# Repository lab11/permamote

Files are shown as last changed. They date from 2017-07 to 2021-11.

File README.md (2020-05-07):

Permamote
=========
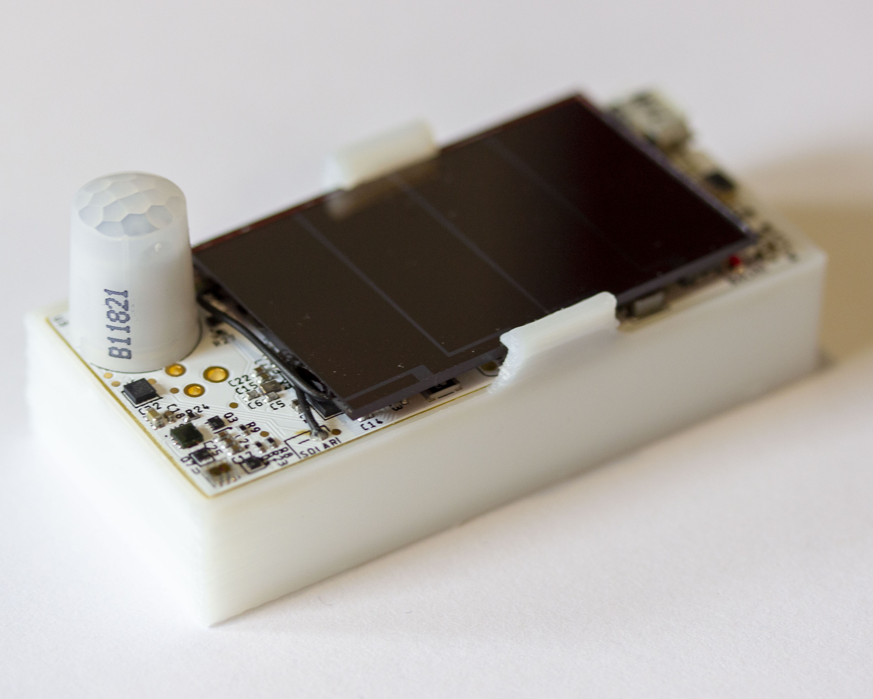
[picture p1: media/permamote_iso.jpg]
Permamote

An energy harvesting sensor mote with backing primary store and a lifetime of ≥10 years.
Permamote monitors temperature, humidity, pressure, light, light color, motion
(both PIR and with an accelerometer) and reports readings over BLE and
802.15.4/Thread.

Hardware
--------
The Permamote hardware is a small, 1 x 2.4 inch rectangular sensor board based
on the Nordic NRF52840 SoC, and the TI BQ25505 for power supply management and
energy harvesting.  Permamote also has an onboard RTC, the AB1815. The board
currently has 6 sensors:

1. Temperature and Humidity (Si7021)
2. Temperature and Pressure (MS5637)
3. Light (MAX44009)
4. Light Color (TCS34725)
5. PIR Motion (EKMB1101111)
6. Accelerometer (LIS2DW12)

The Permamote hardware is located in the [`hardware/permamote`](https://github.com/lab11/permamote/tree/master/hardware/permamote) directory, where you can find
the Eagle design files and case files.

Software
--------
The Permamote uses software located in the
[`software`](https://github.com/lab11/permamote/tree/master/software/).
directory. Follow the directions in the [nrf5x-base
Readme](https://github.com/lab11/nrf5x-base/tree/nrf52832#flash-an-application)
to get your machine set up to build and flash a Permamote.

The primary application is
[`software/apps/permamote_coap`](https://github.com/lab11/permamote/tree/master/software/apps/permamote_coap).
This application samples the
sensors and sends its data to a server running a
[coap-gateway](https://github.com/lab11/gateway/tree/thread/software/coap-gateway-mqtt)
over IP on a [Thread](https://github.com/openthread/openthread) network with a
[border router](https://github.com/openthread/borderrouter).
See the
[tutorial](https://github.com/lab11/permamote/tree/master/tutorial) to set up
your own OpenThread network.

Cloning
-------
To clone both this repository and the required submodules,
clone with the `--recurse-submodules` option:

```
git clone --recurse-submodules git@github.com:lab11/permamote.git
```

Otherwise, you can initialize the submodule and keep submodules up to
date by doing

```
git submodule update --init --recursive
```

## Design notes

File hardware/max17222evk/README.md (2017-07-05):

MAX17222 Evaluation Kit/Breakout Board
======================================

This maxim chip is a new and more efficient low power boost converter 
(80% @ < 10ua, Iq = 350na). 

We wanted an evaluation kit but none are in stock so this breakout will
serve as our evaluation kit.

We specifically want to evaluate boost efficiency, and metrics that might
allow us to use the boost converter for an iCount energy metering system.

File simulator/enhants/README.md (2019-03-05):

EnHANTs Dataset Processing
==========================

[Download](http://enhants.ee.columbia.edu/indoor-irradiance-meas) and place
measurement `.txt.` files in the `enhants_data` directory.

The `clean.py` script takes these energy traces, finds periods of missing data,
generates synthetic replacements to fill these holes, and saves them as
`.npy` objects in the `numpy_arrays` directory to be consumed by the simulator.

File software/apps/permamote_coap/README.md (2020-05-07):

Permamote Openthread COAP App
=============================

This is the default app for Permamote. It utilizes
[OpenThread](https://github.com/openthread/openthread) to establish data
backhaul over COAP and services such as NTP and DNS.
See the
[tutorial](https://github.com/lab11/permamote/tree/master/tutorial) to set up
your own OpenThread network.
This app periodically sends sensor data from the
light color, temperature,
humidity and pressure sensors. The light and motion sensor send when
changes are detected. The acceleratometer is currently not implemented. Thread
configuration, Sensor periods/backoffs, and COAP, NTP, and DNS endpoints, are
defined in
[config.h](https://github.com/lab11/permamote/blob/master/software/apps/permamote_coap/config.h).

This application is configured to use Nordic's [background
bootloader](
   https://infocenter.nordicsemi.com/topic/com.nordic.infocenter.sdk5.v15.3.0/lib_background_dfu.html
    ).
Before flashing this app, make sure to generate keys and place them in the [`software/boards/keys`](https://github.com/lab11/permamote/tree/master/software/boards/keys) directory.

To generate keys, follow Nordic's process [here](
    https://infocenter.nordicsemi.com/topic/com.nordic.infocenter.thread_zigbee.v3.0.0/thread_example_dfu.html
    ).
```
cd software/boards/keys
nrfutil keys generate private.pem
nrfutil keys display --key pk --format code private.pem --out_file public.c
```

Next, navigate to the [`permamote_coap`](https://github.com/lab11/permamote/tree/master/software/apps/permamote_coap) application and flash this app, with a device ID:
```
make flash ID=C0:98:E5:11:XX:XX
```
Replace XX:XX with your desired ID.

If you see a red LED turn on, this means the bootloader has successfully been
flashed but there is not yet a valid application installed. Check that you have
properly generated keys and that you hav e run `make clean` before flashing.

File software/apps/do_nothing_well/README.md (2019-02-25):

Do Nothing Well
===============

Turn off all sensors and enter sleep. Good for benchmarking minimum current.

As of Rev C, Permamote should have a sleep current at 1.3μA when supplying 3.3V
on the primary cell input.

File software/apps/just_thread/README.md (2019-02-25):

Permamote Thread Test
=====================

Test OpenThread on Permamote. Basically the `do_nothing_well` application, but
with OpenThread implemented as well.

Expected RTT output (`make rtt`) with a correctly configured OpenThread network should be similar to:
```
<info> app: Thread version: OPENTHREAD/20170716-01135-gedb7982f; NRF52840; Dec 11 2018 22:05:35
<info> app: Network name:   OpenThread
<info> app: Thread Channel: 25
<info> app: TX Power: 0 dBm
<info> app: Thread PANID: 0xFACE
<info> app: Thread interface has been enabled.
<info> app: 802.15.4 Channel: 25
<info> app: 802.15.4 PAN ID:  0xFACE
<info> app: rx-on-when-idle:  disabled
<info> app: State changed! Flags: 0x045F133D Current role: 1

<info> app: State changed! Flags: 0x000000E4 Current role: 2

<info> app: State changed! Flags: 0x00000200 Current role: 2

<info> app: State changed! Flags: 0x00000001 Current role: 2
```

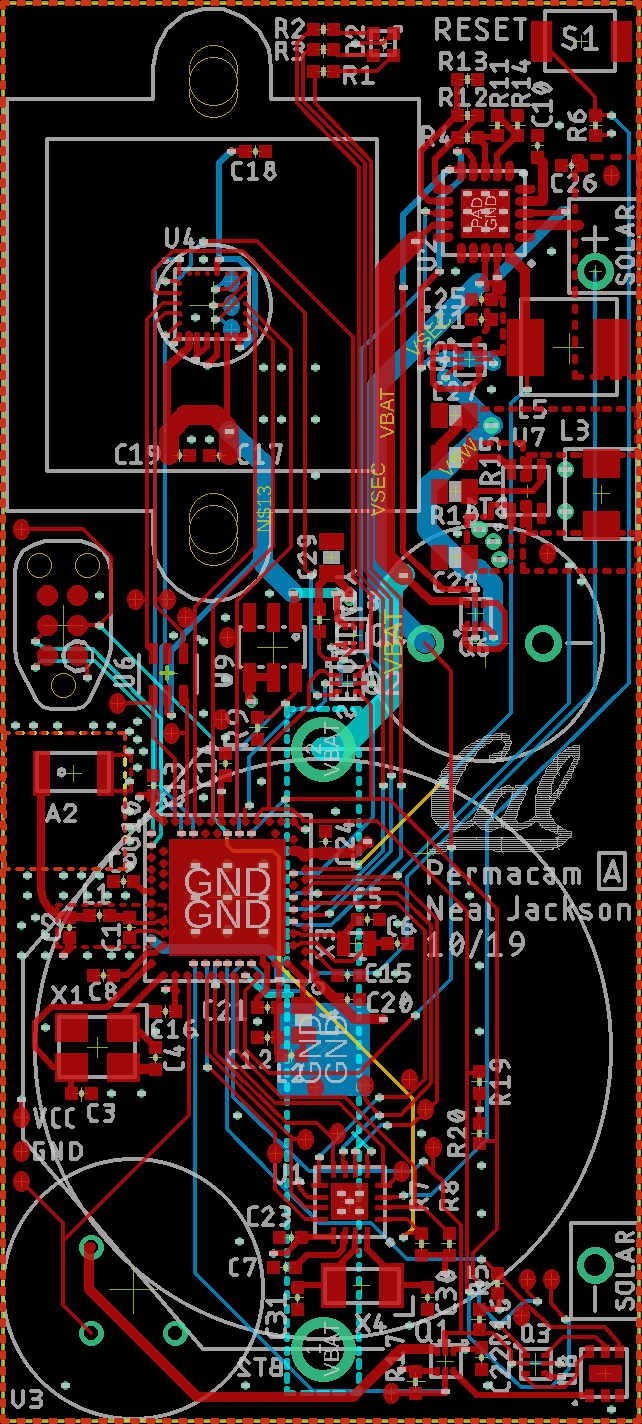
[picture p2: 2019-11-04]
hardware/permacam/rev_a/permacam_pcb.png

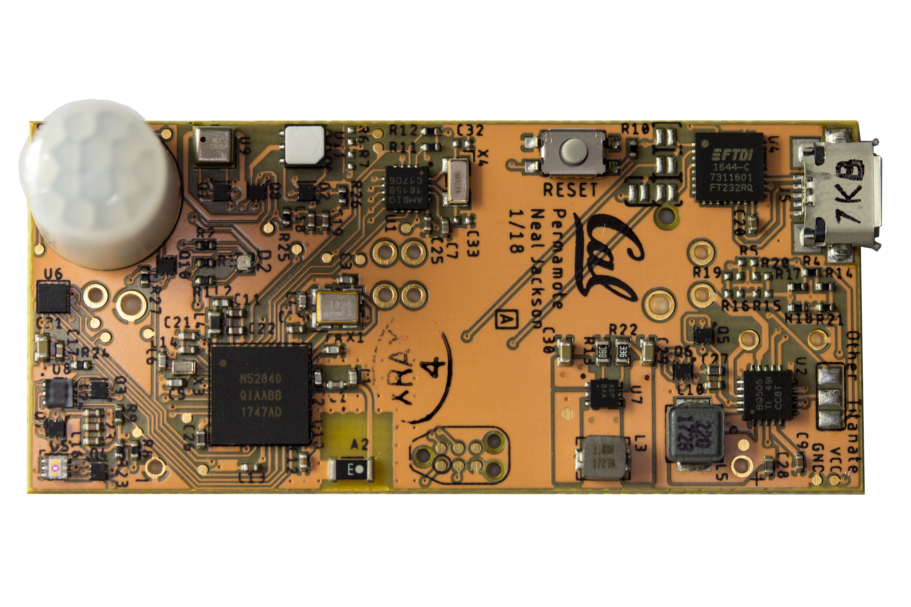
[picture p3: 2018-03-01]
media/permamote.jpg

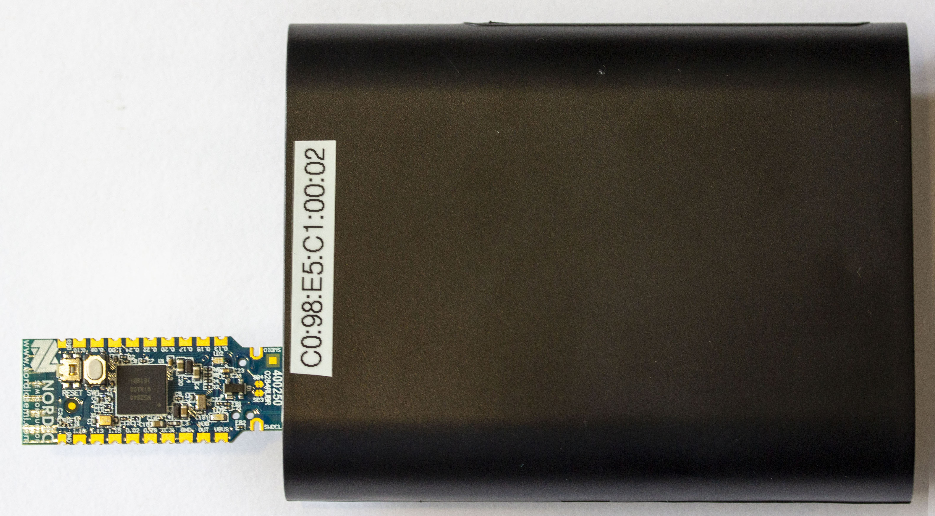
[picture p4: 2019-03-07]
media/border_router_straight.jpg

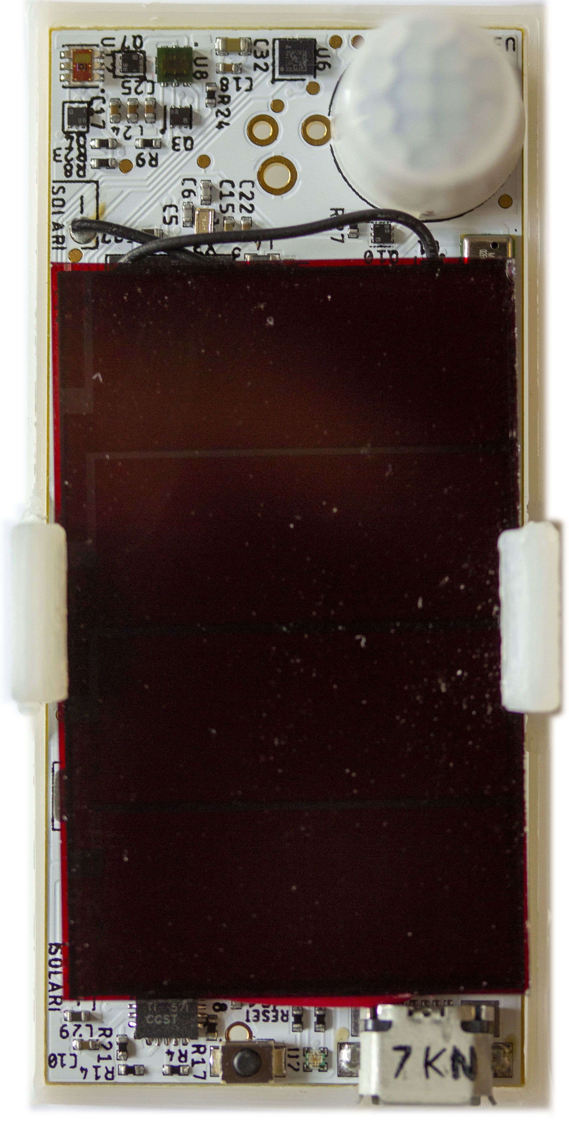
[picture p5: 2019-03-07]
media/permamote_straight.jpg

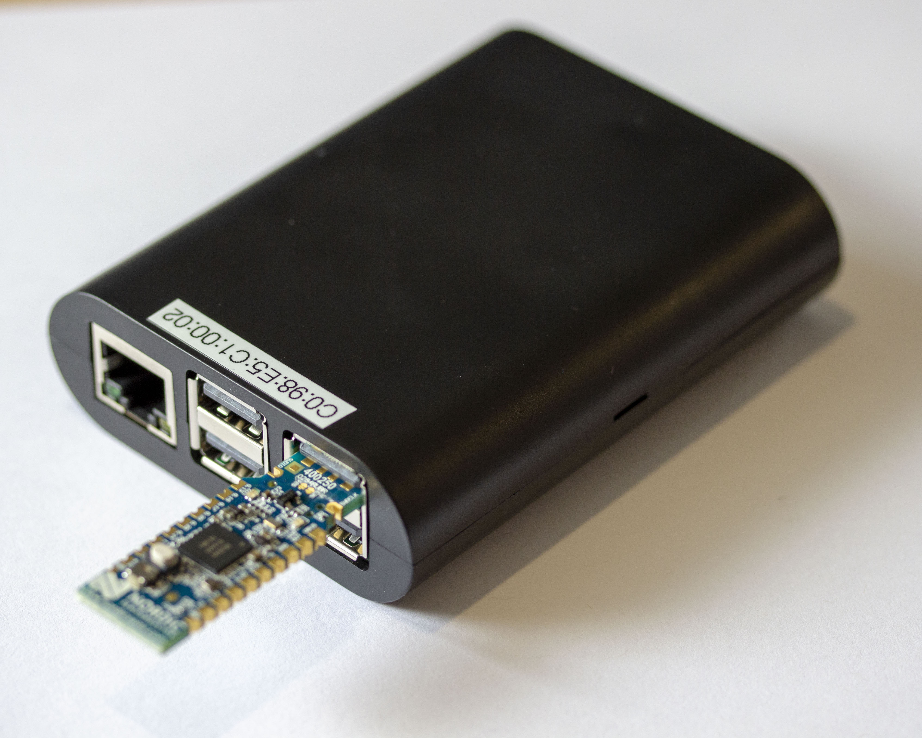
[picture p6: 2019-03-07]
media/border_router_iso.jpg

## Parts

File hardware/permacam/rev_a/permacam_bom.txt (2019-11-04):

# Bill of Materials
# Converted from permacam_bom.xlsx
# Generated by bom_to_text.py
#
# Bill of Materials                                                                                                                                                                                                                                                                                            
# Converted from {}                                                                                                                                                                                                                                                                                            
# Generated by bom_to_text.py                                                                                                                                                                                                                                                                                  
#                                                                                                                                                                                                                                                                                                              
                                                                                                                                                                                                                                                                                                               
Qty                            Value                  Device                 Package            Parts                              Description                                                                                                                        DIGIKEY             MPN                  Notes
7                              0.1uF                  CAPACITOR0402_CAP      0402_CAP           C13, C14, C15, C16, C17, C18, C19  SMD Capacitor                                                                                                                      490-6328-1-ND       GRM155R71C104KA88J   
3                              100M                   RESISTOR0402_RES       0402_RES           R16, R17, R18                      Resistor                                                                                                                           541-100MAHCT-ND     HMC0402JT100M        
1                              100k                   RESISTOR0402_RES       0402_RES           R9                                 Resistor                                                                                                                           311-100KJRCT-ND     RC0402JR-07100KL     
1                              100pF                  CAPACITOR0402_CAP      0402_CAP           C8                                 SMD Capacitor                                                                                                                      490-5922-1-ND       GRM1555C1H101JA01D   
4                              10k                    RESISTOR0402_RES       0402_RES           R5, R6, R7, R8                     Resistor                                                                                                                           311-10KJRCT-ND      RC0402JR-0710KL      
2                              10nF                   CAPACITOR0402_CAP      0402_CAP           C10, C11                           SMD Capacitor                                                                                                                      490-4516-1-ND       GRM155R71H103KA88D   
3                              10uF                   CAPACITOR0603_CAP      0603_CAP           C27, C28, C29                      SMD Capacitor                                                                                                                      490-3896-1-ND       GRM188R60J106ME47D   
1                              10uH                   INDUCTOR0603           0603_CAP           L4                                 A very specific inductor                                                                                                           490-4025-1-ND       LQM18FN100M00D       
4                              12pF                   CAPACITOR0402_CAP      0402_CAP           C3, C4, C5, C6                     SMD Capacitor                                                                                                                      490-6197-1-ND       GRM1555C1H120GA01D   
1                              15nH                   INDUCTOR0402           0402_CAP           L2                                 A very specific inductor                                                                                                           587-1521-1-ND       HK100515NJ-T         
2                              1pF                    CAPACITOR0402_CAP      0402_CAP           C1, C2                             SMD Capacitor                                                                                                                      1276-1595-1-ND      CL05C010CB5NNNC      
4                              1uF                    CAPACITOR0402_CAP      0402_CAP           C20, C21, C22, C23                 SMD Capacitor                                                                                                                      490-7195-1-ND       GRM155R70G105KA12D   
1                              1uH                    INDUCTORIHL            IHL-1212BZ-11      L3                                 A very specific inductor                                                                                                           541-1319-1-ND       IHLP1212BZER1R0M11   
1                              215k                   RESISTOR0603_RES       0603-RES           R10                                Resistor                                                                                                                           YAG3055CT-ND        RC0402FR-07215KL     
1                              22uH                   INDUCTOR74437324220    74437324220        L5                                 A very specific inductor                                                                                                           732-3340-1-ND       74437324220          
1                              2477THMCOINCELLCLIP    2477THMCOINCELLCLIP    2477THMCOINCLIP    BT2                                Battery clip for 2477 Coin Cell                                                                                                    BAT-HLD-001-THM-ND  BAT-HLD-001-THM      
1                              3.9M                   RESISTOR0402_RES       0402_RES           R11                                Resistor                                                                                                                           YAG3301CT-ND        RC0402JR-073M9L      
1                              3.9nH                  INDUCTOR0402           0402_CAP           L1                                 A very specific inductor                                                                                                           490-1131-1-ND       LQP15MN3N9B02D       
1                              32.768kHz              ABS05-32.768KHZ-9-T    ABS05              X3                                 32.768kHz Crystal                                                                                                                  535-11897-1-ND      ABS05-32.768KHZ-9-T  
1                              32MHz                  7V-32.000MAHV-T        TXC-7V             X1                                 TXC CRYSTAL SMD                                                                                                                    887-2568-1-ND       7M-32.000MAHV-T      
1                              33M                    RESISTOR0603_RES       0603-RES           R15                                Resistor                                                                                                                           HMC0603JT33M0CT-ND  HMC0603JT33M0        
3                              4.7uF                  CAPACITOR0402_CAP      0402_CAP           C24, C25, C26                      SMD Capacitor                                                                                                                      445-5947-1-ND       C1005X5R0J475K050BC  
3                              470                    RESISTOR0402_RES       0402_RES           R1, R2, R3                         Resistor                                                                                                                           311-470JRCT-ND      RC0402JR-07470RL     
1                              47nF                   CAPACITOR0402_CAP      0402_CAP           C12                                SMD Capacitor                                                                                                                      445-1264-1-ND       C1005X7R1C473K050BC  
1                              47pF                   CAPACITOR0402_CAP      0402_CAP           C7                                 SMD Capacitor                                                                                                                      490-5942-1-ND       GRM1555C1H470JA01D   
1                              6.04k                  RESISTOR0402_RES       0402_RES           R4                                 Resistor                                                                                                                           YAG2293CT-ND        RC0402FR-076K04L     
1                              6.2M                   RESISTOR0402_RES       0402_RES           R12                                Resistor                                                                                                                           YAG3309CT-ND        RC0402JR-076M2L      
1                              6.8M                   RESISTOR0402_RES       0402_RES           R13                                Resistor                                                                                                                           YAG3310CT-ND        RC0402JR-076M8L      
1                              820pF                  CAPACITOR0402_CAP      0402_CAP           C9                                 SMD Capacitor                                                                                                                      1276-6535-1-ND      CL05B821KO5NNNC      
1                              9.1M                   RESISTOR0402_RES       0402_RES           R14                                Resistor                                                                                                                           YAG3322CT-ND        RC0402JR-079M1L      
1                              AB1815-T3              AB1815-T3              QFN-16-3MM         U1                                 Ultra-low current RTC. 55nA quiescent @ 3V. 1.5-3.6V input.                                                                        535-11936-1-ND      AB1815-T3            
1                              ABS07-32.768KHZ-7-T    ABS07-32.768KHZ-7-T    2-SMD              X4                                 32.768kHz Crystal                                                                                                                  535-9543-1-ND       ABS07-32.768KHZ-7-T  
1                              ANT3216A063R2400A      ANT3216A063R2400A      ANT3216A063R2400A  A2                                 Yageo 2.4GHz                                                                                                                       311-1542-1-ND       ANT3216A063R2400A    
1                              B3U-1000P              B3U-1000P              B3U-1000P          S1                                 Switch                                                                                                                             SW1020CT-ND         B3U-1000P            
1                              BQ25505                BQ25505                S-PVQFN-N20-RGR    U2                                 EH front end for switching between primary and secondary cells                                                                     296-37078-1-ND      BQ25505RGRR          
2                              DNP                    CAPACITOR0402_CAP      0402_CAP           C30, C31                           SMD Capacitor                                                                                                                                                               Do not populate
2                              DNP                    RESISTOR0402_RES       0402_RES           R19, R20                           Resistor                                                                                                                                                                    Do not populate
1                              EKMB1101111            EKMB1101111            AMN2               U3                                 Passive infrared human detection sensor with built-in amp.                                                                         255-3065-ND         EKMB1101111          
1                              HM01B0-ANA             HM01B0-ANA             NEOPAC-26          U4                                 ultra low power CMOS Image Sensor 320 x 320                                                                                                            HM01B0-ANA           Consigned part
1                              LTOHTC1020             LTOHTC1020             1020               BT1                                                                                                                                                                                                            Do not populate
1                              MAX17222               MAX17222               UDFN-6-MAXIM       U7                                 Very high efficiency, very low power boost converter suitable for EH applications                                                  MAX17222ELT+TCT-ND  MAX17222ELT+T        
1                              MAX44009               MAX44009               UDFN-6-EXPOSED     U8                                 low power ambient light sensor                                                                                                     MAX44009EDT+TCT-ND  MAX44009EDT+T        
1                              NRF52840               NRF52840               AQFN73             U10                                ultra-low power 2.4 GHz wireless system on chip (SoC) integrating a multiprotocol 2.4 GHz transceiver, an ARM¬Æ Cortex¬Æ-M4F CPU.  1490-1071-1-ND      NRF52840             
6                              PMDXB950UPEL           PMDXB950UPEL           XDFN-6             Q1, Q2, Q3, Q4, Q5, Q6             20 V 500mA, dual P-channel Trench MOSFET                                                                                           1727-2601-1-ND      PMDXB950UPELZ        
1                              SML-LX0404SIUPGUSB     SML-LX0404SIUPGUSB     1MM_SQ_4PAD        D2                                 1mm^2 RGB LED                                                                                                                      67-2125-1-ND        SML-LX0404SIUPGUSB   
1                              SN74AUP2G04DCKRDCK6-L  SN74AUP2G04DCKRDCK6-L  DCK6-L             U6                                                                                                                                                                                        SN74AUP2G04DCKR      
1                              SOLARCELLHOLES         SOLARCELLHOLES         SOLAR_HOLES        D1                                 Generic solar cell                                                                                                                 869-1001-ND         AM-1454CA            
1                              TPS22860               TPS22860               SOT-23-6           U9                                 Ultra-Low Leakage Load Switch                                                                                                      296-43982-1-ND      TPS22860DBVR         Do not populate
=SUM(A2:A49)

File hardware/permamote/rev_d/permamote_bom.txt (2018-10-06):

# Bill of Materials
# Converted from permamote_bom.xlsx
# Generated by bom_to_text.py
#
# # Bill of Materials                                                                                                                                                                                                                                                                                                                                                                                                                            
# # Converted from {}                                                                                                                                                                                                                                                                                                                                                                                                                            
# # Generated by bom_to_text.py                                                                                                                                                                                                                                                                                                                                                                                                                  
# #                                                                                                                                                                                                                                                                                                                                                                                                                                              
#                                                                                                                                                                                                                                                                                                                                                                                                                                                
# Qty                            Value                              Device                             Package                            Parts                                        Description                                                                                                                      DIGIKEY             MANUFACTURER           MF  MOUSER               MPN                  NEWARK   OC_FARNELL  OC_NEWARK  Notes
9                                0.1uF                              CAPACITOR0402_CAP                  0402_CAP                           C13, C14, C15, C16, C17, C18, C19, C20, C21  SMD Capacitor                                                                                                                    490-6328-1-ND                                                       GRM155R71C104KA88J                                   
5                                100M                               RESISTOR0402_RES                   0402_RES                           R23, R24, R25, R26, R27                      Resistor                                                                                                                         HMC0402JT100MCT-ND                                                  HMC0402JT100M                                        
1                                100pF                              CAPACITOR0402_CAP                  0402_CAP                           C8                                           SMD Capacitor                                                                                                                    490-5922-1-ND                                                       GRM1555C1H101JA01D                                   
5                                10k                                RESISTOR0402_RES                   0402_RES                           R8, R9, R10, R11, R12                        Resistor                                                                                                                         311-10KJRCT-ND                                                      RC0402JR-0710KL                                      
2                                10nF                               CAPACITOR0402_CAP                  0402_CAP                           C10, C11                                     SMD Capacitor                                                                                                                    490-4516-1-ND                                                       GRM155R71H103KA88D                                   
3                                10uF                               CAPACITOR0603_CAP                  0603_CAP                           C30, C31, C32                                SMD Capacitor                                                                                                                    490-3896-1-ND                                                       GRM188R60J106ME47D                                   
1                                10uH                               INDUCTOR0603                       0603_CAP                           L4                                           A very specific inductor                                                                                                         490-4025-1-ND                                                       LQM18FN100M00D                                       
4                                12pF                               CAPACITOR0402_CAP                  0402_CAP                           C3, C4, C5, C6                               SMD Capacitor                                                                                                                    490-6197-1-ND                                                       GRM1555C1H120GA01D                                   
1                                15nH                               INDUCTOR0402                       0402_CAP                           L2                                           A very specific inductor                                                                                                         587-1521-1-ND                                                       HK100515NJ-T                                         
2                                1pF                                CAPACITOR0402_CAP                  0402_CAP                           C1, C2                                       SMD Capacitor                                                                                                                    1276-1595-1-ND                                                      CL05C010CB5NNNC                                      
5                                1uF                                CAPACITOR0402_CAP                  0402_CAP                           C22, C23, C24, C25, C26                      SMD Capacitor                                                                                                                    490-7195-1-ND                                                       GRM155R70G105KA12D                                   
1                                1uH                                INDUCTORIHL                        IHL-1212BZ-11                      L3                                           A very specific inductor                                                                                                         541-1319-1-ND       Vishay Dale                                     IHLP1212BZER1R0M11                                   
1                                22uH                               INDUCTOR74437324220                74437324220                        L5                                           A very specific inductor                                                                                                         732-3340-1-ND                                                       74437324220                                          
1                                3.9M                               RESISTOR0402_RES                   0402_RES                           R14                                          Resistor                                                                                                                         YAG3301CT-ND                                                        RC0402JR-073M9L                                      
1                                3.9nH                              INDUCTOR0402                       0402_CAP                           L1                                           A very specific inductor                                                                                                         490-1131-1-ND                                                       LQP15MN3N9B02D                                       
1                                32.768kHz                          ABS05-32.768KHZ-9-T                ABS05                              X3                                           32.768kHz Crystal                                                                                                                535-11897-1-ND      Abracon                                         ABS05-32.768KHZ-9-T                                  
1                                32MHz                              7V-32.000MAHV-T                    TXC-7V                             X1                                           TXC CRYSTAL SMD                                                                                                                  887-2568-1-ND       TXC CORPORATION                                 7M-32.000MAHV-T                                      
1                                33M                                RESISTOR0603_RES                   0603-RES                           R22                                          Resistor                                                                                                                         HMC0603JT33M0CT-ND                                                  HMC0603JT33M0                                        
3                                4.7uF                              CAPACITOR0402_CAP                  0402_CAP                           C27, C28, C29                                SMD Capacitor                                                                                                                    445-5947-1-ND                                                       C1005X5R0J475K050BC                                  
3                                470                                RESISTOR0402_RES                   0402_RES                           R1, R2, R3                                   Resistor                                                                                                                         311-470JRCT-ND                                                      RC0402JR-07470RL                                     
1                                47nF                               CAPACITOR0402_CAP                  0402_CAP                           C12                                          SMD Capacitor                                                                                                                    445-1264-1-ND                                                       C1005X7R1C473K050BC                                  
1                                47pF                               CAPACITOR0402_CAP                  0402_CAP                           C7                                           SMD Capacitor                                                                                                                    490-5942-1-ND                                                       GRM1555C1H470JA01D                                   
1                                6.04k                              RESISTOR0402_RES                   0402_RES                           R4                                           Resistor                                                                                                                         YAG2293CT-ND                                                        RC0402FR-076K04L                                     
1                                6.2M                               RESISTOR0402_RES                   0402_RES                           R17                                          Resistor                                                                                                                         YAG3309CT-ND                                                        RC0402JR-076M2L                                      
1                                6.8M                               RESISTOR0402_RES                   0402_RES                           R18                                          Resistor                                                                                                                         YAG3310CT-ND                                                        RC0402JR-076M8L                                      
1                                80.6k                              RESISTOR0603_RES                   0603-RES                           R13                                          Resistor                                                                                                                         311-80.6KHRCT-ND                                                    RC0603FR-0780K6L                                     
1                                820pF                              CAPACITOR0402_CAP                  0402_CAP                           C9                                           SMD Capacitor                                                                                                                    1276-6535-1-ND                                                      CL05B821KO5NNNC                                      
1                                9.1M                               RESISTOR0402_RES                   0402_RES                           R21                                          Resistor                                                                                                                         YAG3322CT-ND                                                        RC0402JR-079M1L                                      
1                                AB1815-T3                          AB1815-T3                          QFN-16-3MM                         U1                                           Ultra-low current RTC. 55nA quiescent @ 3V. 1.5-3.6V input.                                                                      535-11936-1-ND      Abracon                                         AB1815-T3                                            
1                                ABS07-32.768KHZ-7-T                ABS07-32.768KHZ-7-T                2-SMD                              X4                                           32.768kHz Crystal                                                                                                                535-9543-1-ND       ABRACON                                         ABS07-32.768KHZ-7-T                                  
1                                ANT3216A063R2400A                  ANT3216A063R2400A                  ANT3216A063R2400A                  A2                                           Yageo 2.4GHz                                                                                                                     311-1542-1-ND       YAGEO                                           ANT3216A063R2400A                                    
2                                BAT-HLD-002-THM                    BAT-HLD-002-THM                    BAT-HLD-002-THM                    BT2, BT3                                     RETAINER BATT CR2016 PC PINS                                                                                                     BAT-HLD-001-THM-ND                             712-BAT-HLD-001-THM  BAT-HLD-001-THM                                      Only populate half of boards. When populating: place solder on ground pads before soldering clips, add kapton tape over CR123A PACK + hole.
1                                BAT_PACKCR123A                     BAT_PACKCR123A                     BH123A                             BT4                                          collection of battery footprints                                                                                                 BH123A-ND           MPD                                             BH123A                                               DNP
1                                BQ25505                            BQ25505                            S-PVQFN-N20-RGR                    U2                                           EH front end for switching between primary and secondary cells                                                                   296-37078-1-ND      TI                                              BQ25505RGRR                                          
2                                DNP                                CAPACITOR0402_CAP                  0402_CAP                           C33, C34                                     SMD Capacitor                                                                                                                                                                                                                                             DNP
2                                DNP                                RESISTOR0402_RES                   0402_RES                           R6, R7                                       Resistor                                                                                                                         311-10KJRCT-ND                                                      RC0402JR-0710KL                                      DNP
1                                EKMB1101111                        EKMB1101111                        AMN2                               U3                                           Passive infrared human detection sensor with built-in amp.                                                                       255-3065-ND         PANASONIC                                       EKMB1101111                                          
1                                B3U-1000P                          B3U-1000P                          B3U-1000P                          S1                                           SWITCH TACTILE                                                                                                                   SW1020CT-ND                                                         B3U-1000P                                            
1                                FT232RQ                            FT232RQ                            QFN32                              U4                                           Source: http://www.ftdichip.com/Documents/DataSheets/DS_FT232R_v104.pdf                                                                                                                              FT232RQ                       1146033     91K9919    
1                                LIS2DW12                           LIS2DW12                           LGA-12                             U6                                           ultra low power 3 axis accelerometer                                                                                                                 STMicroelectronics         511-LIS2DW12TR       LIS2DW12TR                                           
1                                LTOHTC1020                         LTOHTC1020                         1020                               BT1                                                                                                                                                                                                                                                                                                    DNP
1                                MAX17222                           MAX17222                           UDFN-6-MAXIM                       U7                                           Very high efficiency, very low power boost converter suitable for EH applications                                                MAX17222ELT+TCT-ND  MAXIM INTEGRATED                                MAX17222ELT+T                                        
1                                MAX44009                           MAX44009                           UDFN-6-EXPOSED                     U8                                           low power ambient light sensor                                                                                                   MAX44009EDT+TCT-ND  MAXIM                                           MAX44009EDT+T                                        
1                                MICRO_USB_B_HIROSE_ZX62R-B-5P(30)  MICRO_USB_B_HIROSE_ZX62R-B-5P(30)  MICRO_USB_B_HIROSE_ZX62R-B-5P(30)  J5                                           USB Micro B Connector                                                                                                            H125274CT-ND                                   798-ZX62R-B-5P30     ZX62R-B-5P(30)       84Y6712                         
1                                MS5637-02BA03                      MS5637-02BA03                      4-SMD                              U9                                           low power pressure sensor                                                                                                        223-1199-1-ND       TE CONNECTIVITY                                 MS563702BA03-50                                      
1                                NRF52840                           NRF52840                           AQFN73                             U10                                          ultra-low power 2.4 GHz wireless system on chip (SoC) integrating a multiprotocol 2.4 GHz transceiver, an ARM® Cortex®-M4F CPU.  1490-1071-1-ND      NORIDIC SEMICONDUCTOR                           NRF52840                                             
9                                PMDXB950UPEL                       PMDXB950UPEL                       XDFN-6                             Q1, Q2, Q3, Q4, Q5, Q6, Q7, Q8, Q10          20 V 500mA, dual P-channel Trench MOSFET                                                                                         1727-2601-1-ND      NEXPERIA                                        PMDXB950UPELZ                                        
1                                SI7021-A20-GM1                     SI7021-A20-GM1                     DFN-6/3MM                          U11                                          IC TEMP SENSOR RH 2% DFN                                                                                                         336-3141-ND                                    634-SI7021-A20-GM1   SI7021-A20-GM1                                       
1                                SML-LX0404SIUPGUSB                 SML-LX0404SIUPGUSB                 1MM_SQ_4PAD                        D2                                           1mm^2 RGB LED                                                                                                                    67-2125-1-ND        Lumex Opto                                      SML-LX0404SIUPGUSB                                   
1                                SOLARCELLHOLES                     SOLARCELLHOLES                     SOLAR_HOLES                        D1                                           Generic solar cell                                                                                                               869-1001-ND                                                         AM-1454CA                                            
1                                TCS34725                           TCS34725                           FN-6                               U12                                          Color Light-to-Digital Converter with IR Filter                                                                                  TCS34725FNCT-ND                                                     TCS34725FN

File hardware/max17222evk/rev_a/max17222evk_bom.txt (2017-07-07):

# Bill of Materials
# Converted from max17222evk_bom.xlsx
# Generated by bom_to_text.py
#
# # Bill of Materials                                                                                                                                                                                                                                                                          
# # Converted from {}                                                                                                                                                                                                                                                                          
# # Generated by bom_to_text.py                                                                                                                                                                                                                                                                
# #                                                                                                                                                                                                                                                                                            
#                                                                                                                                                                                                                                                                                              
# Qty                            Value               Device              Package                Parts                                                Description                                                                        DIGIKEY             MANUFACTURER      MANUFACTURER_PN  NEWARK
2                                                    M023.5MM            SCREWTERMINAL-3.5MM-2  J1, J2                                               Header 2                                                                           277-1721-ND                                            
4                                10uF                CAPACITOR0603_CAP   0603_CAP               C1, C2, C3, C4                                       SMD Capacitor                                                                      490-3896-2-ND                                          
1                                1uH                 INDUCTORDFE322512C  DFE322512C             L2                                                   A very specific inductor                                                           490-10590-1-ND                                         
1                                1uH                 INDUCTORIHL2525CZ   IHL-2525CZ             L1                                                   A very specific inductor                                                           541-2562-1-ND                                          
2                                33M                 RESISTOR0603_RES    0603-RES               R3, R4                                               Resistor                                                                           HMC0603JT33M0CT-ND                                     
2                                80.6k               RESISTOR0603_RES    0603-RES               R1, R2                                               Resistor                                                                           311-80.6KHRCT-ND                                       
2                                MAX17222            MAX17222            UDFN-6-MAXIM           U1, U2                                               Very high efficiency, very low power boost converter suitable for EH applications  MAX17222ELT+TCT-ND  MAXIM INTEGRATED  MAX17222ELT+T    
10                               TEST_POINT_0.040IN  TEST_POINT_0.040IN  TESTPOINT_0.040IN      TP3, TP4, TP5, TP6, TP7, TP8, TP9, TP10, TP13, TP14  0.040in Test Point                                                                 5001K-ND                                               
4                                TEST_POINT_0.112IN  TEST_POINT_0.112IN  TESTPOINT_0.112IN      TP1, TP2, TP11, TP12                                 Solder terminal, turreted                                                          36-1519-2-ND                                           40F6015
2                                TE_SSA12/SPDT       TE_SSA12/SPDT       TE_SSA12/SPDT          S1, S2                                               SWITCH SLIDE SPDT 2POS SSA SER                                                     450-1602-ND

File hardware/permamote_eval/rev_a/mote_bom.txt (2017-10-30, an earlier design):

# Bill of Materials
# Converted from mote_bom.xlsx
# Generated by bom_to_text.py
#
# # Bill of Materials                                                                                                                                                                                                                                                                                                                                                                                                                                                                                                                                                                                                                                                                                                                                                    
# # Converted from {}
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

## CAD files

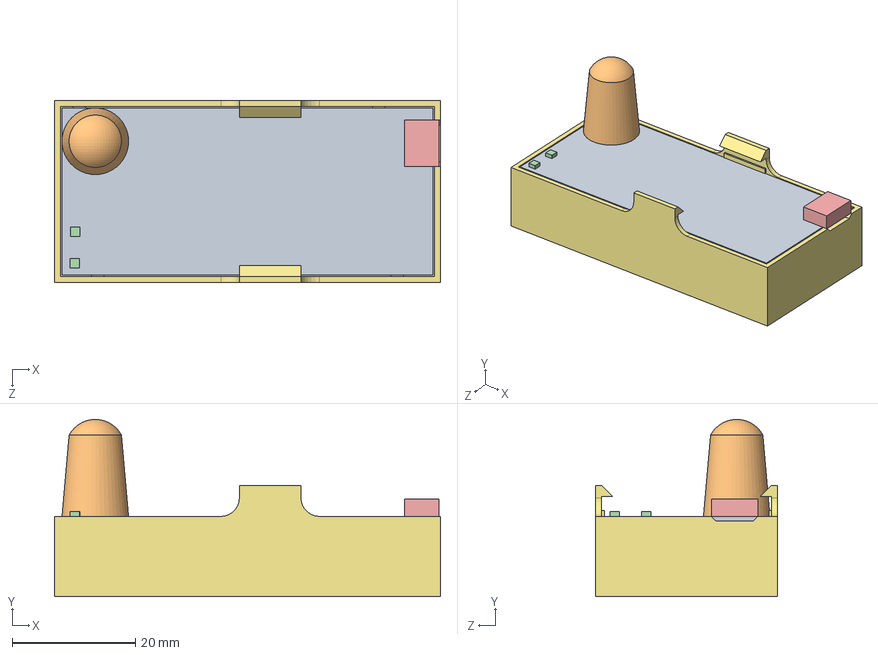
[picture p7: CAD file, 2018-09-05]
hardware/permamote/case/permamote.SLDASM
62.6 x 28.7 x 29.6 mm
pcb
PIR
battery x 2
IC x 2
usb
secondary
case_top

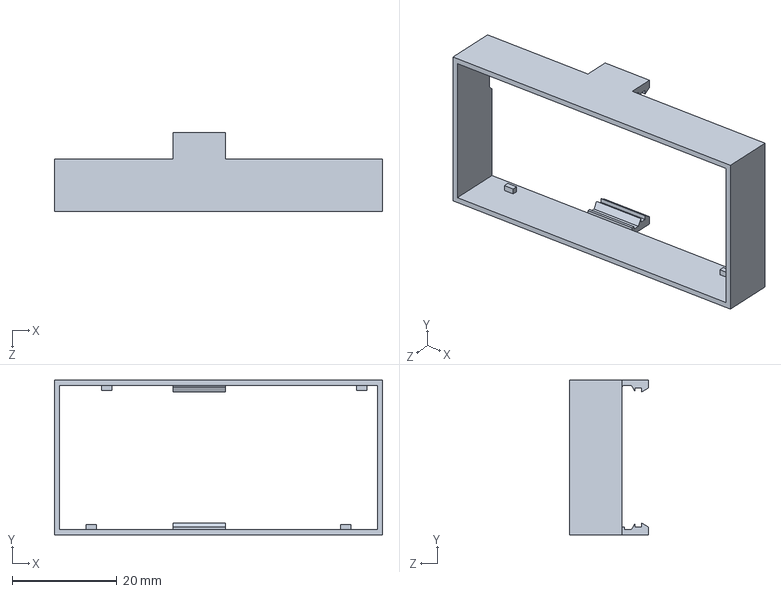
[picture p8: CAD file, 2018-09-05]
hardware/permamote/case/case_top.SLDPRT
62.6 x 29.6 x 15.0 mm

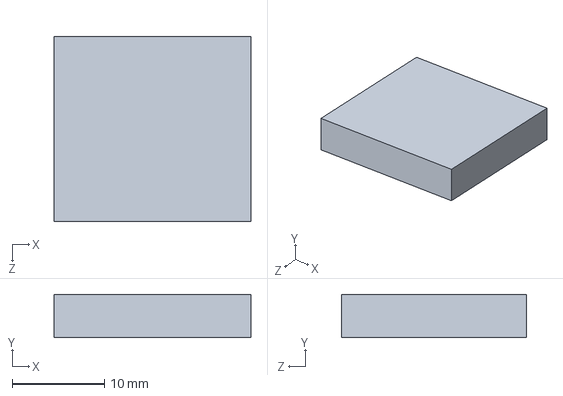
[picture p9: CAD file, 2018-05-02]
hardware/permamote/case/battery.SLDPRT
21.3 x 4.67 x 20.0 mm

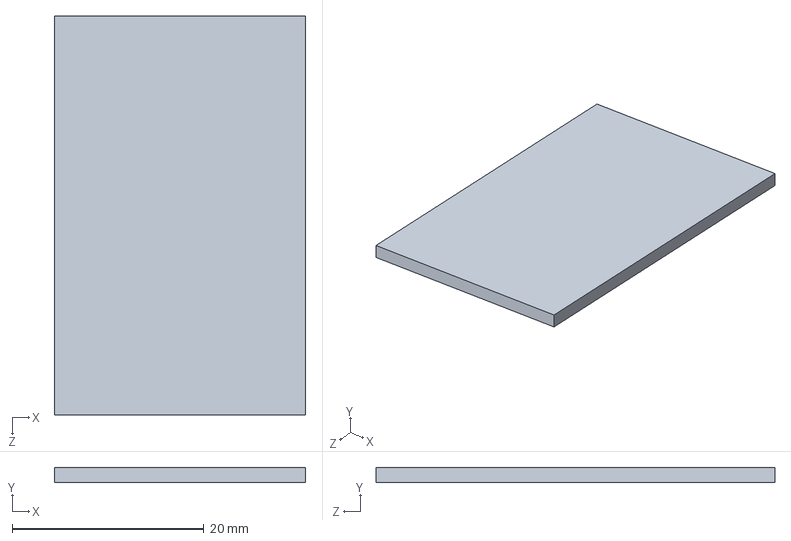
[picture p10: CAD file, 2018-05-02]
hardware/permamote/case/solar_panel.SLDPRT
26.2 x 1.60 x 41.7 mm

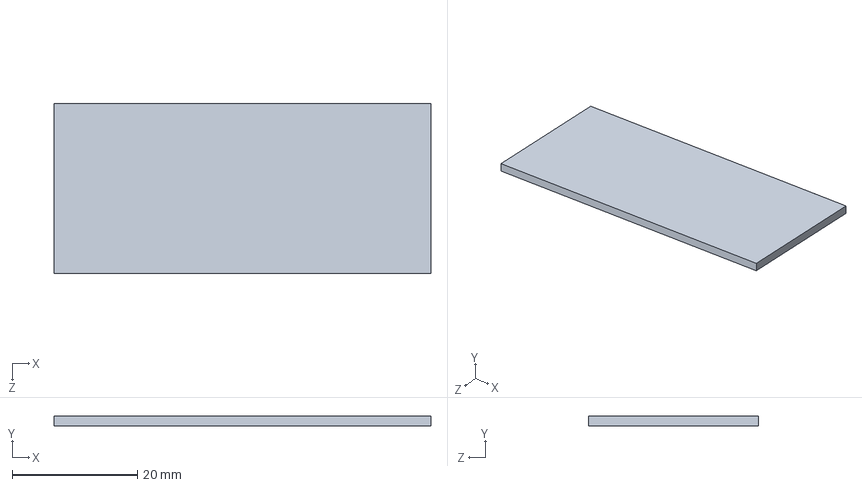
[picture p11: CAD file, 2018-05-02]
hardware/permamote/case/pcb.SLDPRT
60.1 x 1.59 x 27.1 mm

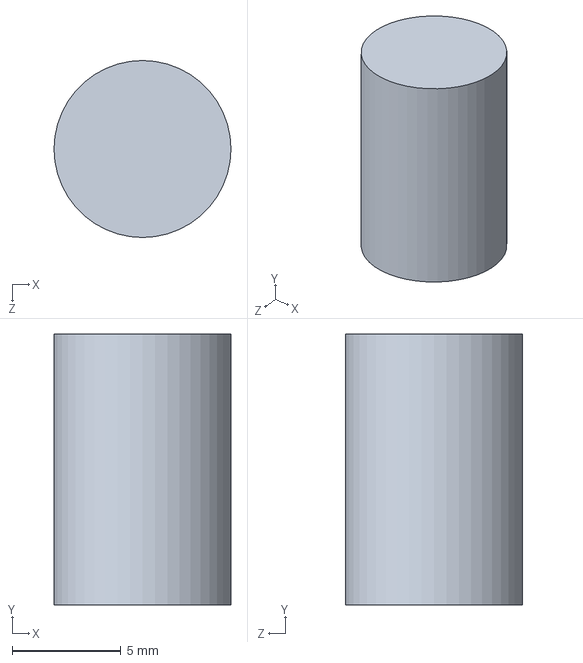
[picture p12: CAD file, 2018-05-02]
hardware/permamote/case/secondary.SLDPRT
8.13 x 12.4 x 8.13 mm

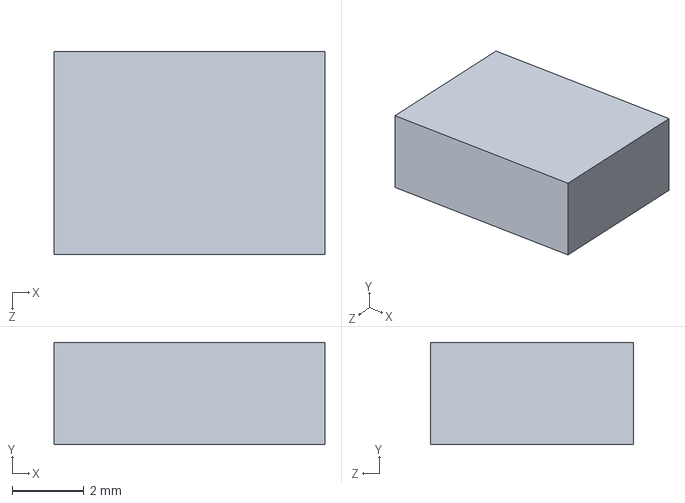
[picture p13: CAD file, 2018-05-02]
hardware/permamote/case/usb.SLDPRT
7.54 x 2.84 x 5.64 mm

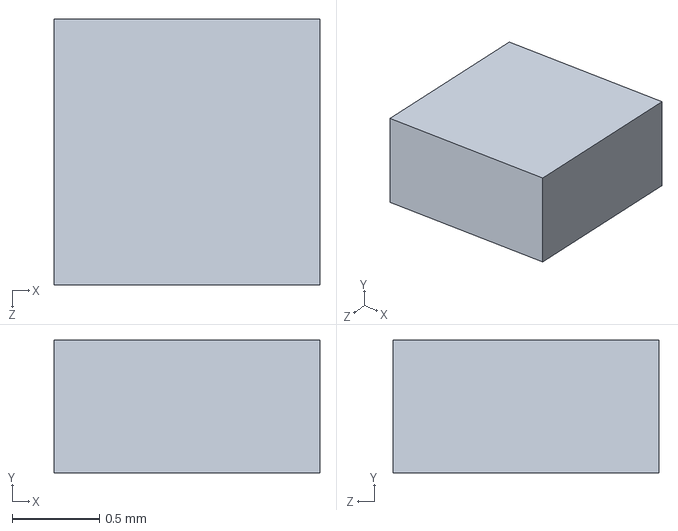
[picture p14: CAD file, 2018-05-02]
hardware/permamote/case/IC.SLDPRT
1.52 x 0.762 x 1.52 mm

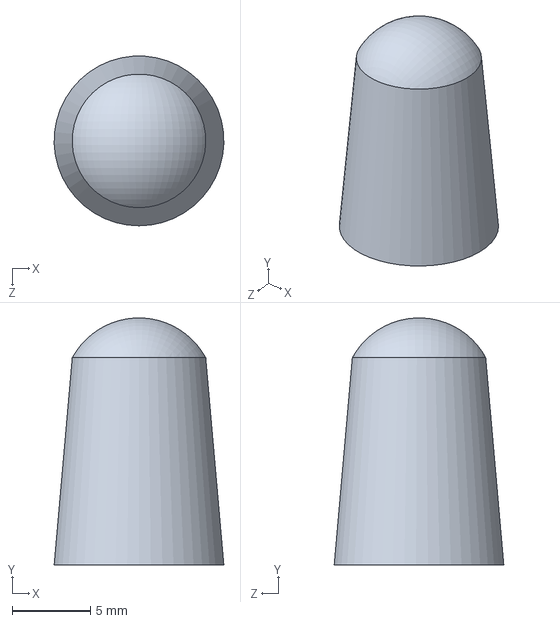
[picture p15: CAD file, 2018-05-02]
hardware/permamote/case/PIR.SLDPRT
10.8 x 15.7 x 10.8 mm

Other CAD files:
hardware/permamote/case/case_top.STL

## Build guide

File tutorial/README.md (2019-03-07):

So you want to deploy some Peramamotes?
=======================================

First, you will need to deploy some infrastructure. Permamamotes currently
depend on  [Thread](https://www.threadgroup.org/What-is-Thread), a 6LoWPAN
802.15.4 mesh networking protocol. So before you deploy Permamotes, you need to
set up a Thread network. Luckily, the [OpenThread](https://openthread.io/)
project offers many open source, prebuilt parts of this network.

A Thread sensor network connected to the greater internet is minimally composed
of two devices: a [Border Router](https://github.com/openthread/borderrouter)
and a sensor. A Thread Border Router is a special type of Router in a Thread
network. In addition to performing the normal mesh routing tasks, it also
advertises itself as a gateway for traffic destined for outside the Thread
network. Other routers and devices in the network recognize this, and forward
IP datagrams pointing outside the Thread network to the Border Router. Sensors
are "Sleepy End Devices", meaning they don't participate in routing, spend most
of their time in a low power state, and just send and receive data packets.

## Border Router

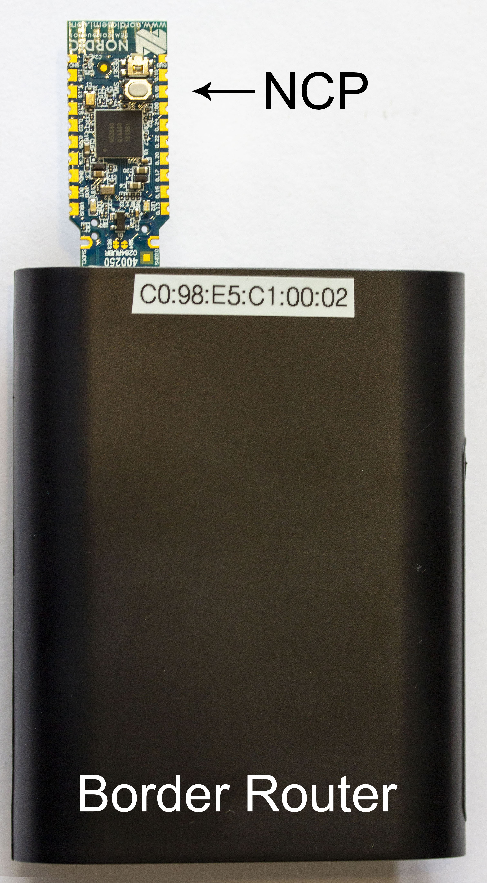
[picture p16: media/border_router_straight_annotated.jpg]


So the first step towards building a network of Permamotes is to build and
deploy a Border Router. A Border Router consists of a Linux class device (e.g.
Raspberry Pi) to perform IPv6/4 routing and DNS, and a Network Co-Processor (NCP), a Thread-capable
MCU
([NRF52840
 Dongle](https://www.digikey.com/product-detail/en/nordic-semiconductor-asa/NRF52840-DONGLE/1490-1073-ND/9491124))
to interface with the Thread Network.  We also supply a prebuilt Border Router
image for an Raspberry Pi B+ and directions to set it up
[here](https://github.com/lab11/otbr).  While it is not recommended, you can
build one from scratch following the directions
[here](https://github.com/openthread/borderrouter).  When you have a working
Border Router, connect it to an Ethernet or WiFi network, and ensure you have
SSH access.

To easily SSH to a Border Router supplied by us, or built using our image, make
sure your computer and Border Router are on the same local network, and use the
`.local` MDNS hostname:
```
ssh pi@tb-c098e5c1XXXX.local
```
Where `XXXX` is the ID specific to your Border Router. If supplied by us, this
ID is printed on the case. If you built it using the directions
[here](https://github.com/lab11/otbr), you should have chosen an ID during
setup. The default password for the `pi` user on our image is `lab11otbr!`.

After successfully logging into your new Border Router, while optional, it is
good practice to **change the password**. Better yet, [disable SSH password
access](https://stackoverflow.com/questions/20898384/ssh-disable-password-authentication)
and [generate and install your public key](https://serverfault.com/questions/2429/how-do-you-setup-ssh-to-authenticate-using-keys-instead-of-a-username-password)
on the Border Router.

Next, check the status of the Border Router's Thread connection. This can be done
by checking [`wpantund`](https://github.com/openthread/wpantund), the userspace
driver to the NCP, with `wpanctl`, the command line interface to `wpantund`.
To check the status, run the following command:
```
sudo wpanctl status
```
You should get output like one of the following:
#### Unintialized
```
wpan0 => [
	"NCP:State" => "uninitialized:fault"
	"Daemon:Enabled" => true
	"NCP:Version" => ""
	"Daemon:Version" => "0.08.00d (/8e6a5cf; Dec 14 2018 00:54:48)"
	"Config:NCP:DriverName" => "spinel"
	"NCP:HardwareAddress" => [0000000000000000]
]
```
If the NCP is **uninitialized**, Ensure that the NCP USB Dongle is correctly inserted in the Border Router, and
try resetting it:
```
sudo wpanctl reset
```
or the Border Router:
```
sudo reboot
```
If this is not resolved, the NCP may be programmed incorrectly. The directions
to program can be found [here](https://github.com/lab11/otbr).
#### Offline
```
wpan0 => [
	"NCP:State" => "offline"
	"Daemon:Enabled" => true
	"NCP:Version" => "OPENTHREAD/20170716-01135-gedb7982f; NRF52840; Mar  5 2019 16:34:14"
	"Daemon:Version" => "0.08.00d (/8e6a5cf; Dec 14 2018 00:54:48)"
	"Config:NCP:DriverName" => "spinel"
	"NCP:HardwareAddress" => [9D9A0E96C4A99F45]
]
```
If the NCP is **offline**, and you just turned on the Border Router and
signed in, wait a minute or two for the boot and initialization process to
complete. If after some time the NCP is still offline, attempt to reinitialize
the network with:
```
sudo systemctl restart otbr-init
```
#### Associated
```wpan0 => [
	"NCP:State" => "associated"
	"Daemon:Enabled" => true
	"NCP:Version" => "OPENTHREAD/20170716-01135-gedb7982f; NRF52840; Mar  5 2019 16:34:14"
	"Daemon:Version" => "0.08.00d (/8e6a5cf; Dec 14 2018 00:54:48)"
	"Config:NCP:DriverName" => "spinel"
	"NCP:HardwareAddress" => [EA4923D858B4802C]
	"NCP:Channel" => 25
	"Network:NodeType" => "leader"
	"Network:Name" => "OpenThread"
	"Network:XPANID" => 0xDEAD00BEEF00CAFE
	"Network:PANID" => 0xFACE
	"IPv6:LinkLocalAddress" => "fe80::f8ad:49f4:5791:c279"
	"IPv6:MeshLocalAddress" => "fdf7:b63c:cbe7:0:76ae:2c0b:5374:1fbf"
	"IPv6:MeshLocalPrefix" => "fdf7:b63c:cbe7::/64"
	"com.nestlabs.internal:Network:AllowingJoin" => false
]
```
If the NCP is **associated**, this means the Border Router has successfully
formed (or joined) a Thread network. Congratulations!

Three parameters minimally define a Thread network: the 802.15.4 Channel, the
PAN ID, and the Master Key.  If you would like to change these network
parameters, edit `~/otbr/software/otbr-init ` to change them.
Reset the init service to enact the changes:
```
sudo systemctl restart otbr-init
```
Note that any changes in these three parameters will make the Border Router's
Thread network incompatible with any devices using previous parameters. If you
change parameters on the Border Router, you must also change them for all
devices on your Thread network.

## Permamote

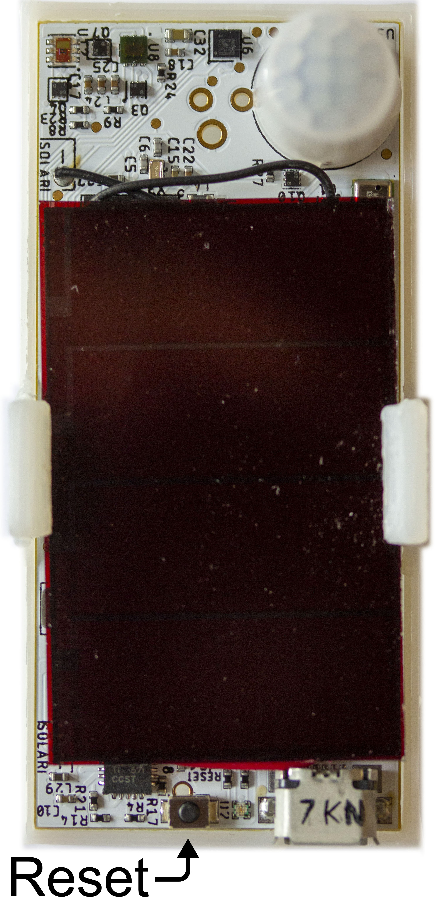
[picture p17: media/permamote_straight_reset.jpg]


Now that we have a functioning Thread network, now it is time to
[program](https://github.com/lab11/permamote/tree/master/software/apps/permamote_coap)
(if needed) and deploy sensors. If the sensors are already flashed with the
correct software, just hit the sensor reset button to restart the sensor and
quickly join the deployed network.

To confirm that your sensors have connected to the Thread network and are
successfully having their data forwarded by the Border Router, perform a
`tcpdump` of the `wpan0` interface on the Border Router:
```
sudo tcpdump -i wpan0 -vv
```
Try covering the sensor with your hand to generate light and motion data.
You should see traffic similar to the following:
```
00:47:53.964132 IP6 (hlim 64, next-header UDP (17) payload length: 43) fd11:22::2126:e996:a4a3:6049.49153 > 64:ff9b::22da:2eb5.5683: [udp sum ok] UDP, length 35
00:47:54.571889 IP6 (hlim 64, next-header UDP (17) payload length: 49) fd11:22::2126:e996:a4a3:6049.49153 > 64:ff9b::22da:2eb5.5683: [udp sum ok] UDP, length 41
...
```
If your Thread network is configured with non-default network parameters, be
sure to [change
these](https://github.com/lab11/permamote/blob/master/software/apps/permamote_coap/main.c#L625),
and reprogram your Permamotes.

## Optional Additional Routers



If you find that you need to extend the range of your Thread network to reach a
larger deployment, you can deploy additional Thread routers. Routers are similar to the
Border Router, but only route packets within the Thread network and
essentially serve as range extenders for the Thread mesh network. See
[OpenThread
documentation](https://openthread.io/guides/thread-primer/node-roles-and-types)
for more information about node roles and types. Any Thread-capable MCU can
serve as a router, including the same NRF52840 dongles
that we use as the NCP for our Border Router. To flash an NRF52840 dongle with
thread router software, plug the dongle into your computer, hit the reset
button, and:
```
cd ../software/nrfx-base/apps/thread/thread_router/
make usb_dfu
```
This should result in a flashed router that can be plugged into any 5V USB
plug. If your thread network uses different parameters than default, make sure
to change these in [`thread_dongle/main.c`](https://github.com/lab11/nrf5x-base/blob/nrf52832/apps/thread/thread_router/main.c#L91) before programming.

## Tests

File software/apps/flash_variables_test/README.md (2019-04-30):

`flash_storage` is a library that acts as a wrapper for Nordic's `fds` library. It enables the assignment of variables in the main flow of a program on Permamote while simultaneously storing those variables' values in non-volatile memory. When Permamote is reset and the assignment statements are executed again, their results can change if the variables in non-volatile memory have been updated in the interim.

An example of `flash_storage` usage is below. Here, `flash_storage` functions are used to initialize an integer variable, update the value of that variable in non-volatile memory, and then re-initialize that variable with its new value.

First, this block of code is executed on Permamote:

```c
flash_storage_init();
uint16_t x_id = 0x1111; // arbitrary ID
int x = define_flash_variable_int(-1017, x_id);
printf("%d\n", x); // Prints -1017
```

Then, this line of code is executed on Permamote:

```c
flash_update_int(x_id, 1206);
```

Finally, Permamote is reset, and the first block of code runs again.

```c
int x = define_flash_variable_int(-1017, x_id);
printf("%d\n", x); // Prints 1206 instead of -1017
```

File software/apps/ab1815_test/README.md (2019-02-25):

AB1819 RTC Test
===============

Test basic functions of the RTC.

This app sets the time and reads and prints the time every 5 seconds.

RTT output (`make rtt`) should be similar to:
```
RTC TEST
21:04:14, 8/16/2018
21:04:19, 8/16/2018
21:04:24, 8/16/2018
...
```

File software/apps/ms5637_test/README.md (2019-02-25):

MS5637 Temperature/Pressure Test
===============

Test basic functions of the temperature/pressure sensor.

This app reads and prints the temperature and pressure every 5 seconds.

RTT output (`make rtt`) should be similar to:
```
TEMP/PRESSURE TEST
temperature: 21.370001, pressure: 999.419983
temperature: 21.379999, pressure: 999.530029
temperature: 21.379999, pressure: 999.419983
...
```

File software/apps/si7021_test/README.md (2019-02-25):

SI7021 Temperature/Humidity Test
===============

Test basic functions of the temperature/humidity sensor.

This app reads and prints the temperature and humidity every 5 seconds.

RTT output (`make rtt`) should be similar to:
```
TEMP/HUMIDITY TEST
humidity: 42.431396, temperature: 21.511772
humidity: 42.431396, temperature: 21.490322
humidity: 42.461914, temperature: 21.490322
...
```

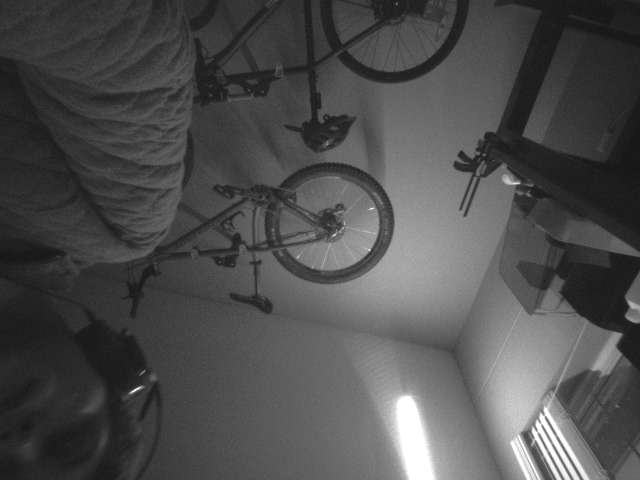
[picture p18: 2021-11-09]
software/apps/permacam/spi_peripheral_test/test.jpg

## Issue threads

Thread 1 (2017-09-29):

Node Design Issues

adkinsjd, 2017-09-29:
- [x] Check to see if SWDIO needs to be tied RST
 - [x] Add ADC to VSW
 - [x] Switch power gating fets.
 - [x] Put decoupling caps before fets
 - [x] Add pullup to sensor supply on intersil part
 - [x] Add pullup to sensor on maxim4009
 - [x] Look into PIR output as an analog signal
 - [x] Add gating FETs on the I2C pins
 - [x] Wire up DC-DC on the nrf52840
 - [ ] Look into power story for clean supply on decawave

Closed 2018-04-26.

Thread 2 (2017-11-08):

Hardware Bugs

nealjack, 2017-11-08:
- [ ] Fix up cream layer
- [ ] !I2C_EN and !ACC_EN no longer actual signals
- [ ] Add FTDI->USB
- [ ] C17 and R24 (and friends) wrong package

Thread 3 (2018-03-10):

Rev_A Fixes

adkinsjd, 2018-03-10:
- [x] Silk labels for Secondary Cell and its polarity
 - [x] Silk labels for primary cell
 - [x] silk labels for solar panel and polarity
 - [x] Connect LBST to NRF for incoming energy measurement

nealjack, 2018-03-10:
There are already silk labels for the solar panel, primary, and secondary cell. The secondary silk is on the back of the board. The solar input is on the front, but admittedly pretty obscured by things around it. The primary silkscreen is also hard to distinguish.

nealjack, 2018-07-16:
- [ ] Update RF passives to newer spec

Closed 2018-10-06.

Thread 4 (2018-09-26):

Rev_B Issues

adkinsjd, 2018-09-26:
- [ ] A better reset button (just so you don't forget)

nealjack, 2018-09-26:
Might as well add a power switch too

On Wed, Sep 26, 2018, 9:54 AM Joshua Adkins <notifications@github.com>
wrote:

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

adkinsjd, 2018-09-26:
Hmm I don't know about this for the same reasons we didn't add one to
Signpost

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

nealjack, 2018-09-26:
The only reason would be that if the programmer had previously been set up
for debugging/rtt, it puts the NRF52840 into a high power state that can
only be disabled by a power reset or resetting the programmer and
reflashing.

On Wed, Sep 26, 2018, 11:07 AM Joshua Adkins <notifications@github.com>
wrote:

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

Closed 2018-10-06.

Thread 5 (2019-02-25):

Rev_C Fixes

nealjack, 2019-02-25:
- [ ] Battery/button spacing is non-ideal

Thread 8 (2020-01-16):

Permacam Rev A fixes

nealjack, 2020-01-16:
-  Disconnect EXTI from GND

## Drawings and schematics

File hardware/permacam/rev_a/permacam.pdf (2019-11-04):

# NRF52840

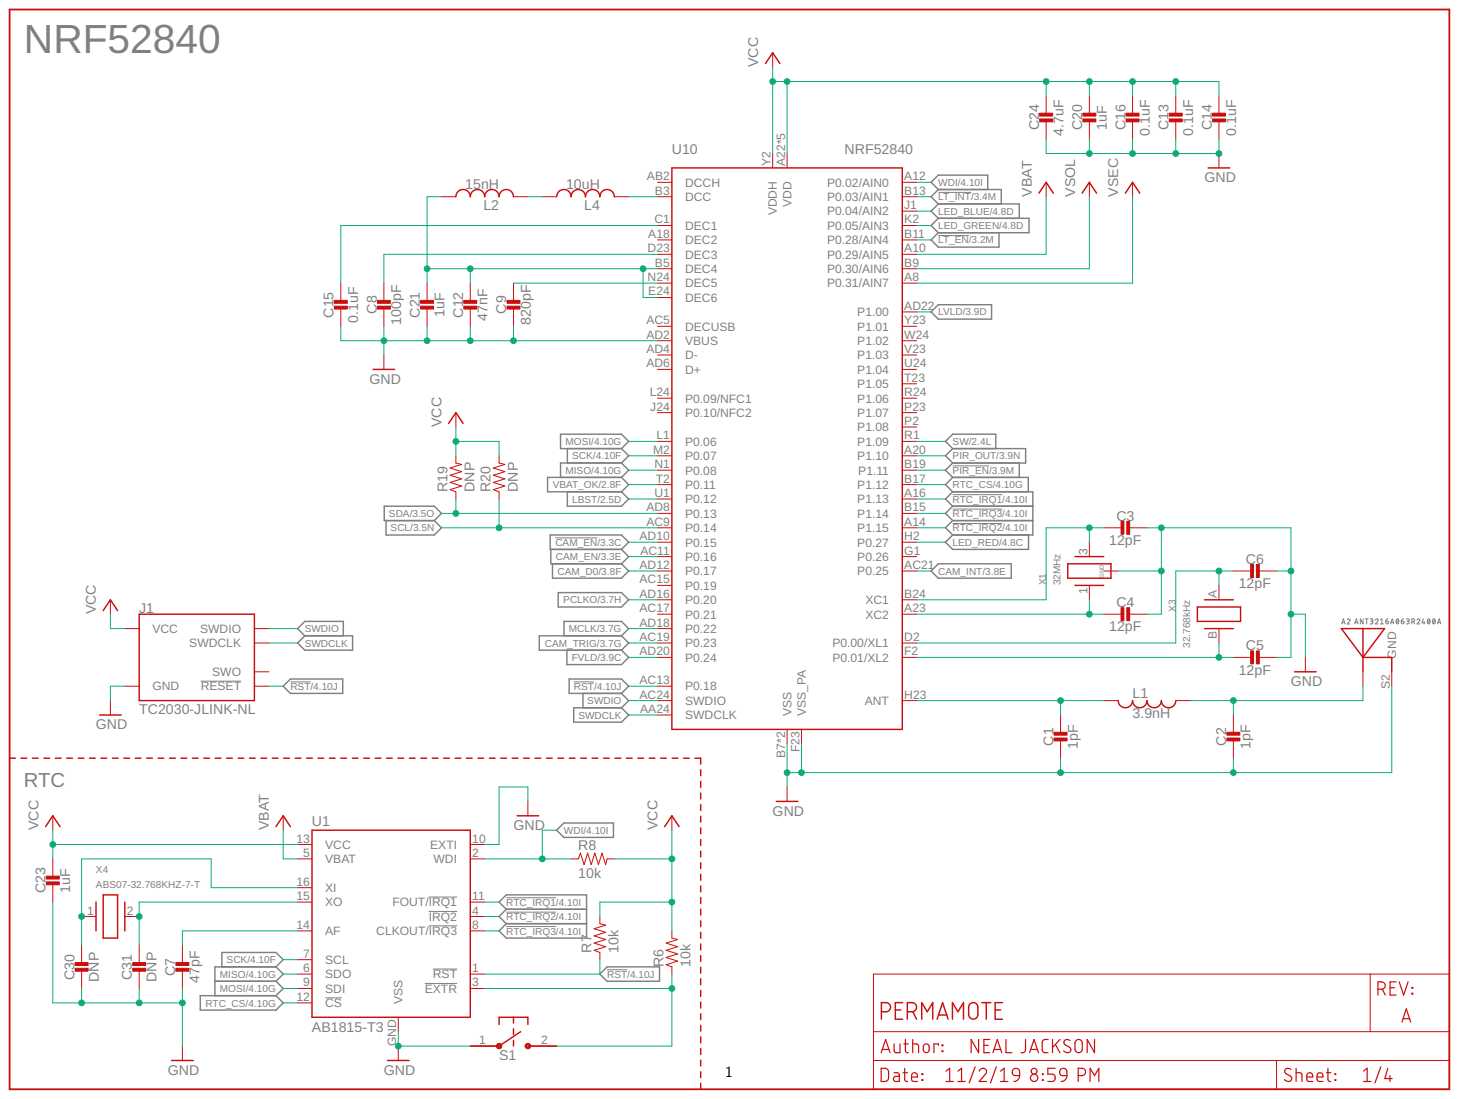
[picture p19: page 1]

# Power Supply

+

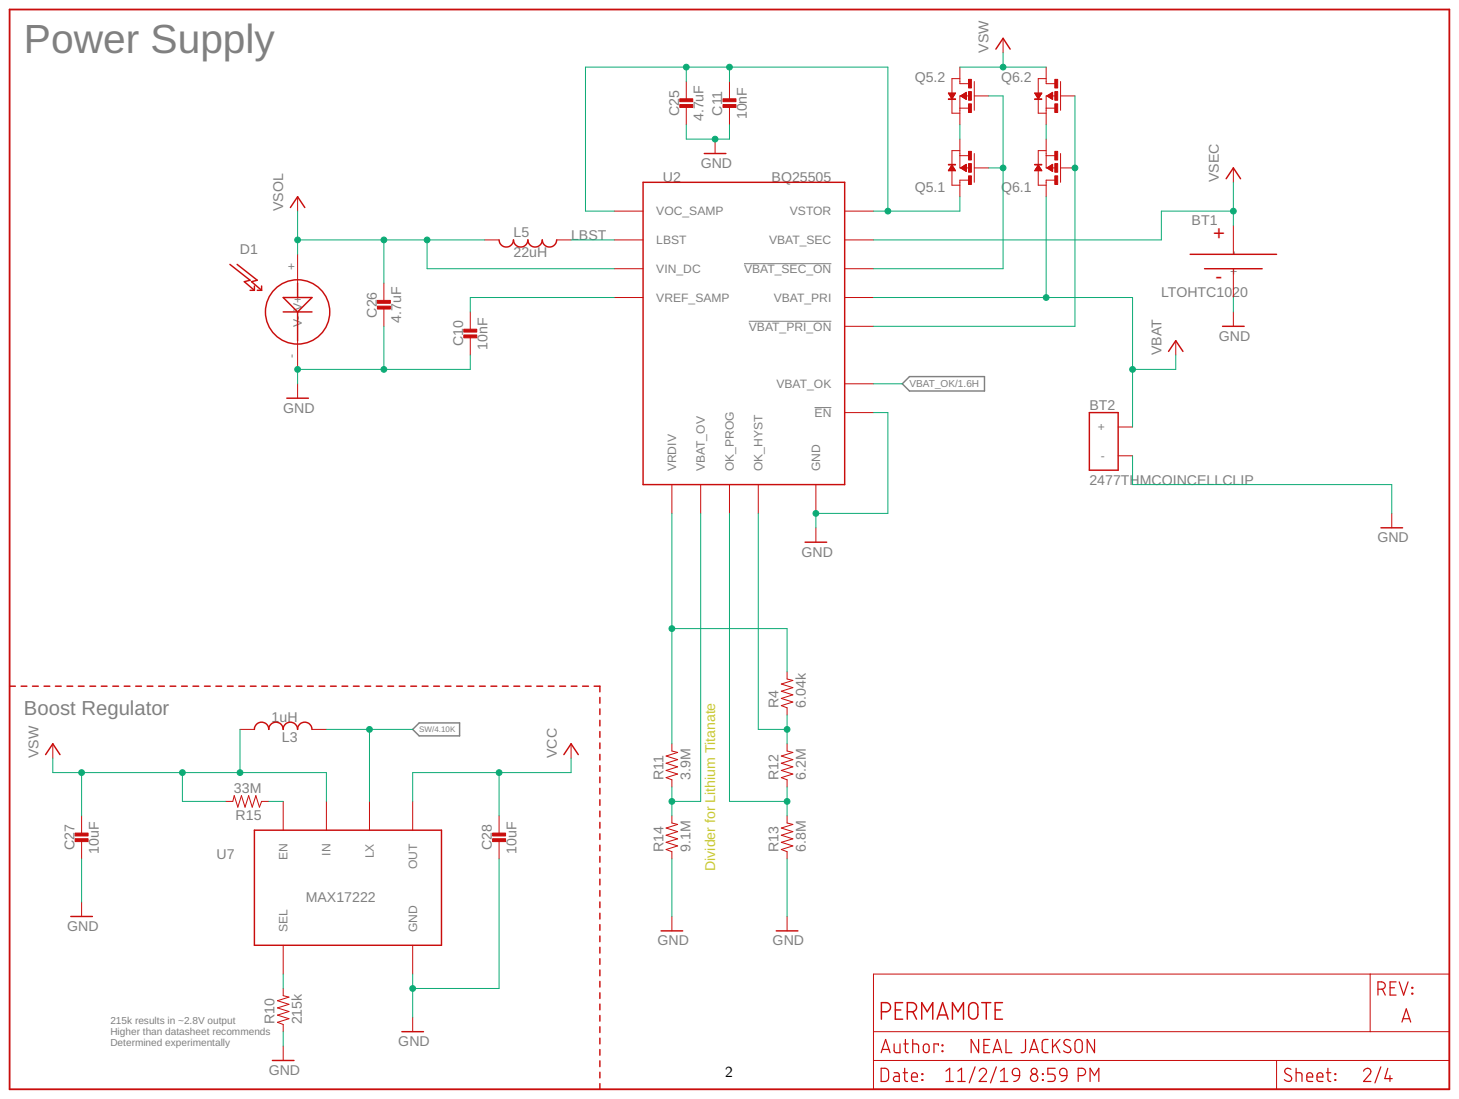
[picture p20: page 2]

Divider for Lithium Titanate

215k results in ~2.8V output Higher than datasheet recommends Determined experimentally

# Sensors

## Camera

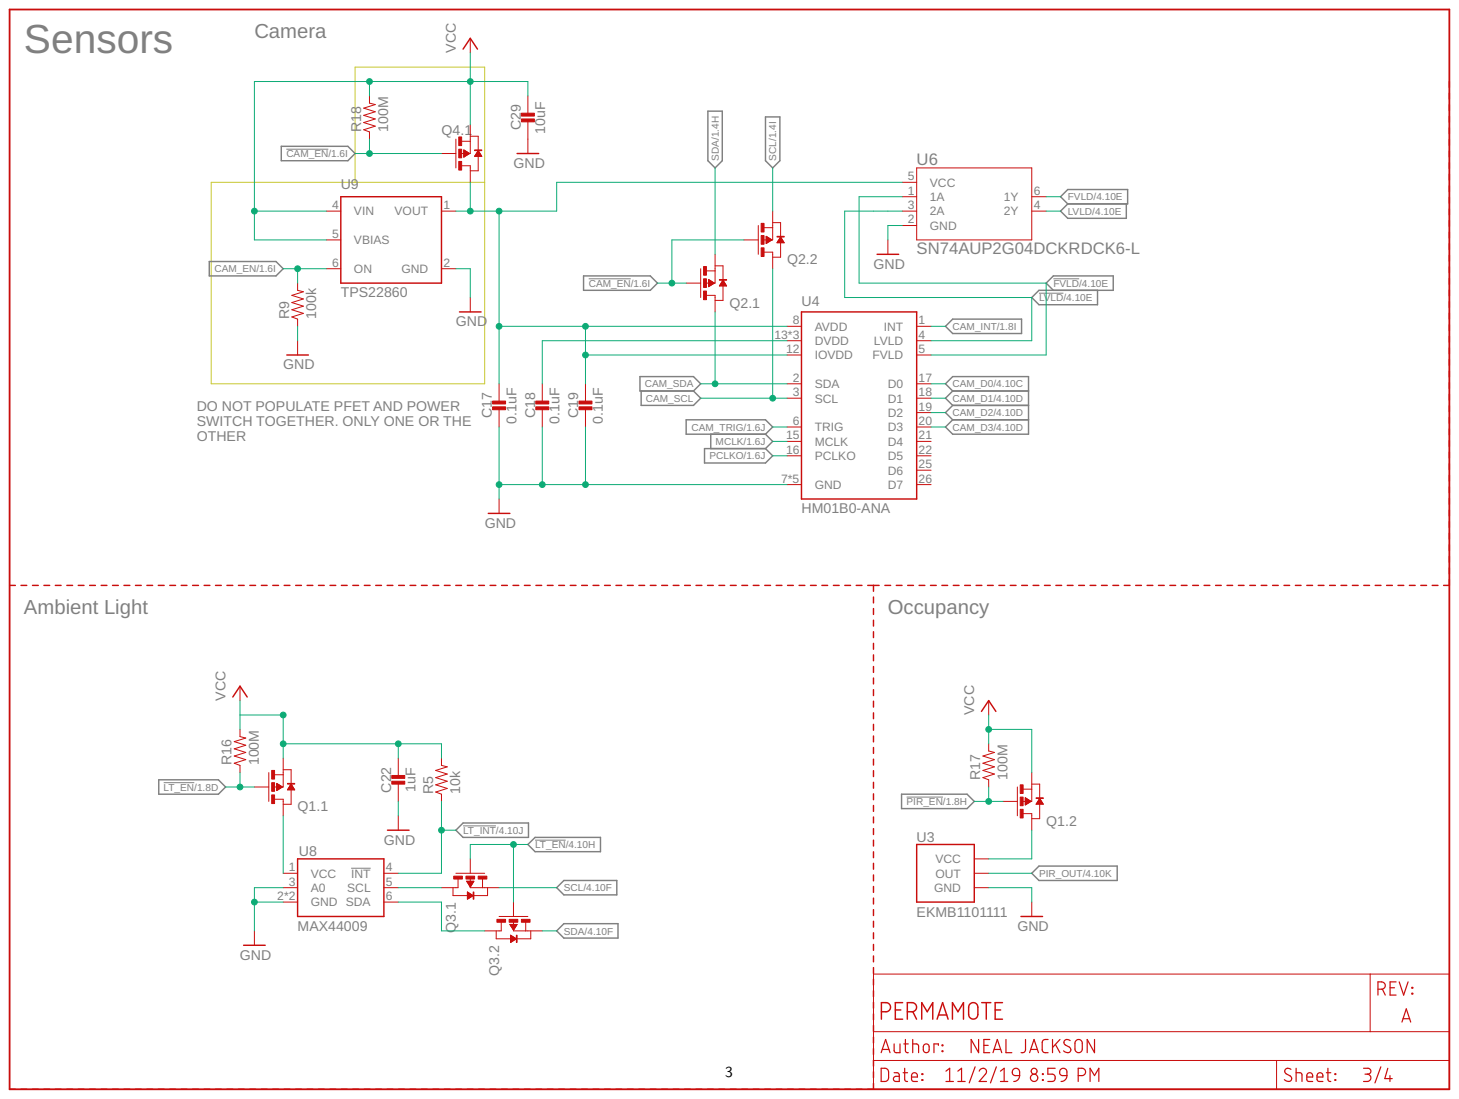
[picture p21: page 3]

DO NOT POPULATE PFET AND POWER
SWITCH TOGETHER. ONLY ONE OR THE
OTHER

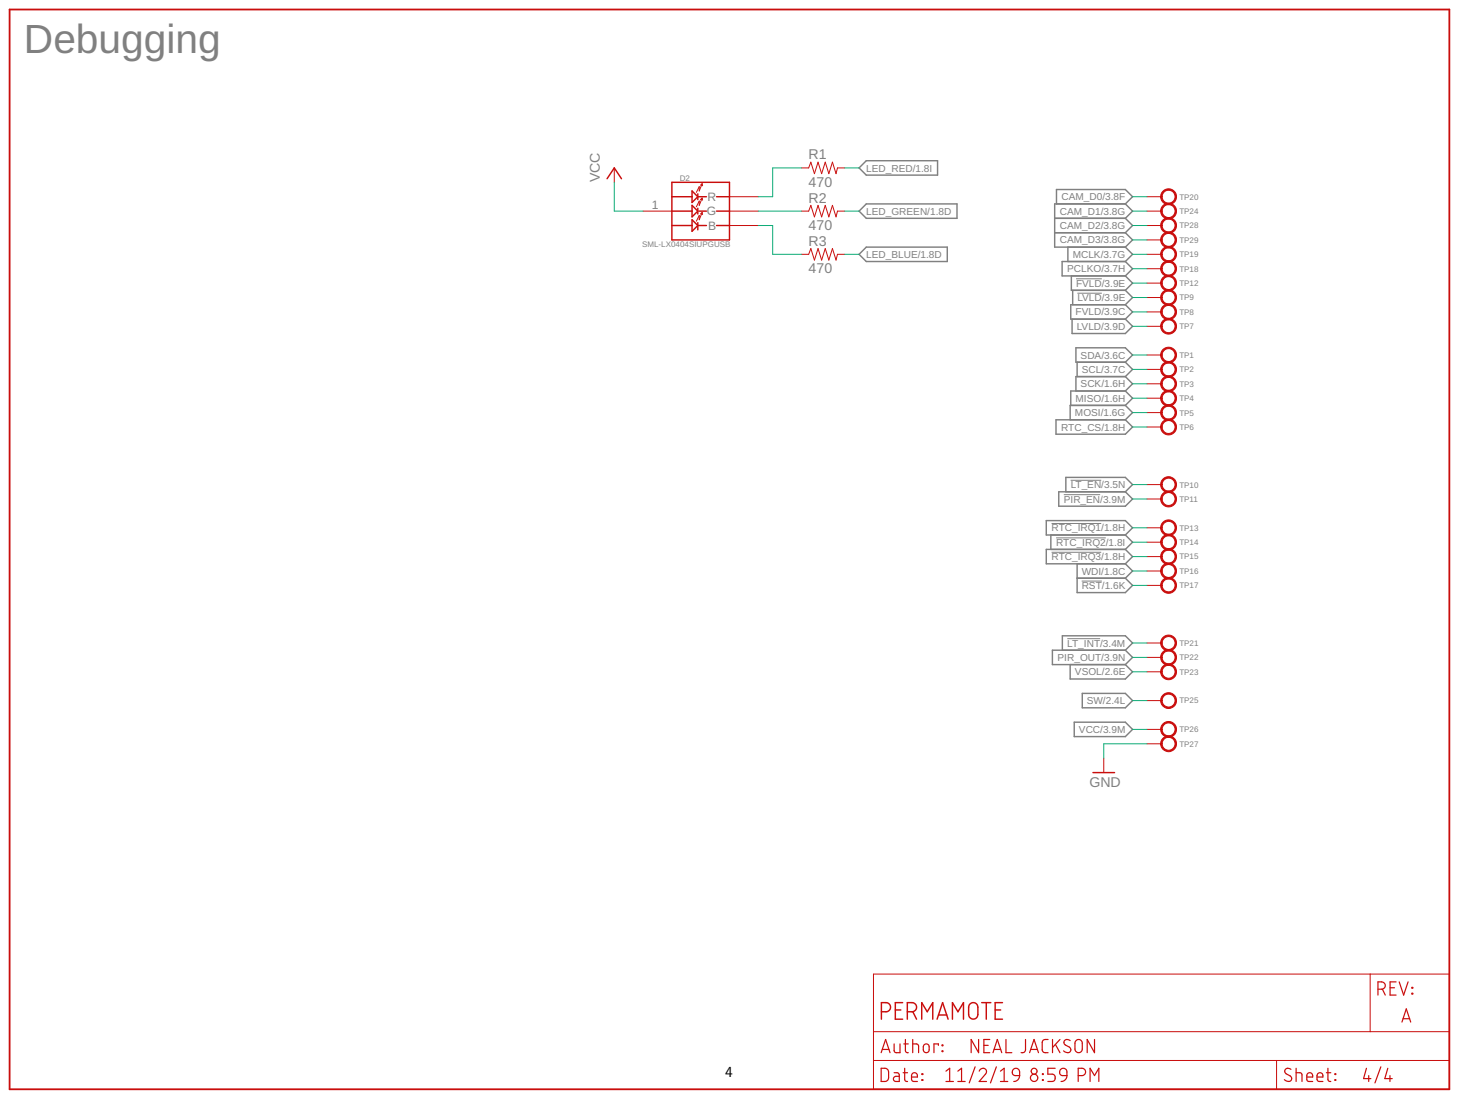
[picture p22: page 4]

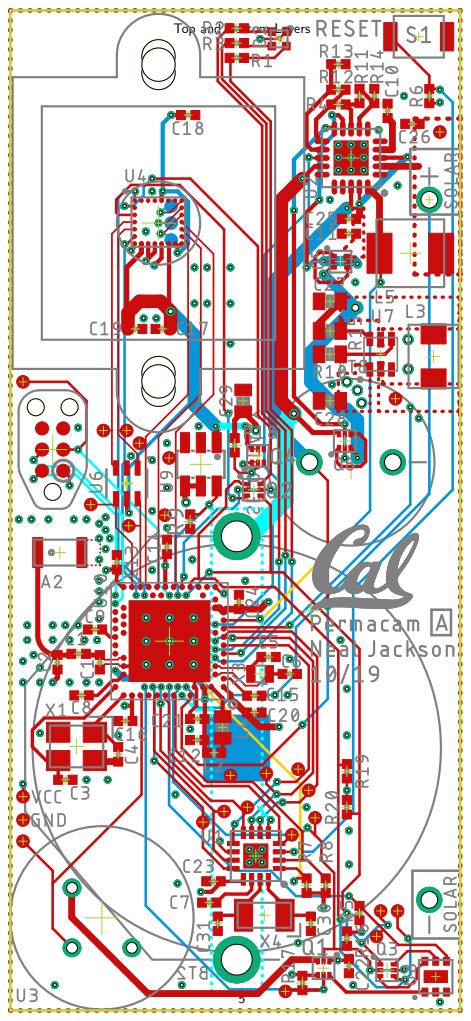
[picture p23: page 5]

Top and Bottom Layers

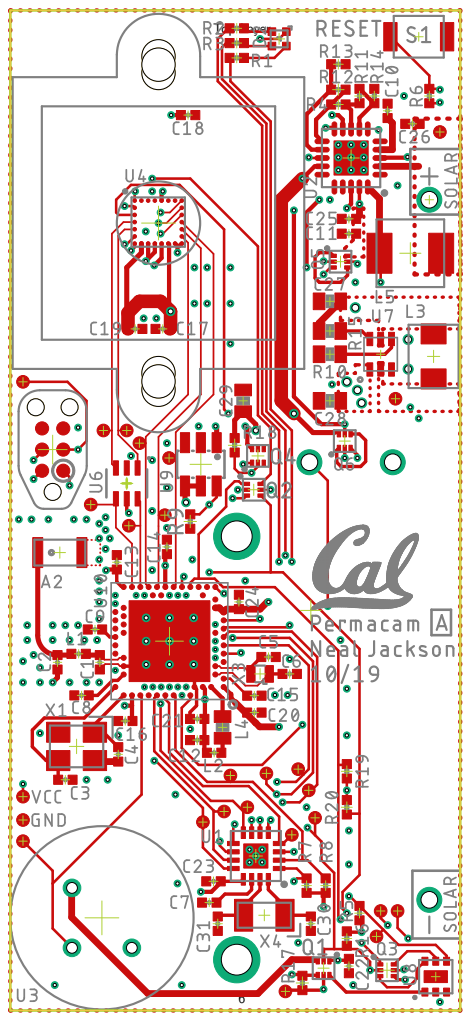
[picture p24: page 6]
Top; Layer

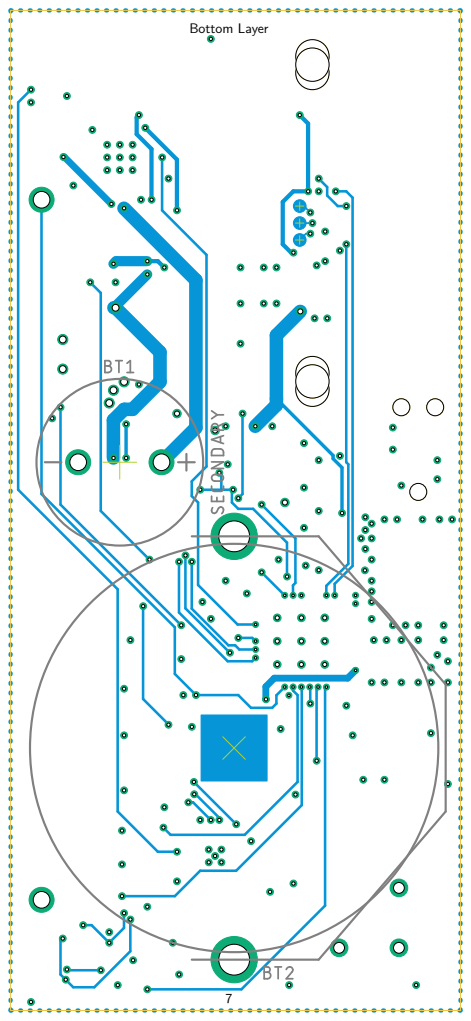
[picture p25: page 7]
Bottom Layer

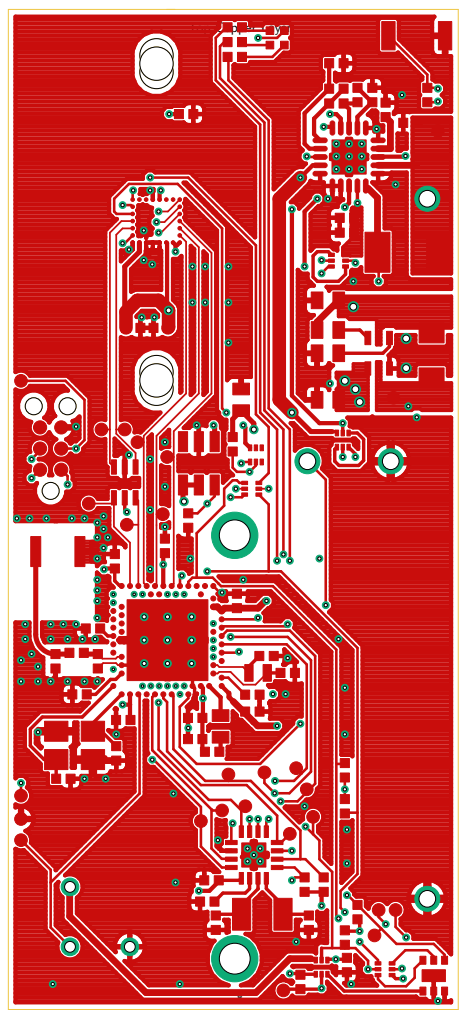
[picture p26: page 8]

Top Copper Layer

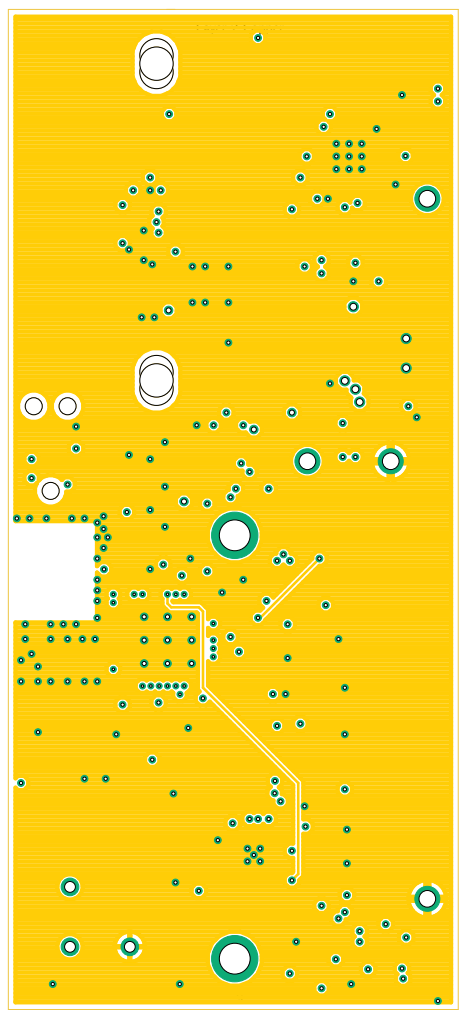
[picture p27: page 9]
Layer 2 Copper

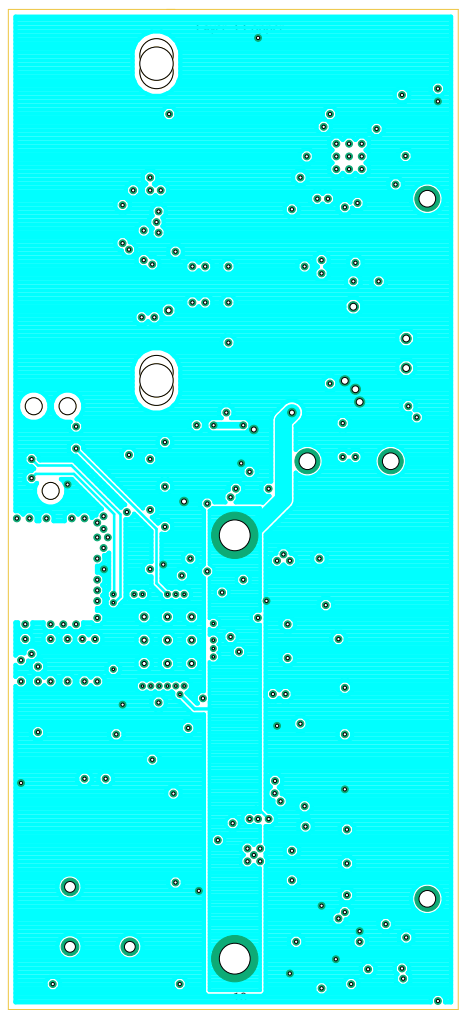
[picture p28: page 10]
Layer 3 Copper

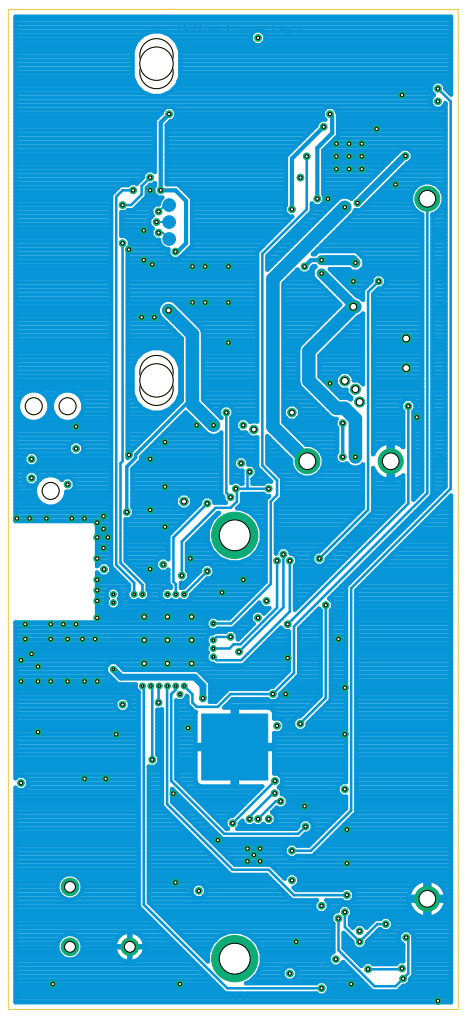
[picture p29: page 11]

Bottom Copper Layer

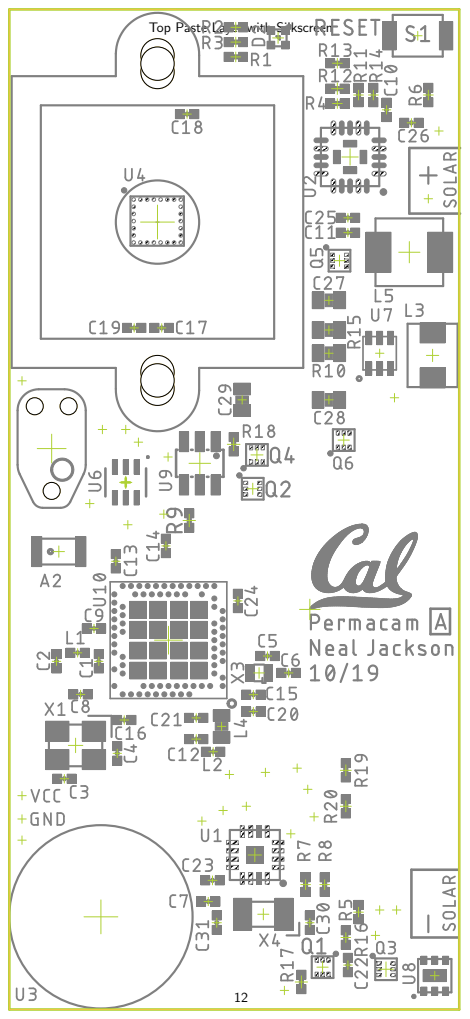
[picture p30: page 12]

Top Paste Layer with Silkscreen


Bottom Paste Layer with Silkscreen


Top and Bottom Layers 1:1 Scale

Top Layer 1:1 Scale

Layer 2 Copper 1:1 Scale

Layer 3 Copper 1:1 Scale


Bottom Copper Layer 1:1 Scale

19

Qty | Value | Device | Package | Parts | Description | DIGIKEY | MPN | Notes
7 | 0.1uF | CAPACITOR0402_CAP | | C13, C14, C1SMDC apacit490-6328-1-NGRM155R71C104KA88J
3 | 100M | RESISTOR040402_RES | | R16, R17, R1Resistor | | 541-100MAHHMC0402JT100M
1 | 100k | RESISTOR040402_RES | | R9 | Resistor | 311-100KJRCRC0402JR-07100KL
1 | 100pF | CAPACITOR0402_CAP | | C8 | SMD Capacit490-5922-1-NGRM1555C1H101JA01D
4 | 10k | RESISTOR040402_RES | | R5, R6, R7, RResistor | | 311-10KJRCTRC0402JR-0710KL
2 | 10nF | CAPACITOR0402_CAP | | C10, C11 | SMD Capacit490-4516-1-NGRM155R71H103KA88D
3 | 10uF | CAPACITOR0603_CAP | | C27, C28, C2SMD Capacit490-3896-1-NGRM188R60J106ME47D
1 | 10uH | INDUCTOR00603_CAP | | L4 | A very specifi490-4025-1-NLQM18FN100M00D
4 | 12pF | CAPACITOR0402_CAP | | C3, C4, C5, CSMD Capacit490-6197-1-NGRM1555C1H120GA01D
1 | 15nH | INDUCTOR00402_CAP | | L2 | A very specifi587-1521-1-NHK100515NJ-T
2 | 1pF | CAPACITOR0402_CAP | | C1, C2 | SMD Capacit1276-1595-1-CL05C010CB5NNNC
4 | 1uF | CAPACITOR0402_CAP | | C20, C21, C2SMDCapacit490-7195-1-NGRM155R70G105KA12D
1 | 1uH | INDUCTORIHI LL-1212BZ-L3 | | | A very specifi541-1319-1-NIHLP1212BZER1R0M11
1 | 215k | RESISTOR060603-RES | | R10 | Resistor | YAG3055CTRC0402FR-07215KL
1 | 22uH | INDUCTOR7740403070302040202000L5 | | | A very specifi732-3340-1-ND | | 74437324220
1 | 2477THMCO2477THMCO2477THMCOBT2 | | | | Battery clip foBAT-H LD-00BAT-HLD-001-THM
1 | 3.9M | RESISTOR040402_RES | | R11 | Resistor | YAG3301CTRC0402JR-073M9L
1 | 3.9nH | INDUCTOR00402_CAP | | L1 | A very specifi490-1131-1-NLQP15MN3N9B02D
1 | 32.768kHz | ABS05-32.76ABS05 | | X3 | 32.768kHz Cr535-11897-1-ABS05-32.768KHZ-9-T
1 | 32MHz | 7V-32.000MATXC-7V | | X1 | TXC CRYST887-2568-1-N7M-32.000MAHV-T
1 | 33M | RESISTOR060603-RES | | R15 | Resistor | HMC0603JT3HMC0603JT33M0
3 | 4.7uF | CAPACITOR0402_CAP | | C24, C25, C2SMD Capacit445-5947-1-NC1005X5R0J475K050BC
3 | 470 | RESISTOR040402_RES | | R1, R2, R3 | Resistor | 311-470JRCTRC0402JR-07470RL
1 | 47nF | CAPACITOR0402_CAP | | C12 | SMD Capacit445-1264-1-NC1005X7R1C473K050BC
1 | 47pF | CAPACITOR0402_CAP | | C7 | SMD Capacit490-5942-1-NGRM1555C1H470JA01D
1 | 6.04k | RESISTOR040402_RES | | R4 | Resistor | YAG2293CTRC0402FR-076K04L
1 | 6.2M | RESISTOR040402_RES | | R12 | Resistor | YAG3309CTRC0402JR-076M2L
1 | 6.8M | RESISTOR040402_RES | | R13 | Resistor | YAG3310CTRC0402JR-076M8L
1 | 820pF | CAPACITOR0402_CAP | | C9 | SMD Capacit1276-6535-1-CL05B821KO5NNNC
1 | 9.1M | RESISTOR040402_RES | | R14 | Resistor | YAG3322CTRC0402JR-079M1L
1 | AB1815-T3 | AB1815-T3 | QFN-16-3MMU1 | | Ultra-low curr535-11936-1-AB1815-T3
1 | ABS07-32.76ABS07-32.762-SMD | | | X4 | 32.768kHz Cr535-9543-1-NABS07-32.768KHZ-7-T
1 | ANT3216A06ANT3216A06ANT3216A06A2 | | | | Yageo 2.4GH311-1542-1-NANT3216A063R2400A
1 | B3U-1000P | B3U-1000P | B3U-1000P | S1 | Switch | SW1020CT-NBD3U-1000P
1 | BQ25505 | BQ25505 | S-PVQFN-N2U2 | | EH front end 296-37078-1-BQ25505RGRR
2 | DNP | CAPACITOR0402_CAP | C30, C31 | SMD Capacitor | Do not populate
2 | DNP | RESISTOR040402_RES | R19, R20 | Resistor | Do not populate
1 | EKMB110111E1KMB110111A1MN2 | U3 | Passive infrar255-3065-NDEKMB1101111
1 | HM01B0-ANHAM01B0-ANNAEOPAC-26 U4 | ultra low power CMOS ImaHgeMS0e1nBs0o-rA3N20Ax 320 | Consigned part
1 | LTOHTC1020LTOHTC1020 | 1020 | BT1 | Do not populate
1 | MAX17222 | MAX17222 | UDFN-6-MAU7 | | Very high effiMAX17222EMAX17222ELT +T
1 | MAX44009 | MAX44009 | UDFN-6-EXPU8 | | low power amMAX44009EMAX44009EDT+T
1 | NRF52840 | NRF52840 | AQFN73 | U10 | ultra-low pow1490-1071-1-RF52840
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

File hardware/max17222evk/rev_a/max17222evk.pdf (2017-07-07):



Top and Bottom Layers

Top Layer

Bottom Layer


Top Copper Layer


Bottom Copper Layer


Top Paste Layer with Silkscreen

Bottom Paste Layer with Silkscreen


Top and Bottom Layers 1:1 Scale


Top Layer 1:1 Scale


Bottom Copper Layer 1:1 Scale

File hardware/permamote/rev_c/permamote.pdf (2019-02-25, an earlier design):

# NRF52840


Only populate one MCU
Either populate the NRF52840
(Page 1) or NRF51822 (Page 2)

Do Not Populate I2C pull-up
(NRF has internal pull-up)

# Power Supply


BAT-HLD-002-THM
Note: Only populate one type of battery holder

Divider for Lithium Titanate

# Sensors


# Debugging



Top and Bottom Layers

Top Layer

Bottom Layer


Top Copper Layer

Layer 2 Copper

Layer 3 Copper


Bottom Copper Layer


Top Paste Layer with Silkscreen


Bottom Paste Layer with Silkscreen


Top and Bottom Layers 1:1 Scale

Top Layer 1:1 Scale

Layer 2 Copper 1:1 Scale

Layer 3 Copper 1:1 Scale


Bottom Copper Layer 1:1 Scale

### permamote_bom

Qty Value | Device
9 0.1uF | CAPACITOR0402_CAP
5 100M | RESISTOR0402_RES
1 100pF | CAPACITOR0402_CAP
5 10k | RESISTOR0402_RES
2 10nF | CAPACITOR0402_CAP
3 10uF | CAPACITOR0603_CAP
1 10uH | INDUCTOR0603
4 12pF | CAPACITOR0402_CAP
1 15nH | INDUCTOR0402
2 1pF | CAPACITOR0402_CAP
5 1uF | CAPACITOR0402_CAP
1 1uH | INDUCTORIHL
1 22uH | INDUCTOR74437324220
1 3.9M | RESISTOR0402_RES
1 3.9nH | INDUCTOR0402
1 32.768kHz | ABS05-32.768KHZ-9-T
1 32MHz | 7V-32.000MAHV-T
1 33M | RESISTOR0603_RES
3 4.7uF | CAPACITOR0402_CAP
3 | 470 RESISTOR0402_RES
1 47nF | CAPACITOR0402_CAP
1 47pF | CAPACITOR0402_CAP
1 6.04k | RESISTOR0402_RES
1 6.2M | RESISTOR0402_RES
1 6.8M | RESISTOR0402_RES
1 80.6k | RESISTOR0603_RES
1 820pF | CAPACITOR0402_CAP
1 9.1M | RESISTOR0402_RES
1 AB1815-T3 | AB1815-T3
1 ABS07-32.768KHZ-7-T | ABS07-32.768KHZ-7-T
1 ANT3216A063R2400A | ANT3216A063R2400A
2 BAT-HLD-002-THM | BAT-HLD-002-THM
1 BAT_PACKCR123A | BAT_PACKCR123A
1 BQ25505 | BQ25505
2 DNP | CAPACITOR0402_CAP
2 DNP | RESISTOR0402_RES
1 EKMB1101111 | EKMB1101111
1 B3U-1000P | B3U-1000P
1 FT232RQ | FT232RQ
1 LIS2DW12 | LIS2DW12
1 LTOHTC1020 | LTOHTC1020
1 MAX17222 | MAX17222
1 MAX44009 | MAX44009
1 MICRO_USB_B_HIROSE_ZX62R-B-5P(30) MICRO_USB_B_HIROSE_ZX62R-B-5P(30)
1 MS5637-02BA03 | MS5637-02BA03
1 NRF52840 | NRF52840
9 PMDXB950UPEL | PMDXB950UPEL
1 SI7021-A20-GM1 | SI7021-A20-GM1

1 SML-LX0404SIUPGUSB | SML-LX0404SIUPGUSB
1 SOLARCELLHOLES | SOLARCELLHOLES
1 TCS34725 | TCS34725

Package
0402_CAP
0402_RES
0402_CAP
0402_RES
0402_CAP
0603_CAP
0603_CAP
0402_CAP
0402_CAP
0402_CAP
0402_CAP
IHL-1212BZ-11
74437324220
0402_RES
0402_CAP
ABS05
TXC-7V
0603-RES
0402_CAP
0402_RES
0402_CAP
0402_CAP
0402_RES
0402_RES
0402_RES
0603-RES
0402_CAP
0402_RES
QFN-16-3MM
2-SMD
ANT3216A063R2400A
BAT-HLD-002-THM
BH123A
S-PVQFN-N20-RGR
0402_CAP
0402_RES
AMN2
B3U-1000P
QFN32
LGA-12
1020
UDFN-6-MAXIM
UDFN-6-EXPOSED
MICRO_USB_B_HIROSE_ZX62R-B-5P(30) 4-SMD
AQFN73
XDFN-6
DFN-6/3MM

1MM_SQ_4PAD
SOLAR_HOLES
FN-6

Parts
C13, C14, C15, C16, C17, C18, C19, C20, C21 R23, R24, R25, R26, R27
C8
R8, R9, R10, R11, R12
C10, C11
C30, C31, C32
L4
C3, C4, C5, C6
L2
C1, C2
C22, C23, C24, C25, C26
L3
L5
R14
L1
X3
X1
R22
C27, C28, C29
R1, R2, R3
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
BT2, BT3
BT4
U2
C33, C34
R6, R7
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
Q1, Q2, Q3, Q4, Q5, Q6, Q7, Q8, Q10 U11

D2
D1
U12

Description
SMD Capacitor
Resistor
SMD Capacitor
Resistor
SMD Capacitor
SMD Capacitor
A very specific inductor
SMD Capacitor
A very specific inductor
SMD Capacitor
SMD Capacitor
A very specific inductor
A very specific inductor
Resistor
A very specific inductor
32.768kHz Crystal
TXC CRYSTAL SMD
Resistor
SMD Capacitor
Resistor
SMD Capacitor
SMD Capacitor
Resistor
Resistor
Resistor
Resistor
SMD Capacitor
Resistor
Ultra-low current RTC. 55nA quiescent @ 3V. 1.5-3.6V input. 32.768kHz Crystal
Yageo 2.4GHz
RETAINER BATT CR2016 PC PINS
collection of battery footprints
EH front end for switching between primary and secondary cells SMD Capacitor
Resistor
Passive infrared human detection sensor with built-in amp.
SWITCH TACTILE
Source: http://www.ftdichip.com/Documents/DataSheets/DS_FT232R_v104.pdf ultra low power 3 axis accelerometer
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

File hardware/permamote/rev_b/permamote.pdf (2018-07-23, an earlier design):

# NRF52840


Only populate one MCU
Either populate the NRF52840
(Page 1) or NRF51822 (Page 2)

Do Not Populate I2C pull-up
(NRF has internal pull-up)

# Power Supply

## LBST U2


BAT-HLD-002-THM
Note: Only populate one type of battery holder

Divider for Lithium Titanate

# Sensors


# Debugging



Top and Bottom Layers

Top Layer

Bottom Layer


Top Copper Layer

Layer 2 Copper

Layer 3 Copper


Bottom Copper Layer


Top Paste Layer with Silkscreen


Bottom Paste Layer with Silkscreen


Top and Bottom Layers 1:1 Scale

Top Layer 1:1 Scale

Layer 2 Copper 1:1 Scale

Layer 3 Copper 1:1 Scale


Bottom Copper Layer 1:1 Scale

### permamote_bom

Qty Value | Device
9 0.1uF | CAPACITOR0402_CAP
5 100M | RESISTOR0402_RES
1 100pF | CAPACITOR0402_CAP
5 10k | RESISTOR0402_RES
2 10nF | CAPACITOR0402_CAP
3 10uF | CAPACITOR0603_CAP
1 10uH | INDUCTOR0603
4 12pF | CAPACITOR0402_CAP
1 15nH | INDUCTOR0402
2 1pF | CAPACITOR0402_CAP
5 1uF | CAPACITOR0402_CAP
1 1uH | INDUCTORIHL
1 22uH | INDUCTOR74437324220
1 3.9M | RESISTOR0402_RES
1 3.9nH | INDUCTOR0402
1 32.768kHz | ABS05-32.768KHZ-9-T
1 32MHz | 7V-32.000MAHV-T
1 33M | RESISTOR0603_RES
3 4.7uF | CAPACITOR0402_CAP
3 | 470 RESISTOR0402_RES
1 47nF | CAPACITOR0402_CAP
1 47pF | CAPACITOR0402_CAP
1 6.04k | RESISTOR0402_RES
1 6.2M | RESISTOR0402_RES
1 6.8M | RESISTOR0402_RES
1 80.6k | RESISTOR0603_RES
1 820pF | CAPACITOR0402_CAP
1 9.1M | RESISTOR0402_RES
1 AB1815-T3 | AB1815-T3
1 ABS07-32.768KHZ-7-T | ABS07-32.768KHZ-7-T
1 ANT3216A063R2400A | ANT3216A063R2400A
2 BAT-HLD-002-THM | BAT-HLD-002-THM
1 BAT_PACKCR123A | BAT_PACKCR123A
1 BQ25505 | BQ25505
2 DNP | CAPACITOR0402_CAP
2 DNP | RESISTOR0402_RES
1 EKMB1101111 | EKMB1101111
1 EVQP2 | EVQP2
1 FT232RQ | FT232RQ
1 LIS2DW12 | LIS2DW12
1 LTOHTC1020 | LTOHTC1020
1 MAX17222 | MAX17222
1 MAX44009 | MAX44009
1 MICRO_USB_B_HIROSE_ZX62R-B-5P(30) MICRO_USB_B_HIROSE_ZX62R-B-5P(30)
1 MS5637-02BA03 | MS5637-02BA03
1 NRF52840 | NRF52840
9 PMDXB950UPEL | PMDXB950UPEL
1 SI7021-A20-GM1 | SI7021-A20-GM1
1 SML-LX0404SIUPGUSB | SML-LX0404SIUPGUSB

1 SOLARCELLHOLES | SOLARCELLHOLES
1 TCS34725 | TCS34725

Package
0402_CAP
0402_RES
0402_CAP
0402_RES
0402_CAP
0603_CAP
0603_CAP
0402_CAP
0402_CAP
0402_CAP
0402_CAP
IHL-1212BZ-11
74437324220
0402_RES
0402_CAP
ABS05
TXC-7V
0603-RES
0402_CAP
0402_RES
0402_CAP
0402_CAP
0402_RES
0402_RES
0402_RES
0603-RES
0402_CAP
0402_RES
QFN-16-3MM
2-SMD
ANT3216A063R2400A
BAT-HLD-002-THM
BH123A
S-PVQFN-N20-RGR
0402_CAP
0402_RES
AMN2
EVQP2
QFN32
LGA-12
1020
UDFN-6-MAXIM
UDFN-6-EXPOSED
MICRO_USB_B_HIROSE_ZX62R-B-5P(30) 4-SMD
AQFN73
XDFN-6
DFN-6/3MM
1MM_SQ_4PAD

SOLAR_HOLES
FN-6

Parts
C13, C14, C15, C16, C17, C18, C19, C20, C21 R23, R24, R25, R26, R27
C8
R8, R9, R10, R11, R12
C10, C11
C30, C31, C32
L4
C3, C4, C5, C6
L2
C1, C2
C22, C23, C24, C25, C26
L3
L5
R14
L1
X3
X1
R22
C27, C28, C29
R1, R2, R3
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
BT2, BT3
BT4
U2
C33, C34
R6, R7
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
Q1, Q2, Q3, Q4, Q5, Q6, Q7, Q8, Q10 U11
D2

D1
U12

Description
SMD Capacitor
Resistor
SMD Capacitor
Resistor
SMD Capacitor
SMD Capacitor
A very specific inductor
SMD Capacitor
A very specific inductor
SMD Capacitor
SMD Capacitor
A very specific inductor
A very specific inductor
Resistor
A very specific inductor
32.768kHz Crystal
TXC CRYSTAL SMD
Resistor
SMD Capacitor
Resistor
SMD Capacitor
SMD Capacitor
Resistor
Resistor
Resistor
Resistor
SMD Capacitor
Resistor
Ultra-low current RTC. 55nA quiescent @ 3V. 1.5-3.6V input. 32.768kHz Crystal
Yageo 2.4GHz
RETAINER BATT CR2016 PC PINS
collection of battery footprints
EH front end for switching between primary and secondary cells SMD Capacitor
Resistor
Passive infrared human detection sensor with built-in amp.
SWITCH TACTILE SPST-NO 0.02A 15V
Source: http://www.ftdichip.com/Documents/DataSheets/DS_FT232R_v104.pdf ultra low power 3 axis accelerometer
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

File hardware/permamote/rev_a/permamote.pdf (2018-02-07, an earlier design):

# NRF52840


Only populate one MCU
Either populate the NRF52840
(Page 1) or NRF51822 (Page 2)

Do Not Populate I2C pull-up
(NRF has internal pull-up)

# Power Supply

## LBST U2


BAT-HLD-002-THM
Note: Only populate one type of battery holder

Divider for Lithium Titanate

# Sensors


# Debugging



Top and Bottom Layers

Top Layer

Bottom Layer


Top Copper Layer

Layer 2 Copper

Layer 3 Copper


Bottom Copper Layer


Top Paste Layer with Silkscreen

Bottom Paste Layer with Silkscreen


Top and Bottom Layers 1:1 Scale

Top Layer 1:1 Scale

Layer 2 Copper 1:1 Scale

Layer 3 Copper 1:1 Scale


Bottom Copper Layer 1:1 Scale

### permamote

Qty Value | Device
9 0.1uF | CAPACITOR0402_CAP
1 0.5pF | CAPACITOR0402_CAP
1 0.8pF | CAPACITOR0402_CAP
5 100M | RESISTOR0402_RES
1 100pF | CAPACITOR0402_CAP
7 10k | RESISTOR0402_RES
2 10nF | CAPACITOR0402_CAP
3 10uF | CAPACITOR0603_CAP
1 10uH | INDUCTOR0603
4 12pF | CAPACITOR0402_CAP
1 15nH | INDUCTOR0402
5 1uF | CAPACITOR0402_CAP
1 1uH | INDUCTORIHL
1 22uH | INDUCTOR74437324220
1 3.3nH | INDUCTOR0402
1 3.9M | RESISTOR0402_RES
1 32.768kHz | ABS05-32.768KHZ-9-T
1 32MHz | 7V-32.000MAHV-T
1 33M | RESISTOR0603_RES
3 4.7uF | CAPACITOR0402_CAP
3 | 470 RESISTOR0402_RES
1 47nF | CAPACITOR0402_CAP
1 47pF | CAPACITOR0402_CAP
1 6.04k | RESISTOR0402_RES
1 6.2M | RESISTOR0402_RES
1 6.8M | RESISTOR0402_RES
1 80.6k | RESISTOR0603_RES
1 9.1M | RESISTOR0402_RES
1 AB1815-T3 | AB1815-T3
1 ABS07-32.768KHZ-7-T | ABS07-32.768KHZ-7-T
1 ANT3216A063R2400A | ANT3216A063R2400A
2 BAT-HLD-002-THM | BAT-HLD-002-THM
1 BAT_PACKCR123A | BAT_PACKCR123A
1 BQ25505 | BQ25505
2 DNP | CAPACITOR0402_CAP
5 DNP | RESISTOR0402_RES
1 EKMB1101111 | EKMB1101111
1 EVQP2 | EVQP2
1 FT232RQ | FT232RQ
1 ISL29125 | ISL29125
1 LIS2DW12 | LIS2DW12
1 LTOHTC1020 | LTOHTC1020
1 MAX17222 | MAX17222
1 MAX44009 | MAX44009
1 MICRO_USB_B_HIROSE_ZX62R-B-5P(30) MICRO_USB_B_HIROSE_ZX62R-B-5P(30)
1 MS5637-02BA03 | MS5637-02BA03
1 NRF52840 | NRF52840
9 PMDXB950UPEL | PMDXB950UPEL

1 SI7021-A20-GM1 | SI7021-A20-GM1
1 SML-LX0404SIUPGUSB | SML-LX0404SIUPGUSB
1 SOLARCELLHOLES | SOLARCELLHOLES

Package
0402_CAP
0402_CAP
0402_CAP
0402_RES
0402_CAP
0402_RES
0402_CAP
0603_CAP
0603_CAP
0402_CAP
0402_CAP
0402_CAP
IHL-1212BZ-11
74437324220
0402_CAP
0402_RES
ABS05
TXC-7V
0603-RES
0402_CAP
0402_RES
0402_CAP
0402_CAP
0402_RES
0402_RES
0402_RES
0603-RES
0402_RES
QFN-16-3MM
2-SMD
ANT3216A063R2400A
BAT-HLD-002-THM
BH123A
S-PVQFN-N20-RGR
0402_CAP
0402_RES
AMN2
EVQP2
QFN32
ODFN-6-1.5MMX1.6MM
LGA-12
1020
UDFN-6-MAXIM
UDFN-6-EXPOSED
MICRO_USB_B_HIROSE_ZX62R-B-5P(30) 4-SMD
AQFN73
XDFN-6

DFN-6/3MM
1MM_SQ_4PAD
SOLAR_HOLES

Parts
C12, C13, C14, C15, C16, C17, C18, C19, C20 C1
C2
R23, R24, R25, R26, R27
C8
R6, R7, R8, R9, R10, R11, R12 C9, C10
C29, C30, C31
L4
C3, C4, C5, C6
L2
C21, C22, C23, C24, C25
L3
L5
L1
R14
X3
X1
R22
C26, C27, C28
R1, R2, R3
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
BT2, BT3
BT4
U2
C32, C33
R5, R15, R16, R19, R20
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
Q1, Q2, Q3, Q4, Q5, Q6, Q7, Q8, Q10

U11
D2
D1

Description
SMD Capacitor
SMD Capacitor
SMD Capacitor
Resistor
SMD Capacitor
Resistor
SMD Capacitor
SMD Capacitor
A very specific inductor
SMD Capacitor
A very specific inductor
SMD Capacitor
A very specific inductor
A very specific inductor
A very specific inductor
Resistor
32.768kHz Crystal
TXC CRYSTAL SMD
Resistor
SMD Capacitor
Resistor
SMD Capacitor
SMD Capacitor
Resistor
Resistor
Resistor
Resistor
Resistor
Ultra-low current RTC. 55nA quiescent @ 3V. 1.5-3.6V input. 32.768kHz Crystal
Yageo 2.4GHz
RETAINER BATT CR2016 PC PINS
collection of battery footprints
EH front end for switching between primary and secondary cells SMD Capacitor
Resistor
Passive infrared human detection sensor with built-in amp.
SWITCH TACTILE SPST-NO 0.02A 15V
Source: http://www.ftdichip.com/Documents/DataSheets/DS_FT232R_v104.pdf low power i2c color sensor
ultra low power 3 axis accelerometer
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

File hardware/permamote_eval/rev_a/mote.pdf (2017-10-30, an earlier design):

# NRF52840

## GND


Only populate one MCU
Either populate the NRF52840
(Page 1) or NRF51822 (Page 2)

AD12 is in the way of the
actual Reset pin, AC13, so we just route over it.

# Auxillary NRF51822


Only populate one MCU
Either populate the NRF52840
(Page 1) or NRF51822 (Page 2)

# Power Supply

BT1


Note: Only populate one type of battery holder

# Sensors

# Accelerometer


Mounting Holes; MOUNT-PAD-ROUND3.0; GND; SDA/4.12H; SCL/4.12G; CLR_INT/4.7H; LT_INT/4.11F SCK/4.1G; ACC_CS/4.1H; MOSI/4.1H; MISO/4.1H; ACC_INT1/4.3G; ACC_INT2/4.3G; ACC_EN/2.7F CLR_EN/4.7F PR_EN/4.3N; HUM_EN/4.6N; PIR_EN/4.9M; PIR_OUT/4.9N; RTC_IRQ1/2.7H; RTC_IRQ2/2.7H; RTC_IRQ3/2.7H; RTC_CS/2.7H WDI/2.7G; RST/2.3J VBAT/3.11C; VSOL/3.5E; SW/3.4L VSEC/3.8C

# Top and Bottom Layers


# Top Layer


# Bottom Layer


# Top Copper Layer


# Layer 2 Copper


# Layer 3 Copper


# Bottom Copper Layer


# Top Paste Layer with Silkscreen


# Bottom Paste Layer with Silkscreen


# Top and Bottom Layers 1:1 Scale


# Top Layer 1:1 Scale


# Layer 2 Copper 1:1 Scale


# Layer 3 Copper 1:1 Scale


# Bottom Copper Layer 1:1 Scale


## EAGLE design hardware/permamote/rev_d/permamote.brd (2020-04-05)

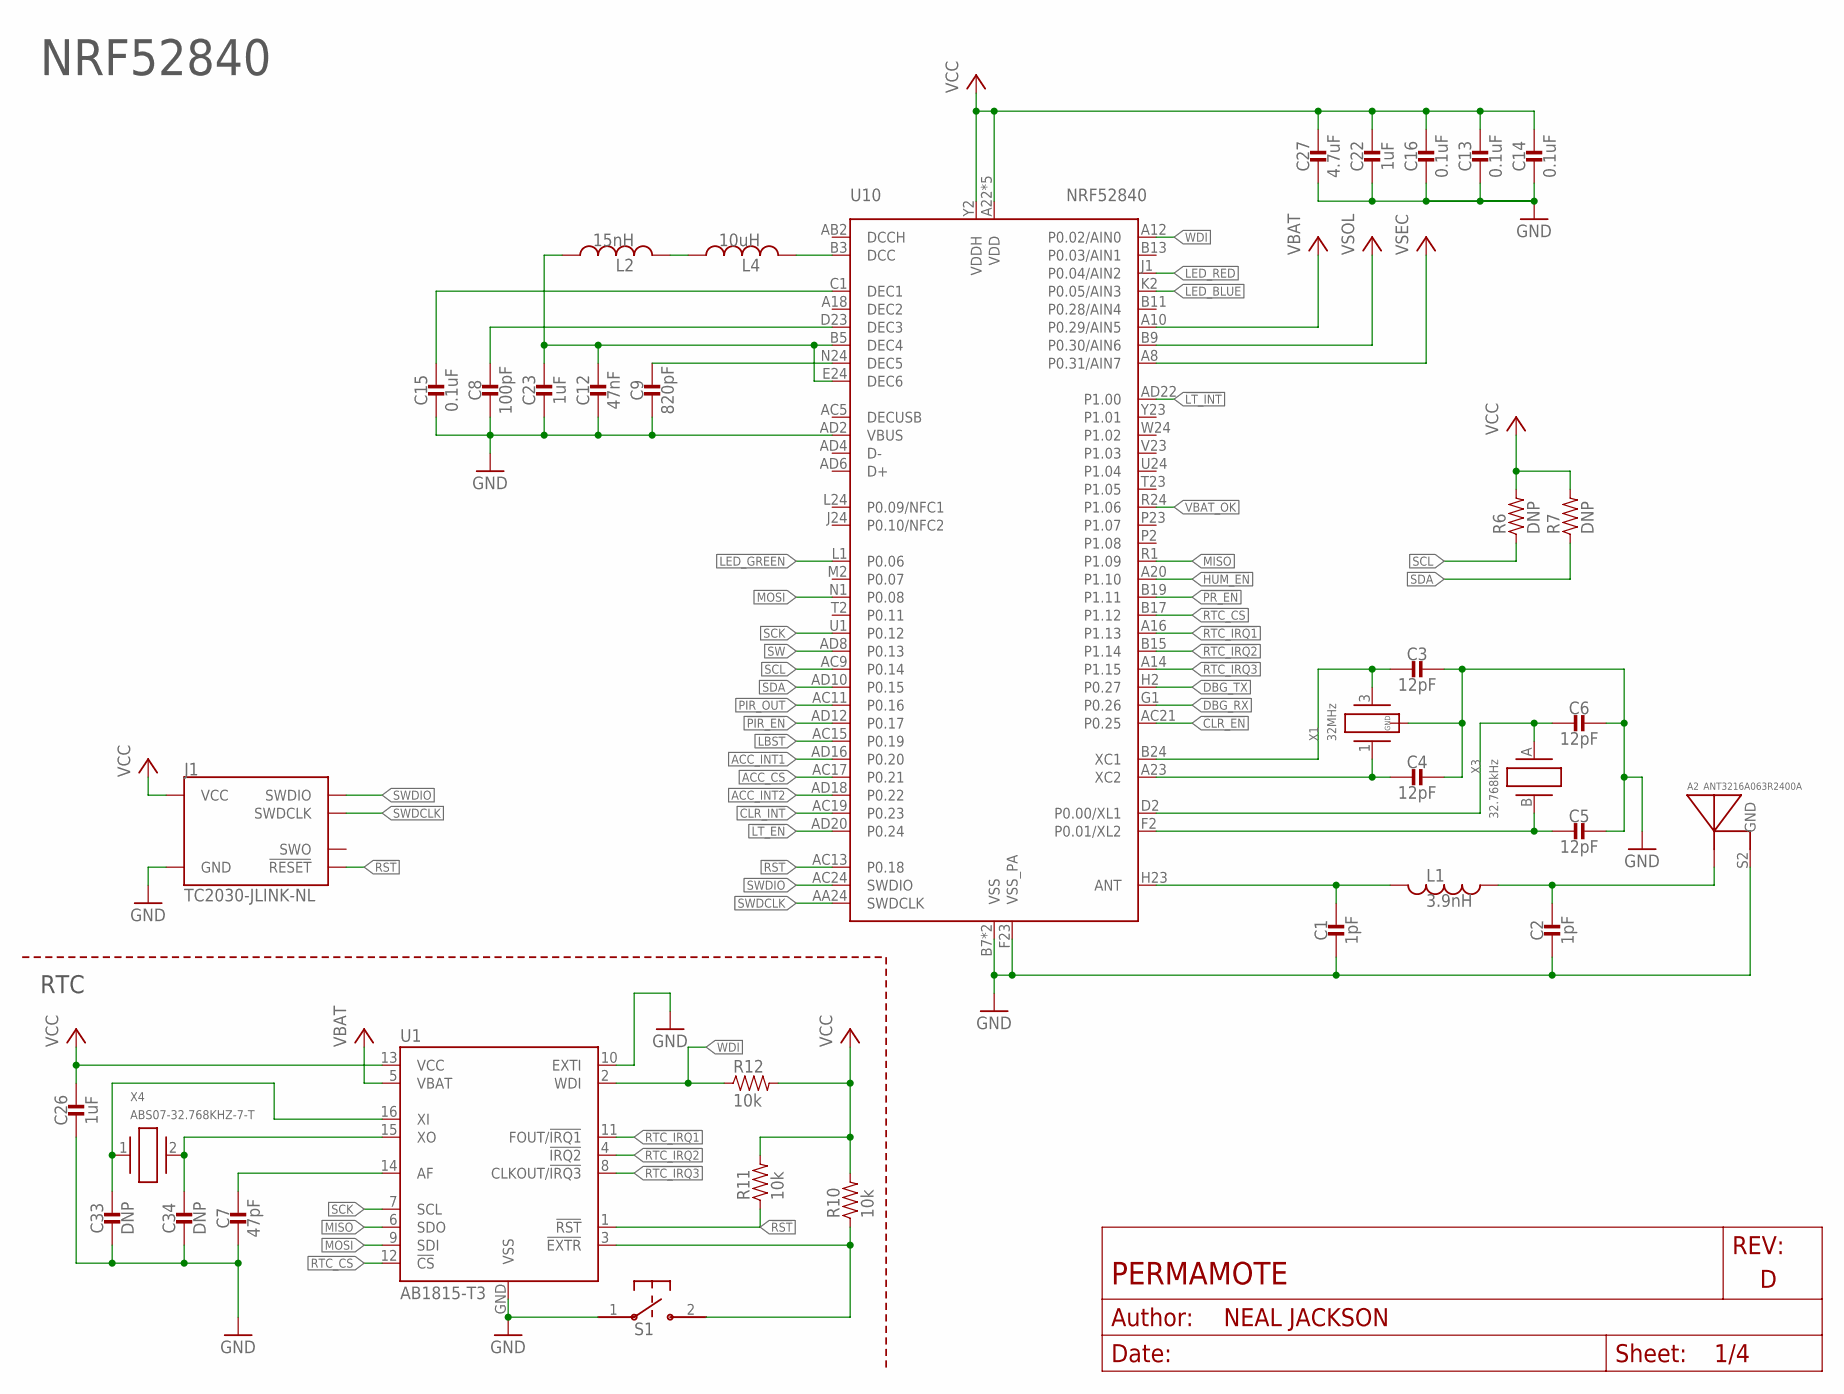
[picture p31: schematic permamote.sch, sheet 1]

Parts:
A2: ANT3216A063R2400A
C1, C2: 1pF; 0402_CAP; MPN CL05C010CB5NNNC; DIGIKEY 1276-1595-1-ND
C3, C4, C5, C6: 12pF; 0402_CAP; MPN GRM1555C1H120GA01D; DIGIKEY 490-6197-1-ND
C7: 47pF; 0402_CAP; MPN GRM1555C1H470JA01D; DIGIKEY 490-5942-1-ND
C8: 100pF; 0402_CAP; MPN GRM1555C1H101JA01D; DIGIKEY 490-5922-1-ND
C9: 820pF; 0402_CAP; MPN CL05B821KO5NNNC; DIGIKEY 1276-6535-1-ND
C12: 47nF; 0402_CAP; MPN C1005X7R1C473K050BC; DIGIKEY 445-1264-1-ND
C13, C14, C15, C16: 0.1uF; 0402_CAP; MPN GRM155R71C104KA88J; DIGIKEY 490-6328-1-ND
C22, C23, C26: 1uF; 0402_CAP; MPN GRM155R70G105KA12D; DIGIKEY 490-7195-1-ND
C27: 4.7uF; 0402_CAP; MPN C1005X5R0J475K050BC; DIGIKEY 445-5947-1-ND
C33, C34: DNP; 0402_CAP
J1: TC2030-JLINK-NL; TC2030-IDC-NL
L1: 3.9nH; 0402_CAP; MPN LQP15MN3N9B02D; DIGIKEY 490-1131-1-ND
L2: 15nH; 0402_CAP; MPN HK100515NJ-T; DIGIKEY 587-1521-1-ND
L4: 10uH; 0603_CAP; MPN LQM18FN100M00D; DIGIKEY 490-4025-1-ND
R6, R7: DNP; 0402_RES; MPN RC0402JR-0710KL; DIGIKEY 311-10KJRCT-ND
R10, R11, R12: 10k; 0402_RES; MPN RC0402JR-0710KL; DIGIKEY 311-10KJRCT-ND
S1: B3U-1000P
U1: AB1815-T3; QFN-16-3MM
U10: NRF52840; AQFN73
X1: 32MHz; TXC-7V
X3: 32.768kHz; ABS05
X4: ABS07-32.768KHZ-7-T; 2-SMD

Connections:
!CLR_EN: U10.AC21 (P0.25); also elsewhere on the board
!CLR_INT: U10.AC19 (P0.23); also elsewhere on the board
!HUM_EN: U10.A20 (P1.10); also elsewhere on the board
!LT_EN: U10.AD20 (P0.24); also elsewhere on the board
!LT_INT: U10.AD22 (P1.00); also elsewhere on the board
!PIR_EN: U10.AD12 (P0.17); also elsewhere on the board
!PR_EN: U10.B19 (P1.11); also elsewhere on the board
!RST: J1.3 (!RESET), R11.1, U1.1 (!RST), U10.AC13 (P0.18); also elsewhere on the board
!RTC_EXTR: R10.1, S1.2, U1.3 (!EXTR)
!RTC_IRQ1: U1.11 (FOUT/!IRQ1), U10.A16 (P1.13); also elsewhere on the board
!RTC_IRQ2: U1.4 (!IRQ2), U10.B15 (P1.14); also elsewhere on the board
!RTC_IRQ3: U1.8 (CLKOUT/!IRQ3), U10.A14 (P1.15); also elsewhere on the board
ACC_CS: U10.AC17 (P0.21); also elsewhere on the board
ACC_INT1: U10.AD16 (P0.20); also elsewhere on the board
ACC_INT2: U10.AD18 (P0.22); also elsewhere on the board
DBG_RX: U10.G1 (P0.26)
DBG_TX: U10.H2 (P0.27)
GND: A2.S2 (GND), C1.2, C2.2, C3.1, C4.1, C5.1, C6.1, C7.2, C8.2, C9.2, C12.2, C13.2, C14.2, C15.2, C16.2, C22.2, C23.2, C26.2, C27.2, C33.2, C34.2, J1.5 (GND), S1.1, U1.10 (EXTI), U1.GND (VSS), U10.AD2 (VBUS), U10.B7 (VSS), U10.F23 (VSS_PA), U10.GND (VSS), X1.2 (GND), X1.4 (GND); also elsewhere on the board
LBST: U10.AC15 (P0.19); also elsewhere on the board
LED_BLUE: U10.K2 (P0.05/AIN3); also elsewhere on the board
LED_GREEN: U10.L1 (P0.06); also elsewhere on the board
LED_RED: U10.J1 (P0.04/AIN2); also elsewhere on the board
MISO: U1.6 (SDO), U10.R1 (P1.09); also elsewhere on the board
MOSI: U1.9 (SDI), U10.N1 (P0.08); also elsewhere on the board
unnamed: C9.1, U10.N24 (DEC5)
unnamed: C15.1, U10.C1 (DEC1)
unnamed: C12.1, C23.1, L2.1, U10.B5 (DEC4), U10.E24 (DEC6)
unnamed: C8.1, U10.D23 (DEC3)
unnamed: C1.1, L1.2, U10.H23 (ANT)
unnamed: A2.S1 (ANTENNA), C2.1, L1.1
unnamed: C3.2, U10.B24 (XC1), X1.3 (2)
unnamed: C4.2, U10.A23 (XC2), X1.1
unnamed: C7.1, U1.14 (AF)
unnamed: C33.1, U1.16 (XI), X4.1
unnamed: C34.1, U1.15 (XO), X4.2
unnamed: L4.2, U10.B3 (DCC)
unnamed: L2.2, L4.1
PIR_OUT: U10.AC11 (P0.16); also elsewhere on the board
RTC_CS: U1.12 (!CS), U10.B17 (P1.12); also elsewhere on the board
SCK: U1.7 (SCL), U10.U1 (P0.12); also elsewhere on the board
SCL: R6.1, U10.AC9 (P0.14); also elsewhere on the board
SDA: R7.1, U10.AD10 (P0.15); also elsewhere on the board
SW: U10.AD8 (P0.13); also elsewhere on the board
SWDCLK: J1.4 (SWDCLK), U10.AA24 (SWDCLK)
SWDIO: J1.2 (SWDIO), U10.AC24 (SWDIO)
VBAT: U1.5 (VBAT), U10.A10 (P0.29/AIN5); also elsewhere on the board
VBAT_OK: U10.R24 (P1.06); also elsewhere on the board
VCC: C13.1, C14.1, C16.1, C22.1, C26.1, C27.1, J1.1 (VCC), R6.2, R7.2, R10.2, R11.2, R12.2, U1.13 (VCC), U10.A22 (VDD), U10.AD14 (VDD), U10.AD23 (VDD), U10.B1 (VDD), U10.W1 (VDD), U10.Y2 (VDDH); also elsewhere on the board
VSEC: U10.A8 (P0.31/AIN7); also elsewhere on the board
VSOL: U10.B9 (P0.30/AIN6); also elsewhere on the board
WDI: R12.1, U1.2 (WDI), U10.A12 (P0.02/AIN0); also elsewhere on the board
XL1: C6.2, U10.D2 (P0.00/XL1), X3.A (1)
XL2: C5.2, U10.F2 (P0.01/XL2), X3.B (2)

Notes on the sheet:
NRF52840
RTC

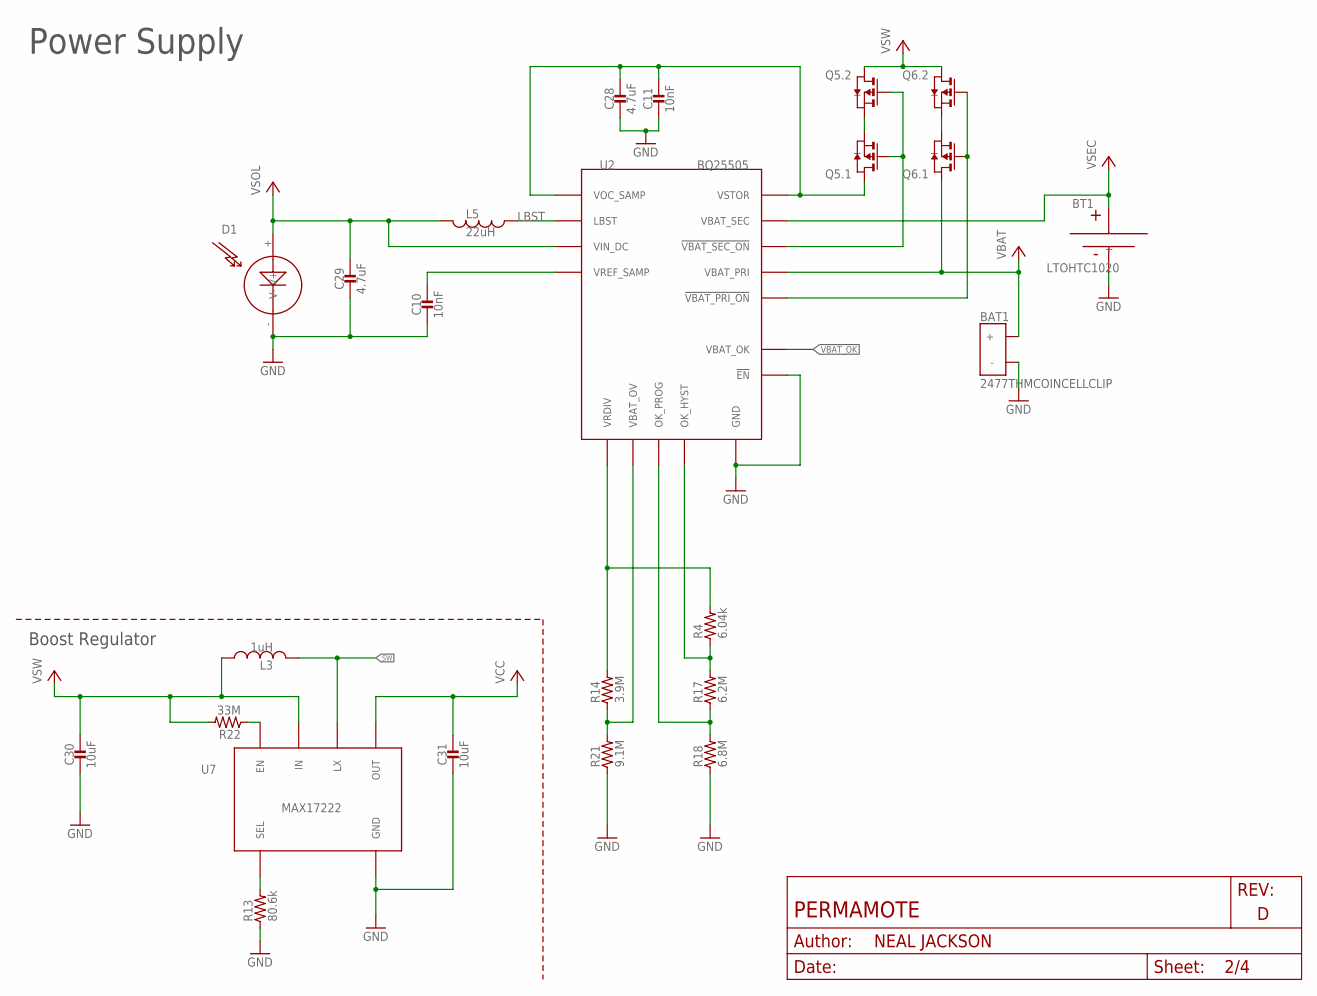
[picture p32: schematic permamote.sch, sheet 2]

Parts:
BAT1: 2477THMCOINCELLCLIP; 2477THMCOINCLIP
BT1: LTOHTC1020; 1020
C10, C11: 10nF; 0402_CAP; MPN GRM155R71H103KA88D; DIGIKEY 490-4516-1-ND
C28, C29: 4.7uF; 0402_CAP; MPN C1005X5R0J475K050BC; DIGIKEY 445-5947-1-ND
C30, C31: 10uF; 0603_CAP; MPN GRM188R60J106ME47D; DIGIKEY 490-3896-1-ND
D1: SOLARCELLHOLES; SOLAR_HOLES
L3: 1uH; IHL-1212BZ-11; MPN IHLP1212BZER1R0M11; DIGIKEY 541-1319-1-ND
L5: 22uH; 74437324220; MPN 74437324220; DIGIKEY 732-3340-1-ND
Q5, Q6: PMDXB950UPEL; XDFN-6
R4: 6.04k; 0402_RES; MPN RC0402FR-076K04L; DIGIKEY YAG2293CT-ND
R13: 80.6k; 0603-RES; MPN RC0603FR-0780K6L; DIGIKEY 311-80.6KHRCT-ND
R14: 3.9M; 0402_RES; MPN RC0402JR-073M9L; DIGIKEY YAG3301CT-ND
R17: 6.2M; 0402_RES; MPN RC0402JR-076M2L; DIGIKEY YAG3309CT-ND
R18: 6.8M; 0402_RES; MPN RC0402JR-076M8L; DIGIKEY YAG3310CT-ND
R21: 9.1M; 0402_RES; MPN RC0402JR-079M1L; DIGIKEY YAG3322CT-ND
R22: 33M; 0603-RES; MPN HMC0603JT33M0; DIGIKEY HMC0603JT33M0CT-ND
U2: BQ25505; S-PVQFN-N20-RGR
U7: MAX17222; UDFN-6-MAXIM

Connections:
!VBAT_PRI_ON: Q6.2 (G), Q6.5 (G), U2.10 (!VBAT_PRI_ON)
!VBAT_SEC_ON: Q5.2 (G), Q5.5 (G), U2.9 (!VBAT_SEC_ON)
GND: BAT1.GND (-), BT1.-, C10.2, C11.2, C28.2, C29.2, C30.2, C31.2, D1.- (V-), R13.1, R18.1, R21.1, U2.1 (GND), U2.5 (!EN), U2.6 (GND), U2.15 (GND), U2.16 (GND), U2.17 (GND), U2.PAD (GND), U7.3 (GND); also elsewhere on the board
LBST: L5.P$1 (1), U2.20 (LBST); also elsewhere on the board
unnamed: R13.2, U7.4 (SEL)
unnamed: R22.1, U7.6 (EN)
unnamed: R14.1, R21.2, U2.7 (VBAT_OV)
unnamed: R4.2, R14.2, U2.8 (VRDIV)
unnamed: Q5.1 (S), Q5.4 (S)
unnamed: Q6.1 (S), Q6.4 (S)
unnamed: R17.1, R18.2, U2.12 (OK_PROG)
unnamed: R4.1, R17.2, U2.11 (OK_HYST)
SW: L3.P$2 (2), U7.2 (LX); also elsewhere on the board
VBAT: BAT1.1 (+), BAT1.2 (+), Q6.6 (D), U2.14 (VBAT_PRI); also elsewhere on the board
VBAT_OK: U2.13 (VBAT_OK); also elsewhere on the board
VCC: C31.1, U7.1 (OUT); also elsewhere on the board
VOC_SAMP_VSTOR: C11.1, C28.1, Q5.6 (D), U2.3 (VOC_SAMP), U2.19 (VSTOR)
VREF_SAMP: C10.1, U2.4 (VREF_SAMP)
VSEC: BT1.+, U2.18 (VBAT_SEC); also elsewhere on the board
VSOL: C29.1, D1.+ (V+), L5.P$2 (2), U2.2 (VIN_DC); also elsewhere on the board
VSW: C30.1, L3.P$1 (1), Q5.3 (D), Q6.3 (D), R22.2, U7.5 (IN)

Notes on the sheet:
Power Supply
Boost Regulator

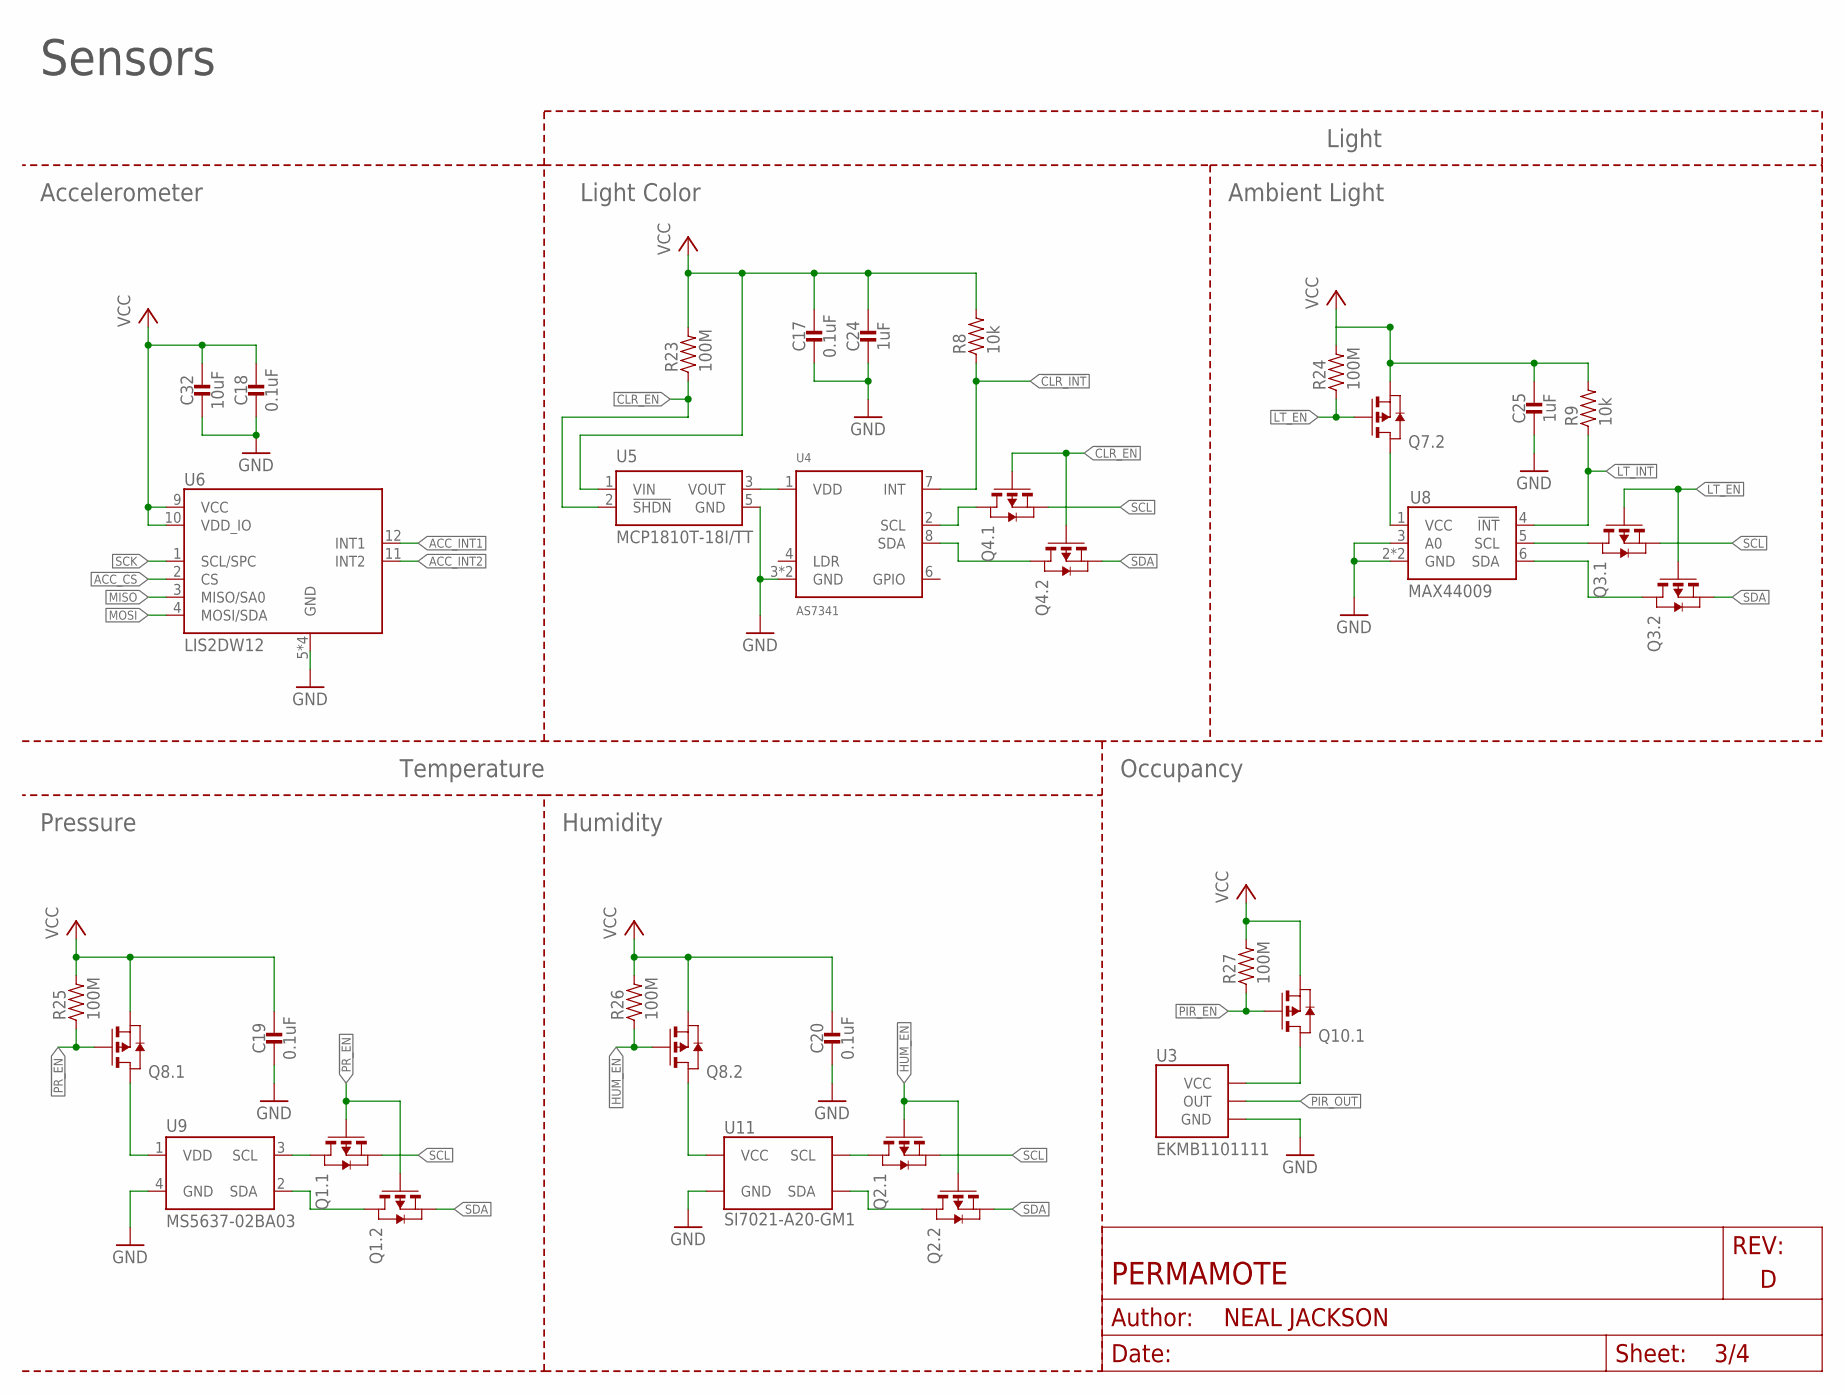
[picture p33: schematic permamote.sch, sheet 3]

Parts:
C17, C18, C19, C20: 0.1uF; 0402_CAP; MPN GRM155R71C104KA88J; DIGIKEY 490-6328-1-ND
C24, C25: 1uF; 0402_CAP; MPN GRM155R70G105KA12D; DIGIKEY 490-7195-1-ND
C32: 10uF; 0603_CAP; MPN GRM188R60J106ME47D; DIGIKEY 490-3896-1-ND
Q1, Q2, Q3, Q4, Q7, Q8, Q10: PMDXB950UPEL; XDFN-6
R8, R9: 10k; 0402_RES; MPN RC0402JR-0710KL; DIGIKEY 311-10KJRCT-ND
R23, R24, R25, R26, R27: 100M; 0402_RES; MPN HMC0402JT100M; DIGIKEY 541-100MAHCT-ND
U3: EKMB1101111; AMN2
U4: AS7341; OLGA-8
U5: MCP1810T-18I/TT; SOT-23-5
U6: LIS2DW12; LGA-12
U8: MAX44009; UDFN-6-EXPOSED
U9: MS5637-02BA03; 4-SMD
U11: SI7021-A20-GM1; DFN-6/3MM; MPN SI7021-A20-GM1

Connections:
!CLR_EN: Q4.2 (G), Q4.5 (G), R23.1, U5.2 (!SHDN); also elsewhere on the board
!CLR_INT: R8.1, U4.7 (INT); also elsewhere on the board
!HUM_EN: Q2.2 (G), Q2.5 (G), Q8.5 (G), R26.1; also elsewhere on the board
!LT_EN: Q3.2 (G), Q3.5 (G), Q7.5 (G), R24.1; also elsewhere on the board
!LT_INT: R9.1, U8.4 (!INT); also elsewhere on the board
!PIR_EN: Q10.2 (G), R27.1; also elsewhere on the board
!PR_EN: Q1.2 (G), Q1.5 (G), Q8.2 (G), R25.1; also elsewhere on the board
ACC_CS: U6.2 (CS); also elsewhere on the board
ACC_INT1: U6.12 (INT1); also elsewhere on the board
ACC_INT2: U6.11 (INT2); also elsewhere on the board
GND: C17.2, C18.2, C19.2, C20.2, C24.2, C25.2, C32.2, U3.GND, U4.3 (GND), U4.5 (GND), U5.5 (GND), U6.5 (GND), U6.6 (GND), U6.7 (GND), U6.8 (GND), U8.2 (GND), U8.3 (A0), U8.EP (GND), U9.4 (GND), U11.2 (GND); also elsewhere on the board
MISO: U6.3 (MISO/SA0); also elsewhere on the board
MOSI: U6.4 (MOSI/SDA); also elsewhere on the board
unnamed: Q4.3 (D), U4.8 (SDA)
unnamed: Q7.3 (D), U8.1 (VCC)
unnamed: Q8.6 (D), U9.1 (VDD)
unnamed: Q8.3 (D), U11.5 (VCC)
unnamed: Q10.6 (D), U3.VCC
unnamed: U4.1 (VDD), U5.3 (VOUT)
unnamed: Q1.6 (D), U9.3 (SCL)
unnamed: Q1.3 (D), U9.2 (SDA)
unnamed: Q2.3 (D), U11.1 (SDA)
unnamed: Q2.6 (D), U11.6 (SCL)
unnamed: Q3.3 (D), U8.6 (SDA)
unnamed: Q3.6 (D), U8.5 (SCL)
unnamed: Q4.6 (D), U4.2 (SCL)
PIR_OUT: U3.OUT; also elsewhere on the board
SCK: U6.1 (SCL/SPC); also elsewhere on the board
SCL: Q1.1 (S), Q2.1 (S), Q3.1 (S), Q4.1 (S); also elsewhere on the board
SDA: Q1.4 (S), Q2.4 (S), Q3.4 (S), Q4.4 (S); also elsewhere on the board
VCC: C17.1, C18.1, C19.1, C20.1, C24.1, C25.1, C32.1, Q7.4 (S), Q8.1 (S), Q8.4 (S), Q10.1 (S), R8.2, R9.2, R23.2, R24.2, R25.2, R26.2, R27.2, U5.1 (VIN), U6.9 (VCC), U6.10 (VDD_IO); also elsewhere on the board

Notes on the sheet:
Sensors
Accelerometer
Temperature
Humidity
Pressure
Ambient Light
Light Color
Light
Occupancy

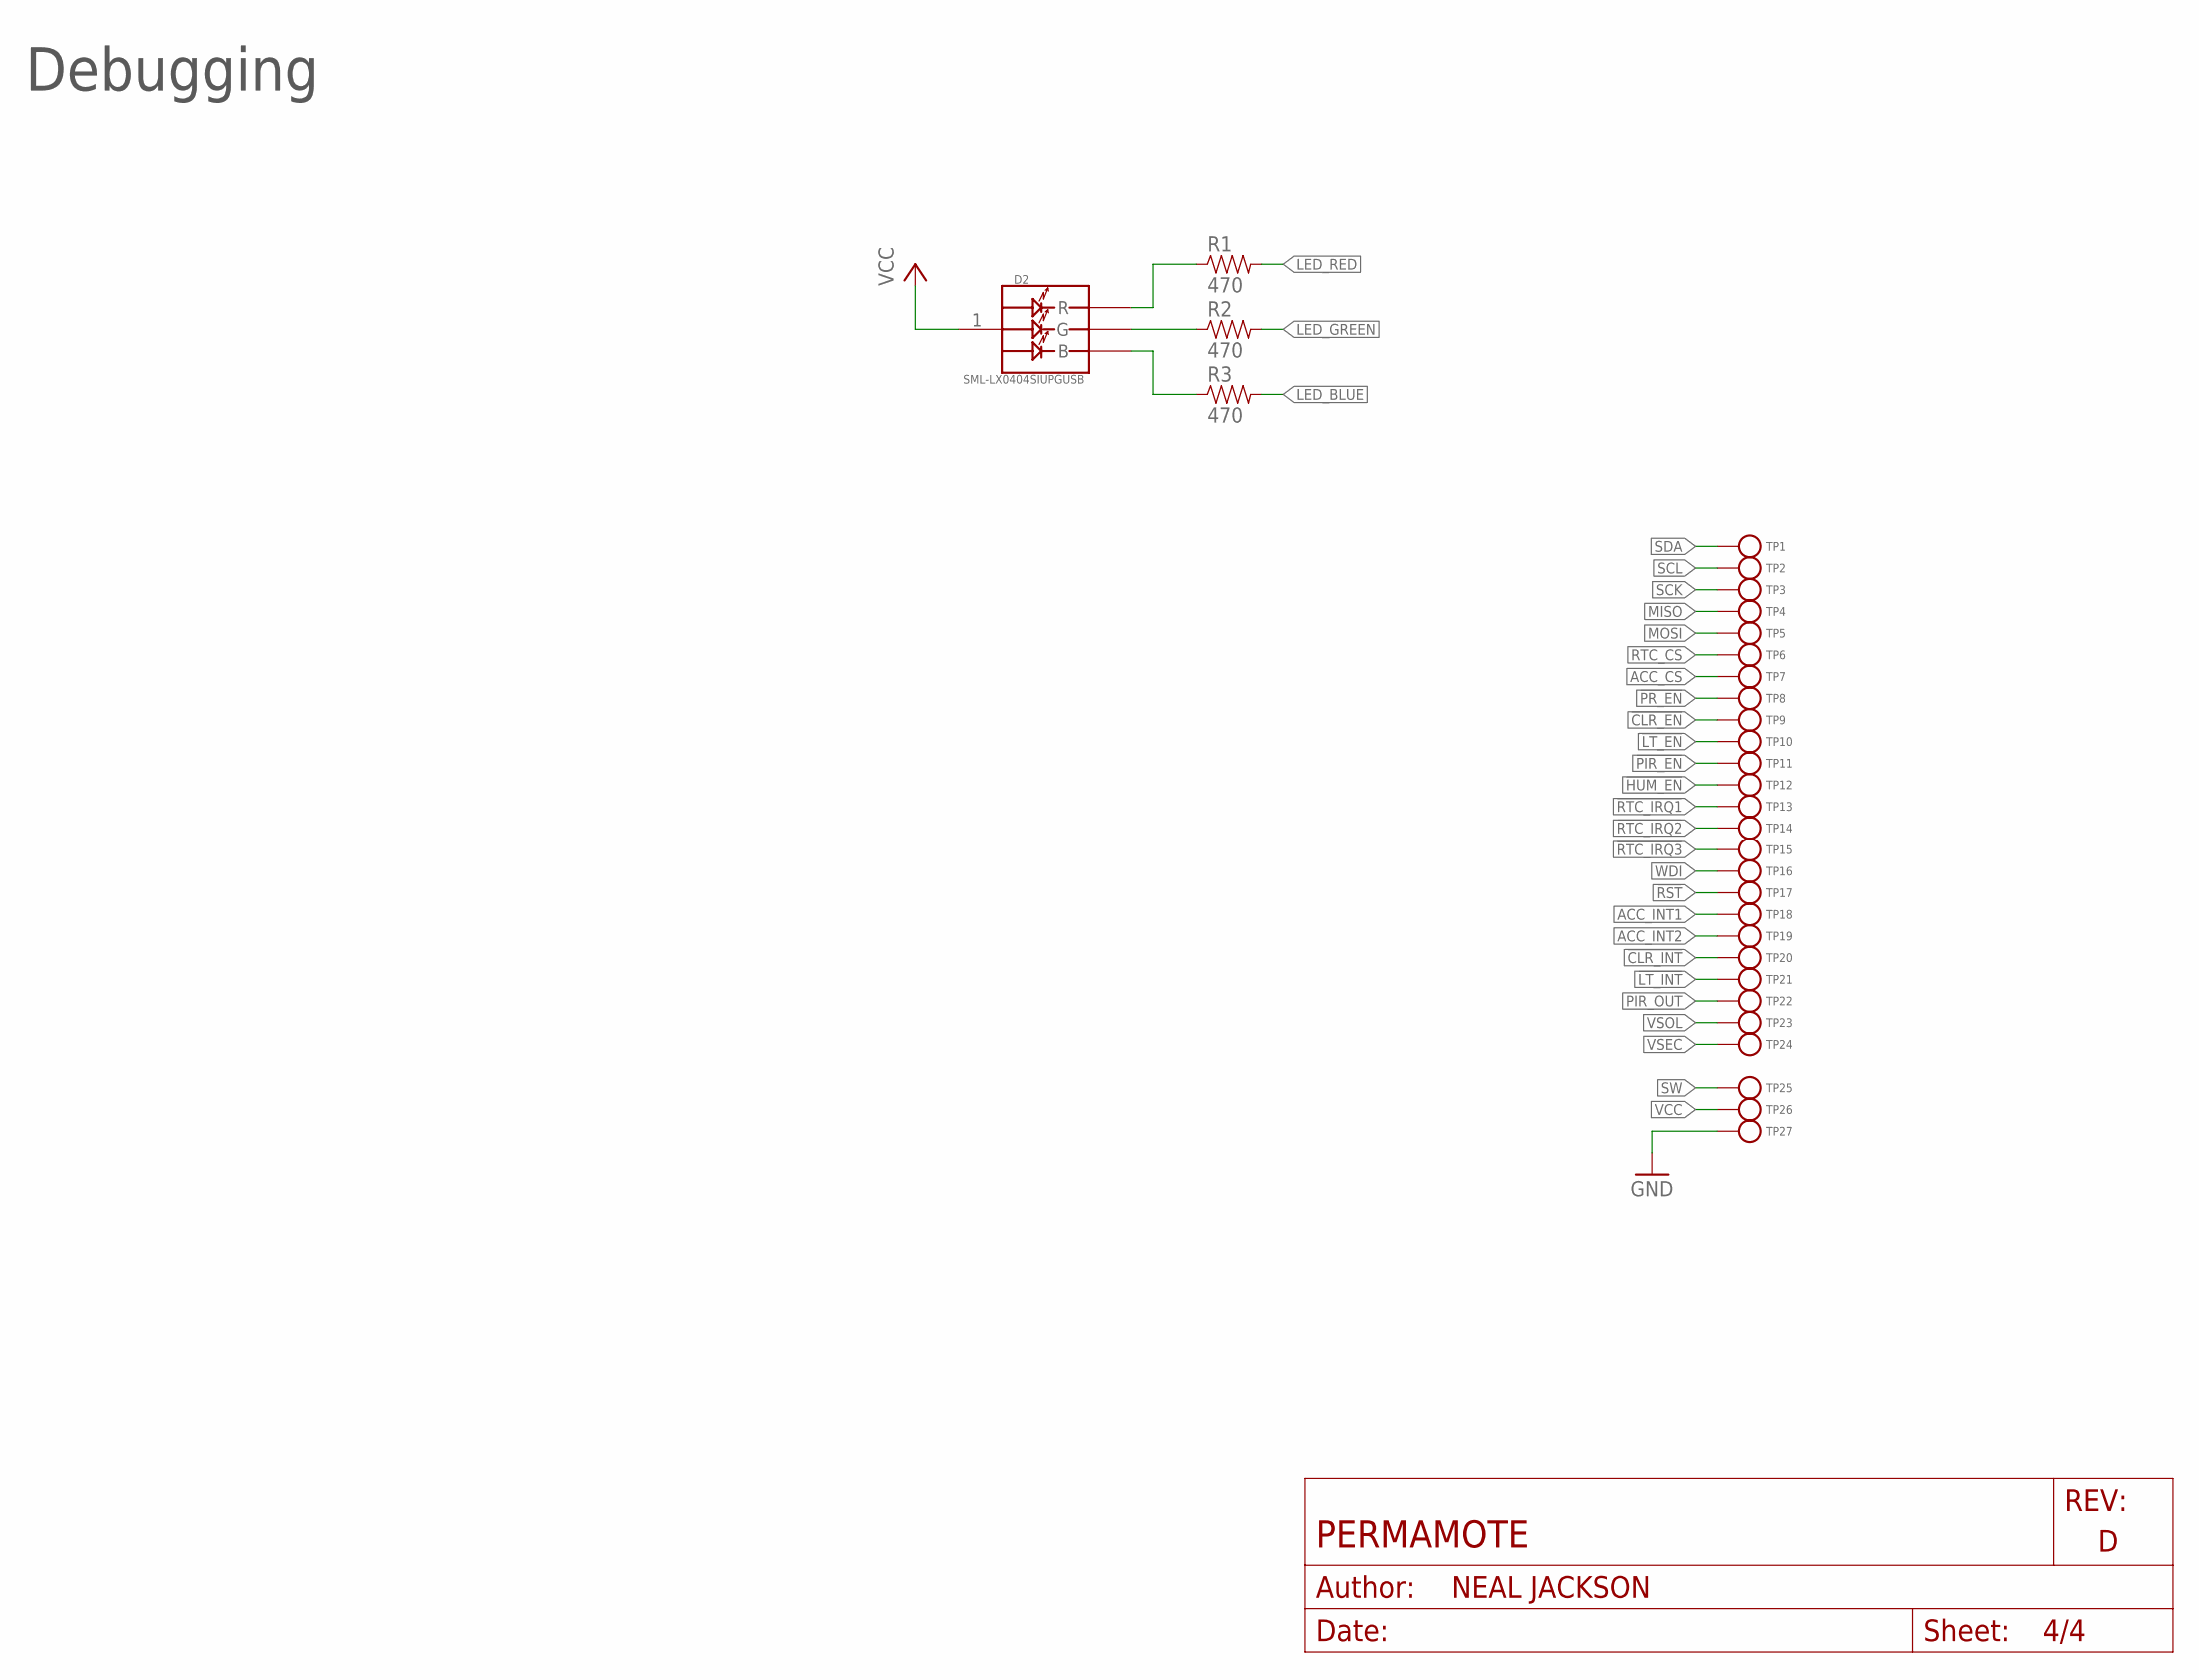
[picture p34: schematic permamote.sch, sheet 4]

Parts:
D2: SML-LX0404SIUPGUSB; 1MM_SQ_4PAD
R1, R2, R3: 470; 0402_RES; MPN RC0402JR-07470RL; DIGIKEY 311-470JRCT-ND
TP1, TP2, TP3, TP4, TP5, TP6, TP7, TP8, TP9, TP10, TP11, TP12, TP13, TP14, TP15, TP16, TP17, TP18, TP19, TP20, TP21, TP22, TP23, TP24, TP25, TP26, TP27: TEST-POINT; PAD.03X.03

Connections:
!CLR_EN: TP9.P$1; also elsewhere on the board
!CLR_INT: TP20.P$1; also elsewhere on the board
!HUM_EN: TP12.P$1; also elsewhere on the board
!LT_EN: TP10.P$1; also elsewhere on the board
!LT_INT: TP21.P$1; also elsewhere on the board
!PIR_EN: TP11.P$1; also elsewhere on the board
!PR_EN: TP8.P$1; also elsewhere on the board
!RST: TP17.P$1; also elsewhere on the board
!RTC_IRQ1: TP13.P$1; also elsewhere on the board
!RTC_IRQ2: TP14.P$1; also elsewhere on the board
!RTC_IRQ3: TP15.P$1; also elsewhere on the board
ACC_CS: TP7.P$1; also elsewhere on the board
ACC_INT1: TP18.P$1; also elsewhere on the board
ACC_INT2: TP19.P$1; also elsewhere on the board
GND: TP27.P$1; also elsewhere on the board
LED_BLUE: R3.2; also elsewhere on the board
LED_GREEN: R2.2; also elsewhere on the board
LED_RED: R1.2; also elsewhere on the board
MISO: TP4.P$1; also elsewhere on the board
MOSI: TP5.P$1; also elsewhere on the board
unnamed: D2.2 (R), R1.1
unnamed: D2.4 (G), R2.1
unnamed: D2.3 (B), R3.1
PIR_OUT: TP22.P$1; also elsewhere on the board
RTC_CS: TP6.P$1; also elsewhere on the board
SCK: TP3.P$1; also elsewhere on the board
SCL: TP2.P$1; also elsewhere on the board
SDA: TP1.P$1; also elsewhere on the board
SW: TP25.P$1; also elsewhere on the board
VCC: D2.1 (VDD), TP26.P$1; also elsewhere on the board
VSEC: TP24.P$1; also elsewhere on the board
VSOL: TP23.P$1; also elsewhere on the board
WDI: TP16.P$1; also elsewhere on the board

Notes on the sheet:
Debugging

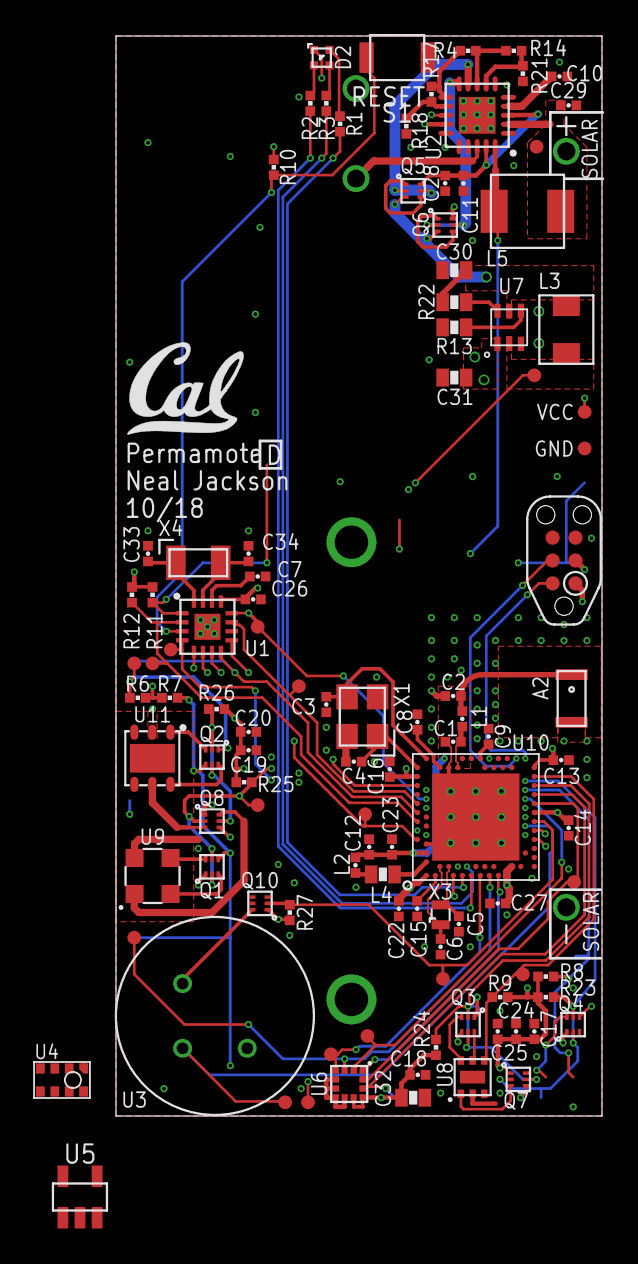
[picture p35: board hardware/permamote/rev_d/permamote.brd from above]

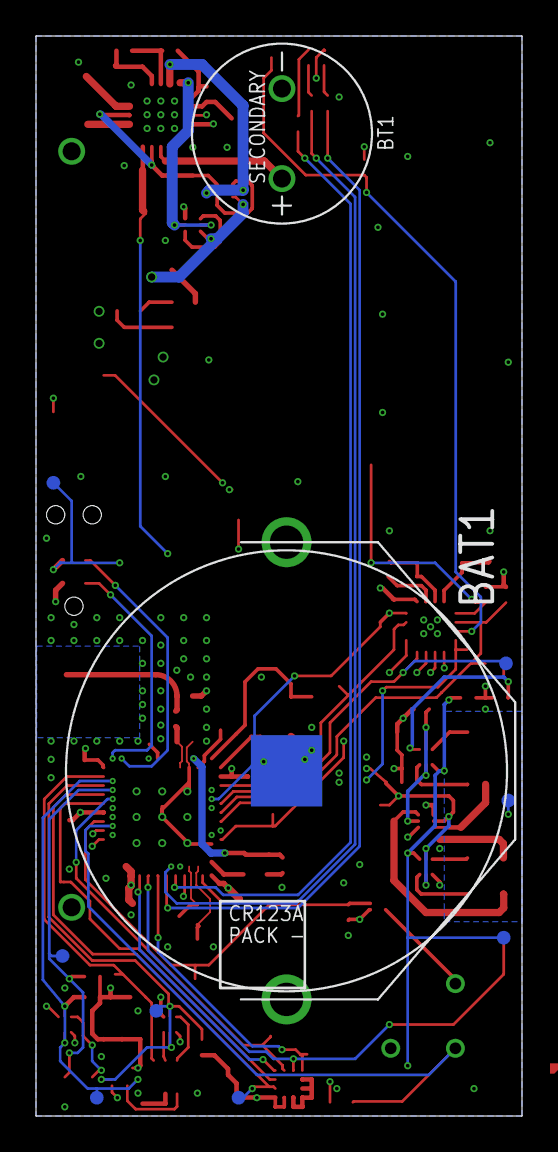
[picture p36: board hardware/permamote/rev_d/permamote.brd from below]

Board: 4 copper layers, 27.0 x 60.0 mm, 118 parts (10 on the bottom side), 80 nets.

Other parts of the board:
U$2: UCB_CAL_200MIL

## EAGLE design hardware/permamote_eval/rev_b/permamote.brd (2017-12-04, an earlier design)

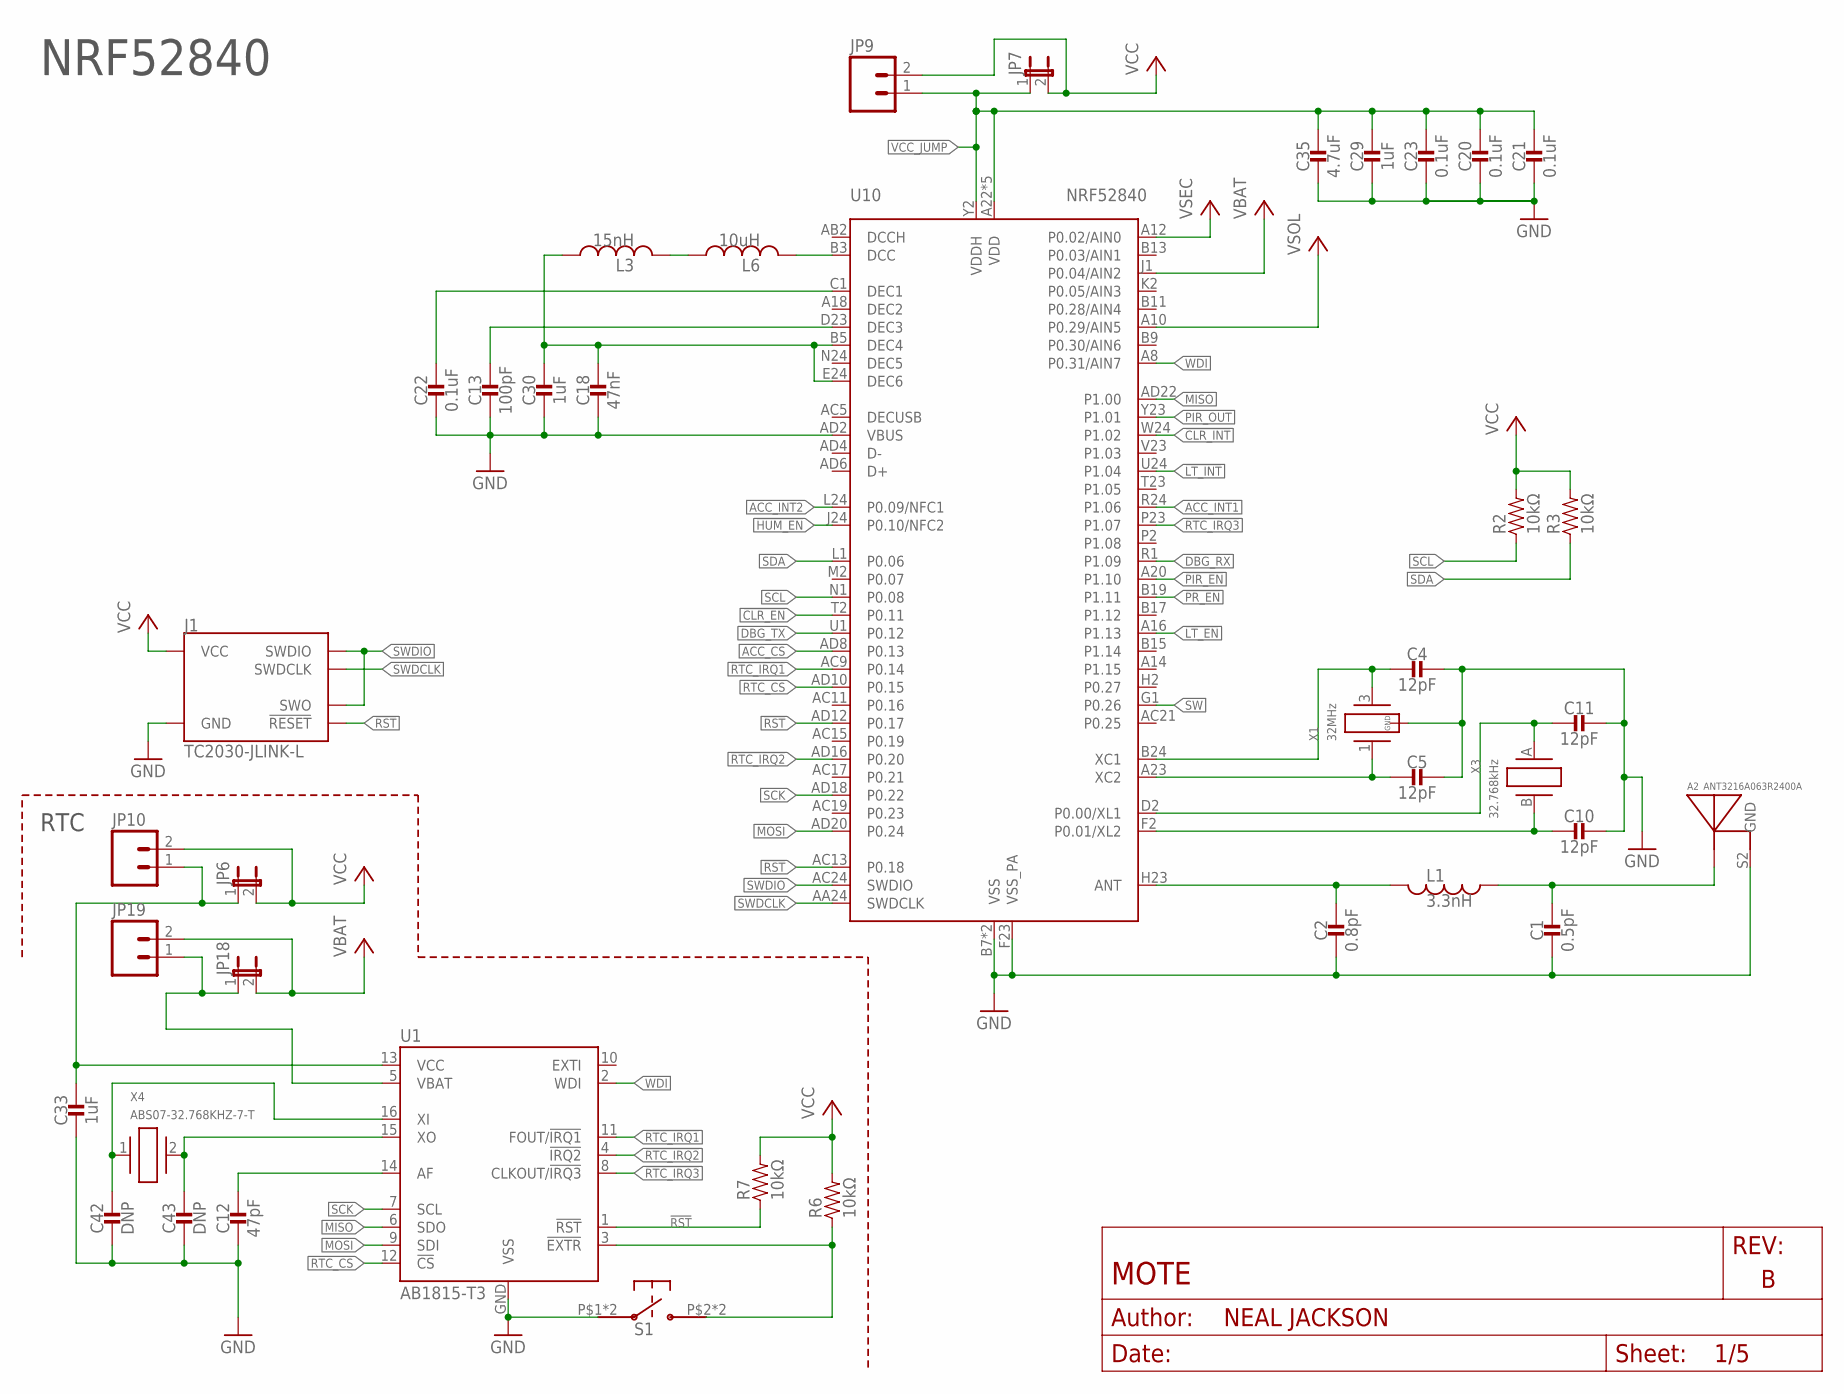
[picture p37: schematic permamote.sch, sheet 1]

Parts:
A2: ANT3216A063R2400A
C1: 0.5pF; 0402_CAP; DIGIKEY 490-6264-1-ND
C2: 0.8pF; 0402_CAP; DIGIKEY 490-6269-1-ND
C4, C5, C10, C11: 12pF; 0402_CAP; DIGIKEY 490-6197-1-ND
C12: 47pF; 0402_CAP; DIGIKEY 490-5942-1-ND
C13: 100pF; 0402_CAP; DIGIKEY 490-5922-1-ND
C18: 47nF; 0402_CAP; DIGIKEY 445-1264-1-ND
C20, C21, C22, C23: 0.1uF; 0402_CAP; DIGIKEY 490-6328-1-ND
C29, C30, C33: 1uF; 0402_CAP; DIGIKEY 490-7195-1-ND
C35: 4.7uF; 0402_CAP; DIGIKEY 445-5947-1-ND
C42, C43: DNP; 0402_CAP
J1: TC2030-JLINK-L; TC2030-IDC
JP6, JP7, JP18: JUMPER-2SMD-NC; SJ_2S
JP9, JP10, JP19: M02PTH; 1X02
L1: 3.3nH; 0402_CAP; DIGIKEY 535-10426-1-ND
L3: 15nH; 0402_CAP; DIGIKEY 587-1521-1-ND
L6: 10uH; 0603_CAP; DIGIKEY 490-4025-1-ND
R2, R3, R6, R7: 10kΩ; 0402_RES; DIGIKEY 311-10KJRCT-ND
S1: EVQP2
U1: AB1815-T3; QFN-16-3MM
U10: NRF52840; AQFN73
X1: 32MHz; TXC-7V
X3: 32.768kHz; ABS05
X4: ABS07-32.768KHZ-7-T; 2-SMD

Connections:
!CLR_EN: U10.T2 (P0.11); also elsewhere on the board
!CLR_INT: U10.W24 (P1.02); also elsewhere on the board
!HUM_EN: U10.J24 (P0.10/NFC2); also elsewhere on the board
!LT_EN: U10.A16 (P1.13); also elsewhere on the board
!LT_INT: U10.U24 (P1.04); also elsewhere on the board
!PIR_EN: U10.A20 (P1.10); also elsewhere on the board
!PR_EN: U10.B19 (P1.11); also elsewhere on the board
!RST: J1.3 (!RESET), R7.1, U1.1 (!RST), U10.AC13 (P0.18), U10.AD12 (P0.17); also elsewhere on the board
!RTC_EXTR: R6.1, S1.P$2, S1.P$4, U1.3 (!EXTR)
!RTC_IRQ1: U1.11 (FOUT/!IRQ1), U10.AC9 (P0.14); also elsewhere on the board
!RTC_IRQ2: U1.4 (!IRQ2), U10.AD16 (P0.20); also elsewhere on the board
!RTC_IRQ3: U1.8 (CLKOUT/!IRQ3), U10.P23 (P1.07); also elsewhere on the board
ACC_CS: U10.AD8 (P0.13); also elsewhere on the board
ACC_INT1: U10.R24 (P1.06); also elsewhere on the board
ACC_INT2: U10.L24 (P0.09/NFC1); also elsewhere on the board
DBG_RX: U10.R1 (P1.09); also elsewhere on the board
DBG_TX: U10.U1 (P0.12); also elsewhere on the board
GND: A2.S2 (GND), C1.2, C2.2, C4.1, C5.1, C10.1, C11.1, C12.2, C13.2, C18.2, C20.2, C21.2, C22.2, C23.2, C29.2, C30.2, C33.2, C35.2, C42.2, C43.2, J1.5 (GND), S1.P$1, S1.P$3, U1.GND (VSS), U10.AD2 (VBUS), U10.B7 (VSS), U10.F23 (VSS_PA), U10.GND (VSS), X1.2 (GND), X1.4 (GND); also elsewhere on the board
MISO: U1.6 (SDO), U10.AD22 (P1.00); also elsewhere on the board
MOSI: U1.9 (SDI), U10.AD20 (P0.24); also elsewhere on the board
unnamed: C22.1, U10.C1 (DEC1)
unnamed: C18.1, C30.1, L3.1, U10.B5 (DEC4), U10.E24 (DEC6)
unnamed: C13.1, U10.D23 (DEC3)
unnamed: C2.1, L1.2, U10.H23 (ANT)
unnamed: A2.S1 (ANTENNA), C1.1, L1.1
unnamed: C4.2, U10.B24 (XC1), X1.3 (2)
unnamed: C5.2, U10.A23 (XC2), X1.1
unnamed: C12.1, U1.14 (AF)
unnamed: C42.1, U1.16 (XI), X4.1
unnamed: C43.1, U1.15 (XO), X4.2
unnamed: C33.1, JP6.1, JP10.1, U1.13 (VCC)
unnamed: L6.2, U10.B3 (DCC)
unnamed: L3.2, L6.1
unnamed: JP18.1, JP19.1, U1.5 (VBAT)
PIR_OUT: U10.Y23 (P1.01); also elsewhere on the board
RTC_CS: U1.12 (!CS), U10.AD10 (P0.15); also elsewhere on the board
SCK: U1.7 (SCL), U10.AD18 (P0.22); also elsewhere on the board
SCL: R2.1, U10.N1 (P0.08); also elsewhere on the board
SDA: R3.1, U10.L1 (P0.06); also elsewhere on the board
SW: U10.G1 (P0.26); also elsewhere on the board
SWDCLK: J1.4 (SWDCLK), U10.AA24 (SWDCLK); also elsewhere on the board
SWDIO: J1.2 (SWDIO), J1.6 (SWO), U10.AC24 (SWDIO); also elsewhere on the board
VBAT: JP18.2, JP19.2, U10.J1 (P0.04/AIN2); also elsewhere on the board
VCC: J1.1 (VCC), JP6.2, JP7.2, JP9.2, JP10.2, R2.2, R3.2, R6.2, R7.2; also elsewhere on the board
VCC_JUMP: C20.1, C21.1, C23.1, C29.1, C35.1, JP7.1, JP9.1, U10.A22 (VDD), U10.AD14 (VDD), U10.AD23 (VDD), U10.B1 (VDD), U10.W1 (VDD), U10.Y2 (VDDH); also elsewhere on the board
VSEC: U10.A12 (P0.02/AIN0); also elsewhere on the board
VSOL: U10.A10 (P0.29/AIN5); also elsewhere on the board
WDI: U1.2 (WDI), U10.A8 (P0.31/AIN7); also elsewhere on the board
XL1: C11.2, U10.D2 (P0.00/XL1), X3.A (1)
XL2: C10.2, U10.F2 (P0.01/XL2), X3.B (2)

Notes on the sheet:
NRF52840
RTC

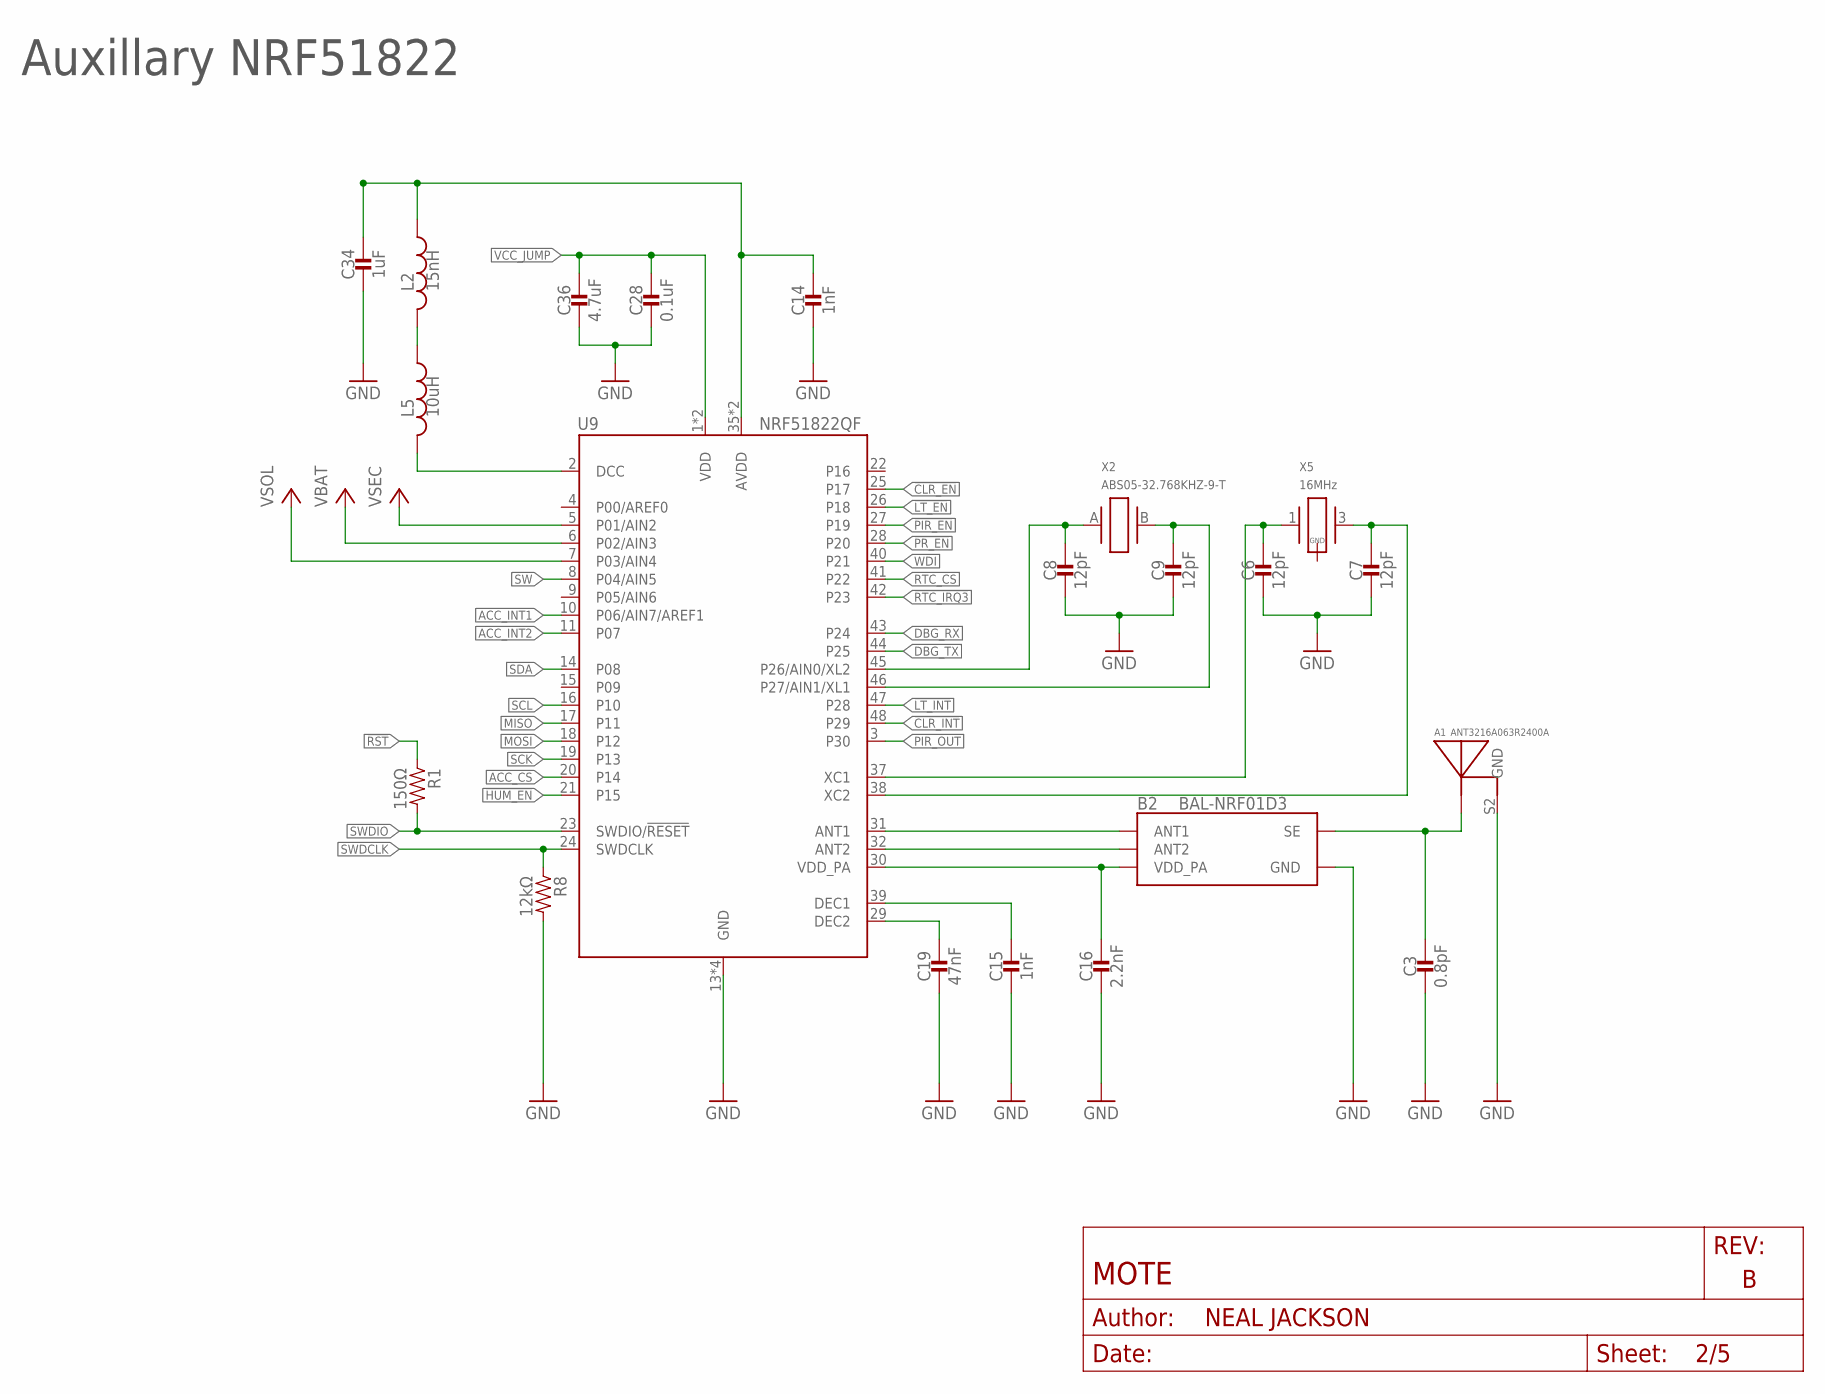
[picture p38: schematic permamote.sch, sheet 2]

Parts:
A1: ANT3216A063R2400A
B2: BAL-NRF01D3
C3: 0.8pF; 0402_CAP; DIGIKEY 490-6269-1-ND
C6, C7, C8, C9: 12pF; 0402_CAP; DIGIKEY 490-6197-1-ND
C14, C15: 1nF; 0402_CAP; DIGIKEY 490-1303-1-ND
C16: 2.2nF; 0402_CAP; DIGIKEY 490-5419-1-ND
C19: 47nF; 0402_CAP; DIGIKEY 445-1264-1-ND
C28: 0.1uF; 0402_CAP; DIGIKEY 490-6328-1-ND
C34: 1uF; 0402_CAP; DIGIKEY 490-7195-1-ND
C36: 4.7uF; 0402_CAP; DIGIKEY 445-5947-1-ND
L2: 15nH; 0402_CAP; DIGIKEY 587-1521-1-ND
L5: 10uH; 0603_CAP; DIGIKEY 490-4025-1-ND
R1: 150Ω; 0402_RES; DIGIKEY 311-150JRCT-ND
R8: 12kΩ; 0402_RES; DIGIKEY RHM12.0KCDCT-ND
U9: NRF51822QF; QFN-48-6MM
X2: ABS05-32.768KHZ-9-T; ABS05
X5: 16MHz; TXC-8Y; DIGIKEY 887-2003-1-ND

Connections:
!CLR_EN: U9.25 (P17); also elsewhere on the board
!CLR_INT: U9.48 (P29); also elsewhere on the board
!HUM_EN: U9.21 (P15); also elsewhere on the board
!LT_EN: U9.26 (P18); also elsewhere on the board
!LT_INT: U9.47 (P28); also elsewhere on the board
!PIR_EN: U9.27 (P19); also elsewhere on the board
!PR_EN: U9.28 (P20); also elsewhere on the board
!RST: R1.1; also elsewhere on the board
!RTC_IRQ3: U9.42 (P23); also elsewhere on the board
ACC_CS: U9.20 (P14); also elsewhere on the board
ACC_INT1: U9.10 (P06/AIN7/AREF1); also elsewhere on the board
ACC_INT2: U9.11 (P07); also elsewhere on the board
AVDD1: C14.1, C34.1, L2.1, U9.35 (AVDD), U9.36 (AVDD)
DBG_RX: U9.43 (P24); also elsewhere on the board
DBG_TX: U9.44 (P25); also elsewhere on the board
DCC1: L5.2, U9.2 (DCC)
GND: A1.S2 (GND), B2.GND, C3.2, C6.2, C7.2, C8.2, C9.2, C14.2, C15.2, C16.2, C19.2, C28.2, C34.2, C36.2, R8.2, U9.13 (GND), U9.33 (GND), U9.34 (GND), U9.GND; also elsewhere on the board
MISO: U9.17 (P11); also elsewhere on the board
MOSI: U9.18 (P12); also elsewhere on the board
unnamed: B2.ANT1, U9.31 (ANT1)
unnamed: B2.ANT2, U9.32 (ANT2)
unnamed: A1.S1 (ANTENNA), B2.SE, C3.1
unnamed: L2.2, L5.1
unnamed: C6.1, U9.37 (XC1), X5.1
unnamed: C7.1, U9.38 (XC2), X5.3 (2)
unnamed: C15.1, U9.39 (DEC1)
unnamed: C19.1, U9.29 (DEC2)
NRF_A2: C9.1, U9.46 (P27/AIN1/XL1), X2.B (2)
NRF_A3: C8.1, U9.45 (P26/AIN0/XL2), X2.A (1)
PIR_OUT: U9.3 (P30); also elsewhere on the board
RTC_CS: U9.41 (P22); also elsewhere on the board
SCK: U9.19 (P13); also elsewhere on the board
SCL: U9.16 (P10); also elsewhere on the board
SDA: U9.14 (P08); also elsewhere on the board
SW: U9.8 (P04/AIN5); also elsewhere on the board
SWDCLK: R8.1, U9.24 (SWDCLK); also elsewhere on the board
SWDIO: R1.2, U9.23 (SWDIO/!RESET); also elsewhere on the board
VBAT: U9.6 (P02/AIN3); also elsewhere on the board
VCC_JUMP: C28.1, C36.1, U9.1 (VDD), U9.12 (VDD); also elsewhere on the board
VDD_PA1: B2.VCC (VDD_PA), C16.1, U9.30 (VDD_PA)
VSEC: U9.5 (P01/AIN2); also elsewhere on the board
VSOL: U9.7 (P03/AIN4); also elsewhere on the board
WDI: U9.40 (P21); also elsewhere on the board

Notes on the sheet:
Auxillary NRF51822

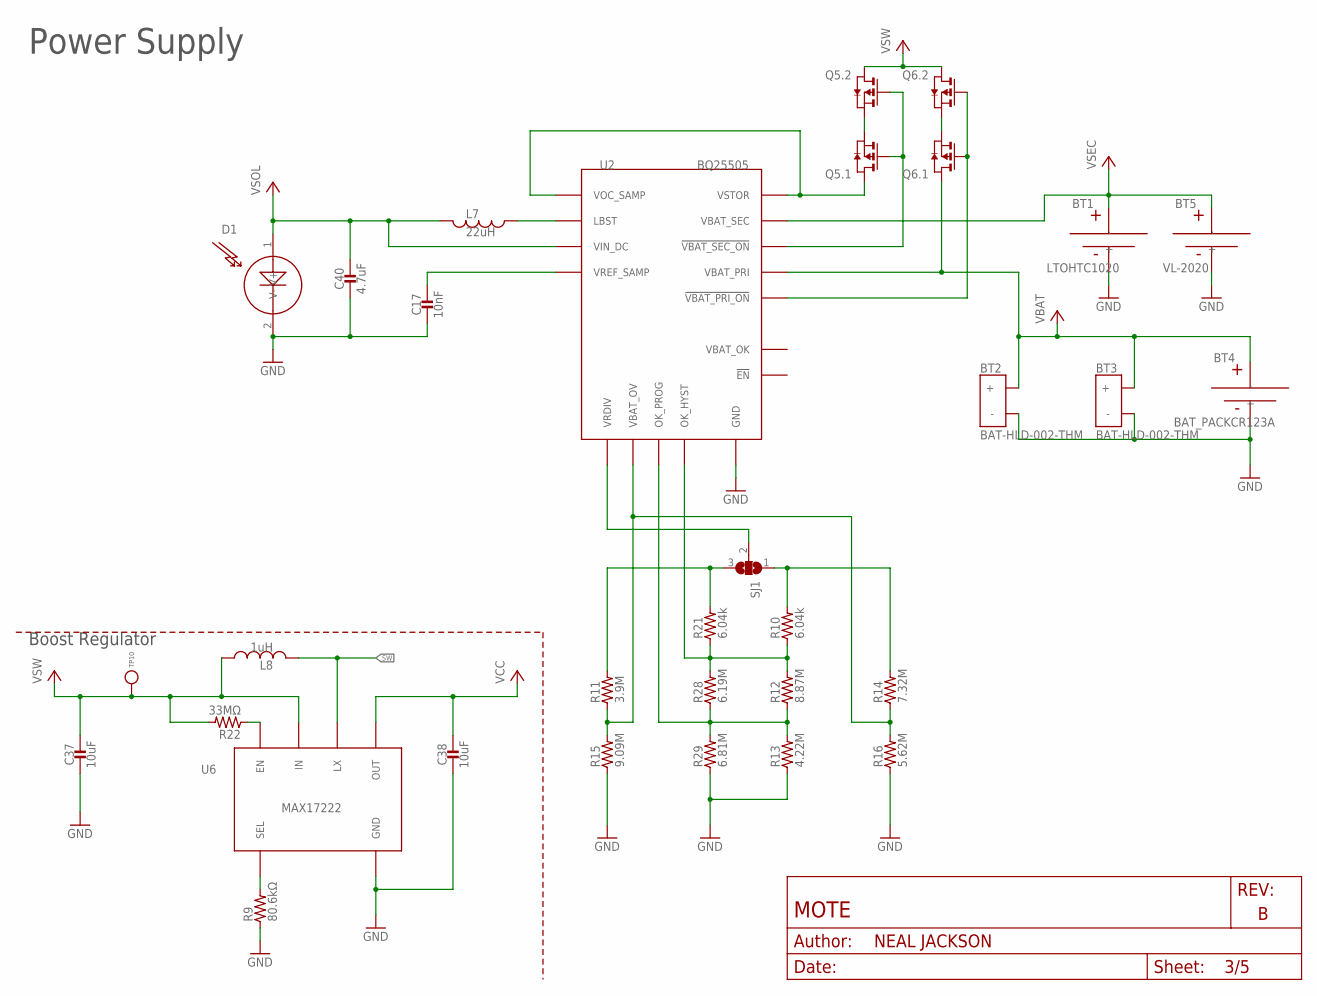
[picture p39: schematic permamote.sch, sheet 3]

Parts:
BT1: LTOHTC1020; 1020
BT2, BT3: BAT-HLD-002-THM
BT4: BAT_PACKCR123A; BH123A
BT5: VL-2020
C17: 10nF; 0402_CAP; DIGIKEY 490-4516-1-ND
C37, C38: 10uF; 0603_CAP; DIGIKEY 490-3896-1-ND
C40: 4.7uF; 0603_CAP; DIGIKEY 490-3896-1-ND
D1: SOLARCELLSCREW; PHEONIX-1935161
L7: 22uH; 74437324220; DIGIKEY 732-3340-1-ND
L8: 1uH; IHL-1212BZ-11; MPN IHLP1212BZER1R0M11; DIGIKEY 541-1319-1-ND
Q5, Q6: PMDXB950UPEL; XDFN-6
R9: 80.6kΩ; 0603-RES; DIGIKEY 311-80.6KHRCT-ND
R10, R21: 6.04k; 0402_RES; DIGIKEY YAG3306CT-ND
R11: 3.9M; 0402_RES; DIGIKEY YAG3306CT-ND
R12: 8.87M; 0402_RES; DIGIKEY YAG3306CT-ND
R13: 4.22M; 0402_RES; DIGIKEY YAG3306CT-ND
R14: 7.32M; 0402_RES; DIGIKEY YAG3306CT-ND
R15: 9.09M; 0402_RES; DIGIKEY YAG3306CT-ND
R16: 5.62M; 0402_RES; DIGIKEY YAG3306CT-ND
R22: 33MΩ; 0603-RES; DIGIKEY HMC0603JT33M0CT-ND
R28: 6.19M; 0402_RES; DIGIKEY YAG3306CT-ND
R29: 6.81M; 0402_RES; DIGIKEY YAG3306CT-ND
SJ1: SJ2W; SJ_2
TP10: TEST_POINT_0.040IN; TESTPOINT_0.040IN
U2: BQ25505; S-PVQFN-N20-RGR
U6: MAX17222; UDFN-6-MAXIM

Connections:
!VBAT_PRI_ON: Q6.2 (G), Q6.5 (G), U2.10 (!VBAT_PRI_ON)
!VBAT_SEC_ON: Q5.2 (G), Q5.5 (G), U2.9 (!VBAT_SEC_ON)
GND: BT1.-, BT2.GND (-), BT3.GND (-), BT4.-, BT5.-, C17.2, C37.2, C38.2, C40.2, D1.2 (V-), R9.1, R13.1, R15.1, R16.1, R29.1, U2.1 (GND), U2.6 (GND), U2.15 (GND), U2.16 (GND), U2.17 (GND), U2.PAD (GND), U6.3 (GND); also elsewhere on the board
unnamed: R11.2, R21.2, SJ1.3
unnamed: R9.2, U6.4 (SEL)
unnamed: R22.1, U6.6 (EN)
unnamed: R10.2, R14.2, SJ1.1
unnamed: R11.1, R14.1, R15.2, R16.2, U2.7 (VBAT_OV)
unnamed: C17.1, U2.4 (VREF_SAMP)
unnamed: SJ1.2, U2.8 (VRDIV)
unnamed: L7.P$1 (1), U2.20 (LBST)
unnamed: Q5.1 (S), Q5.4 (S)
unnamed: Q5.6 (D), U2.3 (VOC_SAMP), U2.19 (VSTOR)
unnamed: Q6.1 (S), Q6.4 (S)
unnamed: R12.1, R13.2, R28.1, R29.2, U2.12 (OK_PROG)
unnamed: R10.1, R12.2, R21.1, R28.2, U2.11 (OK_HYST)
SW: L8.P$2 (2), U6.2 (LX); also elsewhere on the board
VBAT: BT2.POS1 (+), BT2.POS2 (+), BT2.POS3 (+), BT2.POS4 (+), BT3.POS1 (+), BT3.POS2 (+), BT3.POS3 (+), BT3.POS4 (+), BT4.+, Q6.6 (D), U2.14 (VBAT_PRI); also elsewhere on the board
VCC: C38.1, U6.1 (OUT); also elsewhere on the board
VSEC: BT1.+, BT5.+, U2.18 (VBAT_SEC); also elsewhere on the board
VSOL: C40.1, D1.1 (V+), L7.P$2 (2), U2.2 (VIN_DC); also elsewhere on the board
VSW: C37.1, L8.P$1 (1), Q5.3 (D), Q6.3 (D), R22.2, TP10.TESTPOINT, U6.5 (IN)

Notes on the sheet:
Power Supply
Boost Regulator

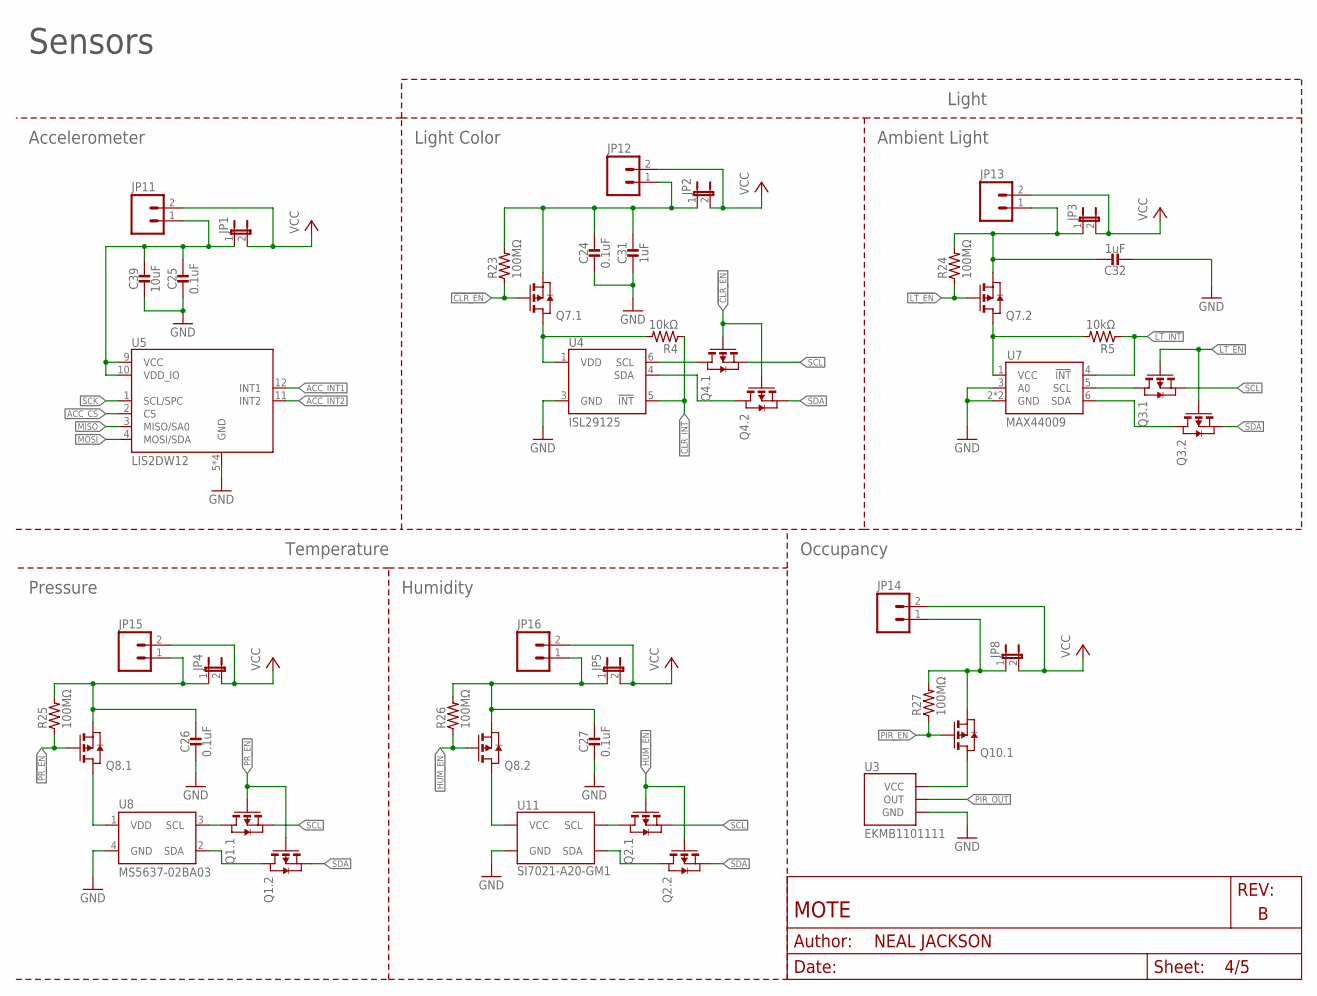
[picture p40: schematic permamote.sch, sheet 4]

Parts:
C24, C25, C26, C27: 0.1uF; 0402_CAP; DIGIKEY 490-6328-1-ND
C31, C32: 1uF; 0402_CAP; DIGIKEY 490-7195-1-ND
C39: 10uF; 0603_CAP; DIGIKEY 490-3896-1-ND
JP1, JP2, JP3, JP4, JP5, JP8: JUMPER-2SMD-NC; SJ_2S
JP11, JP12, JP13, JP14, JP15, JP16: M02PTH; 1X02
Q1, Q2, Q3, Q4, Q7, Q8, Q10: PMDXB950UPEL; XDFN-6
R4, R5: 10kΩ; 0402_RES; DIGIKEY 311-10KJRCT-ND
R23, R24, R25, R26, R27: 100MΩ; 0402_RES; DIGIKEY 541-100MAHCT-ND
U3: EKMB1101111; AMN2
U4: ISL29125; ODFN-6-1.5MMX1.6MM
U5: LIS2DW12; LGA-12
U7: MAX44009; UDFN-6-EXPOSED
U8: MS5637-02BA03; 4-SMD
U11: SI7021-A20-GM1; DFN-6/3MM

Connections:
!CLR_EN: Q4.2 (G), Q4.5 (G), Q7.2 (G), R23.1; also elsewhere on the board
!CLR_INT: R4.1, U4.5 (!INT); also elsewhere on the board
!HUM_EN: Q2.2 (G), Q2.5 (G), Q8.5 (G), R26.1; also elsewhere on the board
!LT_EN: Q3.2 (G), Q3.5 (G), Q7.5 (G), R24.1; also elsewhere on the board
!LT_INT: R5.1, U7.4 (!INT); also elsewhere on the board
!PIR_EN: Q10.2 (G), R27.1; also elsewhere on the board
!PR_EN: Q1.2 (G), Q1.5 (G), Q8.2 (G), R25.1; also elsewhere on the board
ACC_CS: U5.2 (CS); also elsewhere on the board
ACC_INT1: U5.12 (INT1); also elsewhere on the board
ACC_INT2: U5.11 (INT2); also elsewhere on the board
GND: C24.2, C25.2, C26.2, C27.2, C31.2, C32.2, C39.2, U3.GND, U4.3 (GND), U5.5 (GND), U5.6 (GND), U5.7 (GND), U5.8 (GND), U7.2 (GND), U7.3 (A0), U7.EP (GND), U8.4 (GND), U11.2 (GND); also elsewhere on the board
MISO: U5.3 (MISO/SA0); also elsewhere on the board
MOSI: U5.4 (MOSI/SDA); also elsewhere on the board
unnamed: C25.1, C39.1, JP1.1, JP11.1, U5.9 (VCC), U5.10 (VDD_IO)
unnamed: C26.1, JP4.1, JP15.1, Q8.1 (S), R25.2
unnamed: Q8.6 (D), U8.1 (VDD)
unnamed: Q8.3 (D), U11.5 (VCC)
unnamed: Q10.6 (D), U3.VCC
unnamed: JP8.1, JP14.1, Q10.1 (S), R27.2
unnamed: Q7.6 (D), R4.2, U4.1 (VDD)
unnamed: C24.1, C31.1, JP2.1, JP12.1, Q7.1 (S), R23.2
unnamed: Q1.6 (D), U8.3 (SCL)
unnamed: C27.1, JP5.1, JP16.1, Q8.4 (S), R26.2
unnamed: C32.1, JP3.1, JP13.1, Q7.4 (S), R24.2
unnamed: Q1.3 (D), U8.2 (SDA)
unnamed: Q2.3 (D), U11.1 (SDA)
unnamed: Q2.6 (D), U11.6 (SCL)
unnamed: Q3.3 (D), U7.6 (SDA)
unnamed: Q3.6 (D), U7.5 (SCL)
unnamed: Q4.3 (D), U4.4 (SDA)
unnamed: Q4.6 (D), U4.6 (SCL)
unnamed: Q7.3 (D), R5.2, U7.1 (VCC)
PIR_OUT: U3.OUT; also elsewhere on the board
SCK: U5.1 (SCL/SPC); also elsewhere on the board
SCL: Q1.1 (S), Q2.1 (S), Q3.1 (S), Q4.1 (S); also elsewhere on the board
SDA: Q1.4 (S), Q2.4 (S), Q3.4 (S), Q4.4 (S); also elsewhere on the board
VCC: JP1.2, JP2.2, JP3.2, JP4.2, JP5.2, JP8.2, JP11.2, JP12.2, JP13.2, JP14.2, JP15.2, JP16.2; also elsewhere on the board

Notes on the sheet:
Sensors
Accelerometer
Temperature
Humidity
Pressure
Ambient Light
Light Color
Light
Occupancy

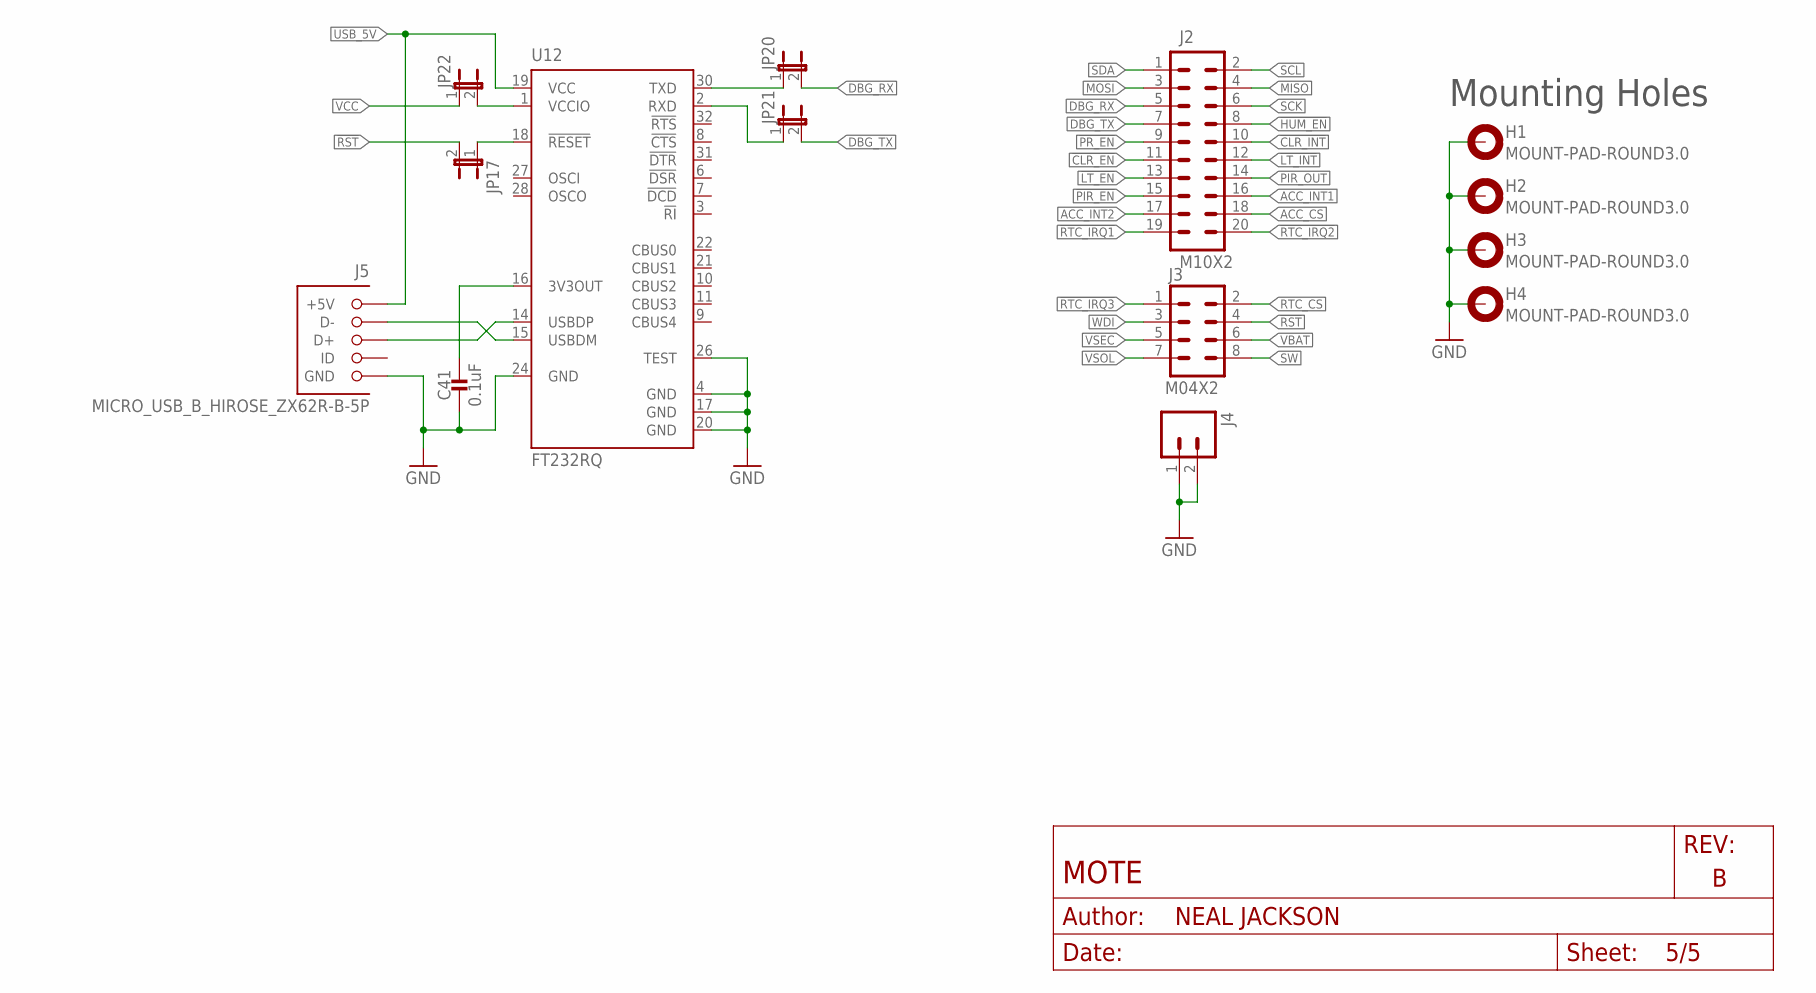
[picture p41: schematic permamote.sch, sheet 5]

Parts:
C41: 0.1uF; 0402_CAP; DIGIKEY 490-6328-1-ND
H1, H2, H3, H4: MOUNT-PAD-ROUND3.0; 3,0-PAD
J2: M10X2; 2X10
J3: M04X2; 2X4
J4: M02PTH; 1X02
J5: MICRO_USB_B_HIROSE_ZX62R-B-5P; USB_MICRO_B-HIROSE-ZX62R-B-5P
JP17: JUMPER-2SMD-NO; SJ_2S-NO
JP20, JP21, JP22: JUMPER-2SMD-NC; SJ_2S
U12: FT232RQ; QFN32

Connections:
3V3OUT: C41.1, U12.16 (3V3OUT)
!CLR_EN: J2.11; also elsewhere on the board
!CLR_INT: J2.10; also elsewhere on the board
!HUM_EN: J2.8; also elsewhere on the board
!LT_EN: J2.13; also elsewhere on the board
!LT_INT: J2.12; also elsewhere on the board
!PIR_EN: J2.15; also elsewhere on the board
!PR_EN: J2.9; also elsewhere on the board
!RST: J3.4, JP17.2; also elsewhere on the board
!RTC_IRQ1: J2.19; also elsewhere on the board
!RTC_IRQ2: J2.20; also elsewhere on the board
!RTC_IRQ3: J3.1; also elsewhere on the board
ACC_CS: J2.18; also elsewhere on the board
ACC_INT1: J2.16; also elsewhere on the board
ACC_INT2: J2.17; also elsewhere on the board
D+: J5.3 (D+), U12.14 (USBDP)
D-: J5.2 (D-), U12.15 (USBDM)
DBG_RX: J2.5, JP20.2; also elsewhere on the board
DBG_TX: J2.7, JP21.2; also elsewhere on the board
GND: C41.2, H1.B3,0, H2.B3,0, H3.B3,0, H4.B3,0, J4.1, J4.2, J5.5 (GND), U12.4 (GND), U12.17 (GND), U12.20 (GND), U12.24 (GND), U12.26 (TEST); also elsewhere on the board
MISO: J2.4; also elsewhere on the board
MOSI: J2.3; also elsewhere on the board
unnamed: JP22.2, U12.1 (VCCIO)
unnamed: JP17.1, U12.18 (!RESET)
PIR_OUT: J2.14; also elsewhere on the board
RTC_CS: J3.2; also elsewhere on the board
RXD: JP21.1, U12.2 (RXD)
SCK: J2.6; also elsewhere on the board
SCL: J2.2; also elsewhere on the board
SDA: J2.1; also elsewhere on the board
SW: J3.8; also elsewhere on the board
TXD: JP20.1, U12.30 (TXD)
USB_5V: J5.1 (+5V), U12.19 (VCC)
VBAT: J3.6; also elsewhere on the board
VCC: JP22.1; also elsewhere on the board
VSEC: J3.5; also elsewhere on the board
VSOL: J3.7; also elsewhere on the board
WDI: J3.3; also elsewhere on the board

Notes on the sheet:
Mounting Holes

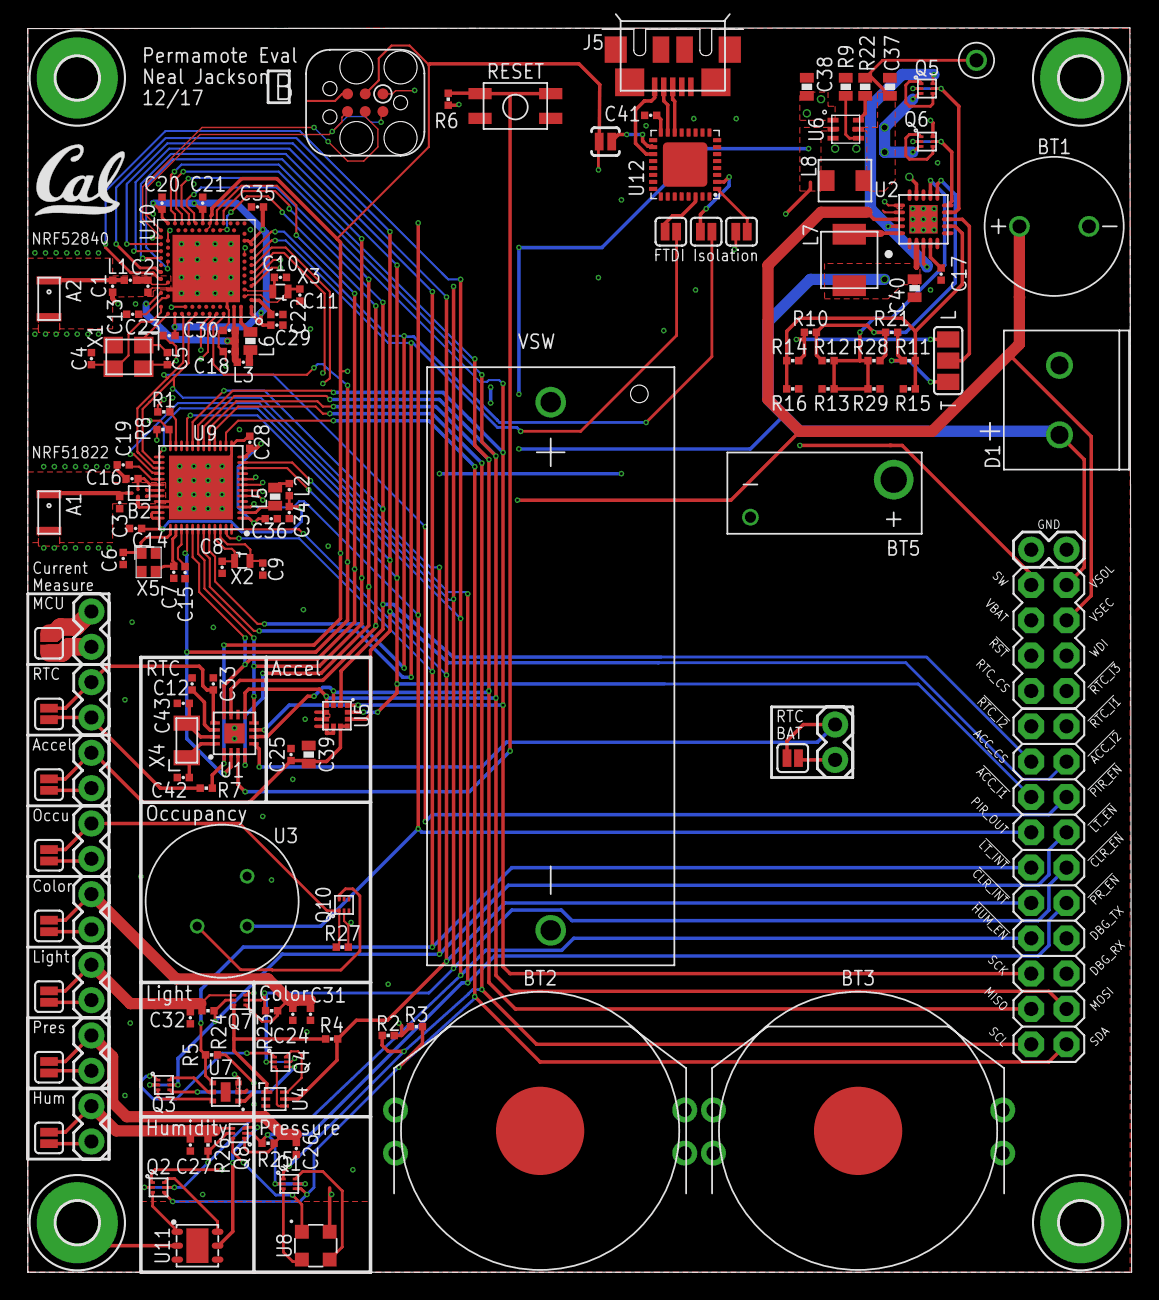
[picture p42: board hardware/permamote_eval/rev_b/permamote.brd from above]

Board: 4 copper layers, 79.4 x 89.5 mm, 145 parts (0 on the bottom side), 106 nets.

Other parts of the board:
U$1: UCB_CAL_200MIL

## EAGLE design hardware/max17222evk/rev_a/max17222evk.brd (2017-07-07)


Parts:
C1, C2, C3, C4: 10uF; 0603_CAP; DIGIKEY 490-3896-2-ND
J1, J2: M023.5MM; SCREWTERMINAL-3.5MM-2; DIGIKEY 277-1721-ND
L1: 1uH; IHL-2525CZ; DIGIKEY 541-2562-1-ND
L2: 1uH; DFE322512C; DIGIKEY 490-10590-1-ND
R1, R2: 80.6k; 0603-RES; DIGIKEY 311-80.6KHRCT-ND
R3, R4: 33M; 0603-RES; DIGIKEY HMC0603JT33M0CT-ND
S1, S2: TE_SSA12/SPDT
TP1, TP2, TP11, TP12: TEST_POINT_0.112IN; TESTPOINT_0.112IN; DIGIKEY 36-1519-2-ND
TP3, TP4, TP5, TP6, TP7, TP8, TP9, TP10, TP13, TP14: TEST_POINT_0.040IN; TESTPOINT_0.040IN
U1, U2: MAX17222; UDFN-6-MAXIM

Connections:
GND: C1.2, C2.2, C3.2, C4.2, J1.1, J2.1, R1.1, R2.1, S1.1 (A), S2.1 (A), TP1.1, TP2.1, TP7.TESTPOINT, TP8.TESTPOINT, TP11.1, TP12.1, U1.3 (GND), U2.3 (GND)
IN1: C1.1, L1.P$1 (1), S1.2 (B), TP5.TESTPOINT, TP10.TESTPOINT, U1.5 (IN)
IN2: C3.1, L2.P$1 (1), S2.2 (B), TP6.TESTPOINT, TP9.TESTPOINT, U2.5 (IN)
unnamed: R3.2, S1.IN
unnamed: R3.1, U1.6 (EN)
unnamed: R4.2, S2.IN
unnamed: R4.1, U2.6 (EN)
unnamed: R1.2, U1.4 (SEL)
unnamed: R2.2, U2.4 (SEL)
SW1: L1.P$2 (2), TP3.TESTPOINT, U1.2 (LX)
SW2: L2.P$2 (2), TP4.TESTPOINT, U2.2 (LX)
VOUT1: C2.1, J1.2, TP13.TESTPOINT, U1.1 (OUT)
VOUT2: C4.1, J2.2, TP14.TESTPOINT, U2.1 (OUT)


Board: 2 copper layers, 50.8 x 76.2 mm, 31 parts (0 on the bottom side), 13 nets.

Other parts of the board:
U$1: UCB_CAL_100MIL

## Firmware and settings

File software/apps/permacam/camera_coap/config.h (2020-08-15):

#define COAP_SERVER_HOSTNAME "coap-test.permamote.com"
#define NTP_SERVER_HOSTNAME "us.pool.ntp.org"
#define UPDATE_SERVER_HOSTNAME "dfu.permamote.com"
#define DNS_SERVER_ADDR "fdaa:bb:1::2"
#define GATEWAY_PARSE_ADDR "lab11.github.io/permamote/gateway/"
#define GATEWAY_DEVICE_TYPE "Permacam"

#define ID_LOCATOR 0x1000

#define DEFAULT_CHILD_TIMEOUT    2*60  /**< Thread child timeout [s]. */
#define DEFAULT_POLL_PERIOD      60000 /**< Thread Sleepy End Device polling period when Asleep. [ms] */
#define DFU_POLL_PERIOD          15
#define RECV_POLL_PERIOD         15    /**< Thread Sleepy End Device polling period when expecting response. [ms] */
#define NUM_SLAAC_ADDRESSES      6     /**< Number of SLAAC addresses. */

#define CAMERA_PERIODIC     false
#define VOLTAGE_PERIOD      5
#define CAMERA_PERIOD       1
#define DISCOVER_PERIOD     15
#define SENSOR_PERIOD       APP_TIMER_TICKS(60*1000)
#define PIR_BACKOFF_PERIOD  APP_TIMER_TICKS(2*60*1000)
#define PIR_DELAY           APP_TIMER_TICKS(10*1000)
#define DFU_MONITOR_PERIOD  APP_TIMER_TICKS(5*1000)
#define COAP_TICK_TIME      APP_TIMER_TICKS(1*1000)
#define NTP_UPDATE_HOURS    1
#define NTP_UPDATE_MAX      5*1000
#define NTP_UPDATE_MIN      2*1000
#define DFU_CHECK_HOURS     24

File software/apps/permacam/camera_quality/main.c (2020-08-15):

#include <stdbool.h>
#include <stdint.h>
#include "nrf.h"
#include "nrf_delay.h"
#include "nrf_sdh.h"
#include "nrf_soc.h"
#include "nrf_gpio.h"
#include "nrf_drv_gpiote.h"
#include "nrf_drv_saadc.h"
#include "nrf_power.h"
#include "nrf_twi_mngr.h"
#include "nrf_log.h"
#include "nrf_log_ctrl.h"
#include "nrf_log_default_backends.h"
#include "nrf_drv_spi.h"
#include "app_timer.h"
#include "app_scheduler.h"

#include <openthread/message.h>
#include <openthread/random_noncrypto.h>
#include "simple_thread.h"
#include "thread_ntp.h"
#include "thread_coap.h"
#include "thread_coap_block.h"
#include "thread_dns.h"
#include "device_id.h"
#include "flash_storage.h"

#include "permacam.h"
#include "gateway_coap.h"

#include "hm01b0.h"
#include "ab1815.h"
#include "max44009.h"
#include "HM01B0_SERIAL_FULL_8bits_msb_5fps.h"

#include "init.h"
#include "config.h"

#include "parse.pb.h"
#include "pb_encode.h"

#include "jpec.h"

APP_TIMER_DEF(camera_timer);
APP_TIMER_DEF(pir_backoff);
APP_TIMER_DEF(pir_delay);
APP_TIMER_DEF(ntp_jitter);

#define SCHED_QUEUE_SIZE 32
#define SCHED_EVENT_DATA_SIZE APP_TIMER_SCHED_EVENT_DATA_SIZE

NRF_TWI_MNGR_DEF(twi_mngr_instance, 5, 0);
static nrf_drv_spi_t spi_instance = NRF_DRV_SPI_INSTANCE(1);

/*
 * Permamote specific declarations for packet structure, state machine
 * ==========================
 * */
typedef struct {
  uint8_t voltage;
  uint8_t camera;
  uint8_t discover;
} permamote_sensor_period_t;
uint32_t period_count = 0;
uint32_t hours_count = 0;

static permamote_sensor_period_t sensor_period = {
  .voltage = VOLTAGE_PERIOD,
  .camera = CAMERA_PERIOD,
};

#define NUM_QUALITIES 7

#define OFFSET 256
static uint8_t image_buffer[HM01B0_RAW_IMAGE_SIZE + OFFSET];

typedef struct{
  uint8_t* buffer;
  uint8_t* raw_image;
  const uint8_t* jpeg;
  uint8_t* jbuffer;
  size_t   len;
  jpec_enc_t* jpeg_state;
  int8_t jpeg_quality;
  uint8_t qualities[NUM_QUALITIES];
  uint8_t current_quality;
  uint16_t current_image_id;
  struct timeval time_sent;
  float exposure;
  float sensed_lux;
  bool send_light;
  bool send_motion;
  bool send_periodic;
  bool sending_pic;
  bool update_time;
  bool update_time_wait;
  bool update_time_done;
  bool resolve_addr;
  bool resolve_wait;
  bool dfu_trigger;
  bool performing_dfu;
  bool do_reset;
} permacam_state_t;

static uint8_t dfu_jitter_hours = 0;
static bool seed = false;
uint8_t device_id[6];
permacam_state_t state = {0};

static block_info b_info = {0};

uint8_t enables[7] = {
   HM01B0_ENn,
   MAX44009_EN,
   PIR_EN,
   I2C_SDA,
   I2C_SCL
};


/*
 * ntp and coap endpoint addresses, to be populated by DNS
 * ========================================================
 * */
static otIp6Address unspecified_ipv6 = {0};
static otIp6Address m_ntp_address;
static otIp6Address m_coap_address;
static otIp6Address m_up_address;
#define NUM_ADDRESSES 3
static otIp6Address* addresses[NUM_ADDRESSES] = {&m_ntp_address, &m_coap_address, &m_up_address};

void send_jpeg();

/*
 * methods to manage addresses
 * ==========================
 * */
static bool are_addresses_resolved(void) {
  bool resolved = true;
  for (size_t i = 0; i < NUM_ADDRESSES; i++) {
    resolved &= !otIp6IsAddressEqual(addresses[i], &unspecified_ipv6);
  }
  return resolved;
}

static void address_print(const otIp6Address *addr)
{
    char ipstr[40];
    snprintf(ipstr, sizeof(ipstr), "%x:%x:%x:%x:%x:%x:%x:%x",
             uint16_big_decode((uint8_t *)(addr->mFields.m16 + 0)),
             uint16_big_decode((uint8_t *)(addr->mFields.m16 + 1)),
             uint16_big_decode((uint8_t *)(addr->mFields.m16 + 2)),
             uint16_big_decode((uint8_t *)(addr->mFields.m16 + 3)),
             uint16_big_decode((uint8_t *)(addr->mFields.m16 + 4)),
             uint16_big_decode((uint8_t *)(addr->mFields.m16 + 5)),
             uint16_big_decode((uint8_t *)(addr->mFields.m16 + 6)),
             uint16_big_decode((uint8_t *)(addr->mFields.m16 + 7)));

    NRF_LOG_INFO("%s\r\n", (uint32_t)ipstr);
}

static void addresses_print(otInstance * aInstance)
{
    for (const otNetifAddress *addr = otIp6GetUnicastAddresses(aInstance); addr; addr = addr->mNext)
    {
        address_print(&addr->mAddress);
    }
}

void take_picture();

static void send_version(void) {
  Message msg = Message_init_default;
  strncpy(msg.data.git_version, GIT_VERSION, sizeof(msg.data.git_version));

  NRF_LOG_INFO("Sent version");

  gateway_coap_send(&m_coap_address, "git_version", false, &msg);
}

static void send_time_diff(struct timeval tv) {
  Message msg = Message_init_default;
  msg.data.time_to_send_s = tv.tv_sec;
  msg.data.time_to_send_us = tv.tv_usec;
  msg.data.image_id = state.current_image_id;
  msg.data.image_jpeg_quality = state.jpeg_quality;
  NRF_LOG_INFO("Time to send: %ld:%d", msg.data.time_to_send_s, msg.data.time_to_send_us);

  gateway_coap_send(&m_coap_address, "time_to_send_image", true, &msg);
}

bool write_jpeg_bytes(pb_ostream_t *stream, const pb_field_t *field, void * const *arg)
{
    if (!pb_encode_tag_for_field(stream, field))
        return false;

    return pb_encode_string(stream, state.jpeg, state.len);
}

bool write_raw_bytes(pb_ostream_t *stream, const pb_field_t *field, void * const *arg)
{
    if (!pb_encode_tag_for_field(stream, field))
        return false;

    return pb_encode_string(stream, state.raw_image, state.len);
}

void __attribute__((weak)) thread_state_changed_callback(uint32_t flags, void * p_context) {
    NRF_LOG_INFO("State changed! Flags: 0x%08lx Current role: %d",
                 flags, otThreadGetDeviceRole(p_context));

    if (flags & OT_CHANGED_IP6_ADDRESS_ADDED && otThreadGetDeviceRole(p_context) == 2) {
      NRF_LOG_INFO("We have internet connectivity!");
      addresses_print(p_context);
      state.update_time = true;
    }
}

void ntp_response_handler(void* context, uint64_t time, otError error) {
  struct timeval tv = {.tv_sec = (uint32_t)time & UINT32_MAX};
  if (error == OT_ERROR_NONE) {
    ab1815_set_time(unix_to_ab1815(tv));
    NRF_LOG_INFO("ntp time: %lu.%lu", (uint32_t)time & UINT32_MAX);
  }
  else {
    NRF_LOG_INFO("ntp error: %d", error);
  }
  state.update_time_wait = false;
  state.update_time_done = true;
}

void rtc_callback(void) {
  hours_count++;
  if (hours_count % NTP_UPDATE_HOURS == 0) {
    uint32_t r = rand();
    float jitter = r / (float) RAND_MAX * (NTP_UPDATE_MAX - NTP_UPDATE_MIN) + NTP_UPDATE_MIN;
    NRF_LOG_INFO("jitter: %u", (uint32_t) jitter);
    ret_code_t err_code = app_timer_start(ntp_jitter, APP_TIMER_TICKS(jitter), NULL);
    APP_ERROR_CHECK(err_code);
  }
  if (hours_count % DFU_CHECK_HOURS == dfu_jitter_hours) {
    dfu_jitter_hours = (int)(rand() / (float) RAND_MAX * DFU_CHECK_HOURS);
    NRF_LOG_INFO("jitter: %u", (uint32_t) dfu_jitter_hours);
    NRF_LOG_INFO("going for DFU");
    state.dfu_trigger = true;
  }
}

void ntp_jitter_callback(void* m) {
    state.update_time = true;
}

void periodic_sensor_read_callback(void* m){
    state.send_periodic = true;
}

//void light_sensor_read_callback(float lux) {
//  state.sensed_lux = lux;
//  state.send_light = true;
//}

//void send_light() {
//  Message msg = Message_init_default;
//  float upper = state.sensed_lux + state.sensed_lux * 0.1;
//  float lower = state.sensed_lux - state.sensed_lux * 0.1;
//  NRF_LOG_INFO("Sensed: lux: %u, upper: %u, lower: %u", (uint32_t)state.sensed_lux, (uint32_t)upper, (uint32_t)lower);
//  max44009_set_upper_threshold(upper);
//  max44009_set_lower_threshold(lower);
//
//  msg.data.light_lux = state.sensed_lux;
//  gateway_coap_send(&m_coap_address, "light_lux", false, &msg);
//}

void pir_backoff_callback(void* m) {
  // turn on and wait for stable
  NRF_LOG_INFO("TURN ON PIR");

  nrf_gpio_pin_clear(PIR_EN);
  ret_code_t err_code = app_timer_start(pir_delay, PIR_DELAY, NULL);
  APP_ERROR_CHECK(err_code);

}

static void send_voltage(void) {
  // sense voltage
  Message msg = Message_init_default;

  nrf_saadc_value_t adc_samples[3];
  nrf_drv_saadc_sample_convert(0, adc_samples);
  nrf_drv_saadc_sample_convert(1, adc_samples+1);
  nrf_drv_saadc_sample_convert(2, adc_samples+2);
  msg.data.primary_voltage= 0.6 * 6 * (float)adc_samples[0] / ((1 << 10)-1);
  msg.data.solar_voltage= 0.6 * 6 * (float)adc_samples[1] / ((1 << 10)-1);
  msg.data.secondary_voltage= 0.6 * 6 * (float)adc_samples[2] / ((1 << 10)-1);

  // sense vbat_ok
  msg.data.vbat_ok = nrf_gpio_pin_read(VBAT_OK);

  gateway_coap_send(&m_coap_address, "voltage", false, &msg);

  NRF_LOG_INFO("Sensed voltage: vbat*100: %d, vsol*100: %d, vsec*100: %d", (int32_t)(msg.data.primary_voltage*100), (int32_t)(msg.data.solar_voltage*100), (int32_t)(msg.data.secondary_voltage*100));
  NRF_LOG_INFO("VBAT_OK: %d", msg.data.vbat_ok);
}

void pir_enable_callback(void* m) {
  // enable interrupt
  NRF_LOG_INFO("TURN ON PIR callback");
  nrf_drv_gpiote_in_event_enable(PIR_OUT, 1);
}

void pir_interrupt_callback(nrf_drv_gpiote_pin_t pin, nrf_gpiote_polarity_t action) {
  state.send_motion = true;
}

//void light_interrupt_callback(void) {
//    max44009_schedule_read_lux();
//}

void send_motion() {
  Message msg = Message_init_default;

  // disable interrupt and turn off PIR
  NRF_LOG_INFO("TURN off PIR ");
  nrf_drv_gpiote_in_event_disable(PIR_OUT);
  nrf_gpio_pin_set(PIR_EN);

  ret_code_t err_code = app_timer_start(pir_backoff, PIR_BACKOFF_PERIOD, NULL);
  APP_ERROR_CHECK(err_code);

  NRF_LOG_INFO("Saw motion");
  msg.data.motion = true;

  gateway_coap_send(&m_coap_address, "motion", false, &msg);
}


void timer_init(void) {
  APP_SCHED_INIT(SCHED_EVENT_DATA_SIZE, SCHED_QUEUE_SIZE);
  ret_code_t err_code = app_timer_init();
  APP_ERROR_CHECK(err_code);

  err_code = app_timer_create(&camera_timer, APP_TIMER_MODE_REPEATED, periodic_sensor_read_callback);
  APP_ERROR_CHECK(err_code);
  err_code = app_timer_start(camera_timer, SENSOR_PERIOD, NULL);
  APP_ERROR_CHECK(err_code);

  err_code = app_timer_create(&pir_backoff, APP_TIMER_MODE_SINGLE_SHOT, pir_backoff_callback);
  APP_ERROR_CHECK(err_code);
  err_code = app_timer_create(&pir_delay, APP_TIMER_MODE_SINGLE_SHOT, pir_enable_callback);
  APP_ERROR_CHECK(err_code);
  err_code = app_timer_create(&ntp_jitter, APP_TIMER_MODE_SINGLE_SHOT, ntp_jitter_callback);
  APP_ERROR_CHECK(err_code);
}


void picture_sent_callback(uint8_t code, otError result) {
    NRF_LOG_INFO("DONE!");

    // send a "time_to_send" packet
    struct timeval done_time = ab1815_get_time_unix();
    NRF_LOG_INFO("sent time: %ld:%d", state.time_sent.tv_sec, state.time_sent.tv_usec);
    NRF_LOG_INFO("done time: %ld:%d", done_time.tv_sec, done_time.tv_usec);
    struct timeval time_diff;
    time_diff.tv_sec = done_time.tv_sec - state.time_sent.tv_sec;
    int64_t diff_usec = done_time.tv_usec - state.time_sent.tv_usec;
    if (diff_usec >= 0) {
      time_diff.tv_usec = done_time.tv_usec - state.time_sent.tv_usec;
    } else {
      if (done_time.tv_sec >= 1) {
        time_diff.tv_sec--;
        diff_usec += 1000000;
        time_diff.tv_usec = diff_usec;
      } else {
        time_diff.tv_usec = 0;
      }
    }
    memset(&state.time_sent, 0, sizeof(struct timeval));
    send_time_diff(time_diff);

    // free state pointers
    if (state.current_quality >= NUM_QUALITIES) {
      NRF_LOG_INFO("SUPER DONE!");
      otLinkSetPollPeriod(thread_get_instance(), DEFAULT_POLL_PERIOD);
      //free(state.buffer);
      //state.buffer = NULL;
      state.raw_image = NULL;
      state.current_quality = 0;
      state.jpeg_quality = state.qualities[0];
      state.sending_pic = false;
      return;
    }

    state.len = 0;
    state.jpeg_quality = state.qualities[state.current_quality++];

    if (state.current_quality >= NUM_QUALITIES) {
      // send raw!
#ifdef DOWNSAMPLE
      state.len = 160*160;
#else
      state.len = HM01B0_FULL_FRAME_IMAGE_SIZE;
#endif
      NRF_LOG_INFO("SEND RAW");
      NRF_LOG_INFO("raw: location %x, size %x", state.raw_image, state.len);
      static Message msg = Message_init_default;
      pb_callback_t callback;
      callback.funcs.encode = write_raw_bytes;
      msg.data.image_raw = callback;
      msg.data.image_ev = 0;
      msg.data.image_exposure_time = state.exposure;
      msg.data.image_id = state.current_image_id;
      msg.data.image_is_demosaiced = false;

      memset(&b_info, 0, sizeof(b_info));

      const char* path = "image_raw";
      memcpy(b_info.path, path, strnlen(path, sizeof(b_info.path)));
      b_info.data_len = state.len;
      b_info.code = OT_COAP_CODE_PUT;
      b_info.block_size = OT_COAP_BLOCK_SIZE_512;
      b_info.etag = otRandomNonCryptoGetUint32();

      state.time_sent = ab1815_get_time_unix();
      otLinkSetPollPeriod(thread_get_instance(), RECV_POLL_PERIOD);
      int error = gateway_coap_block_send(&m_coap_address, &b_info, &msg, picture_sent_callback, state.buffer);
      APP_ERROR_CHECK(error);
    }
    else {
      send_jpeg();
    }
}

void send_jpeg() {
    // Compress and encode as jpeg
    NRF_LOG_INFO("JPEG COMPRESS");
    NRF_LOG_INFO("SEND JPEG IMAGE, quality: %d", state.jpeg_quality);
#ifdef DOWNSAMPLE
    state.jpeg_state = jpec_enc_new2(state.raw_image, 160, 160, state.jpeg_quality);
#else
    state.jpeg_state = jpec_enc_new2(state.raw_image, 320, 320, state.jpeg_quality);
#endif
    state.jpeg = jpec_enc_run(state.jpeg_state, (int*) &state.len);
    state.jbuffer = realloc(state.jpeg, state.len+256);
    state.jpeg = memmove(state.jpeg + 256, state.jpeg, state.len);

    NRF_LOG_INFO("jpeg: location %x, size %x", state.jpeg, state.len);

    // Send picture to endpoint
    state.sending_pic = true;
    static Message msg = Message_init_default;
    pb_callback_t callback;
    callback.funcs.encode = write_jpeg_bytes;
    msg.data.image_jpeg = callback;
    msg.data.image_jpeg_quality = state.jpeg_quality;
    msg.data.image_ev = 0;
    msg.data.image_exposure_time = state.exposure;
    msg.data.image_id = state.current_image_id;
    msg.data.image_is_demosaiced = false;

    memset(&b_info, 0, sizeof(b_info));

    const char* raw_path = "image_jpeg";
    memcpy(b_info.path, raw_path, strnlen(raw_path, sizeof(b_info.path)));
    b_info.data_len = state.len;
    b_info.code = OT_COAP_CODE_PUT;
    b_info.block_size = OT_COAP_BLOCK_SIZE_512;
    b_info.etag = otRandomNonCryptoGetUint32();


    state.time_sent = ab1815_get_time_unix();
    otLinkSetPollPeriod(thread_get_instance(), RECV_POLL_PERIOD);
    int error = gateway_coap_block_send(&m_coap_address, &b_info, &msg, picture_sent_callback, state.jbuffer);
    APP_ERROR_CHECK(error);

    jpec_enc_del(state.jpeg_state);
    state.jpeg_state = NULL;
}

void take_picture() {
    int error = NRF_SUCCESS;

    if (state.sending_pic) {
      NRF_LOG_INFO("waiting to finish sending picture");
      return;
    }


    state.raw_image = state.buffer + OFFSET;
    NRF_LOG_INFO("turning on camera");
    NRF_LOG_INFO("address of buffer: %x", state.raw_image);
    NRF_LOG_INFO("size of buffer:    %x", HM01B0_RAW_IMAGE_SIZE);

    nrf_gpio_pin_clear(LED_1);
    hm01b0_power_up();

    error = hm01b0_init_system(sHM01B0InitScript, sizeof(sHM01B0InitScript)/sizeof(hm_script_t));
    NRF_LOG_INFO("error: %d", error);

    error = hm01b0_wait_for_autoexposure();
    if (error == NRF_ERROR_TIMEOUT) {
      NRF_LOG_INFO("AUTO EXPOSURE TIMEOUT");
    }

    uint16_t pck, integration_time;
    hm01b0_get_line_pck_length(&pck);
    hm01b0_get_integration(&integration_time);
    state.exposure = hm01b0_get_exposure_time(integration_time, pck);
    state.current_image_id = otRandomNonCryptoGetUint16();

    error = hm01b0_blocking_read_oneframe(state.raw_image, HM01B0_RAW_IMAGE_SIZE);
    APP_ERROR_CHECK(error);
    //image_buffer = realloc(image_buffer, offset + HM01B0_FULL_FRAME_IMAGE_SIZE);
    //if(!image_buffer) {
    //  NRF_LOG_INFO("failed to reallocate!");
    //  return;
    //}
    nrf_gpio_pin_set(LED_1);
    hm01b0_power_down();
    NRF_LOG_INFO("TOOK PICTURE");

    //if (state.jpeg_quality == 0) {
    //  // Send raw image
    //  NRF_LOG_INFO("SEND RAW IMAGE");
    //  state.buffer = image_buffer;
    //  state.len = HM01B0_FULL_FRAME_IMAGE_SIZE;

    //  msg.data.image_raw = callback;
    //  const char* raw_path = "image_raw";
    //  memcpy(b_info.path, raw_path, strnlen(raw_path, sizeof(b_info.path)));
    //}

#ifdef DOWNSAMPLE
    // downsample to 160x160
    downsample_160(state.raw_image);
#endif
    send_jpeg();
    state.current_quality++;
}
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
int main(void) {
    // Initialize.
    nrf_power_dcdcen_set(1);
    log_init();
    flash_storage_init();
    twi_init(&twi_mngr_instance);
    timer_init();

    sensors_init(&twi_mngr_instance, &spi_instance);

    NRF_LOG_INFO("GIT Version: %s", GIT_VERSION);
    adc_init();
    uint8_t id[6] = {0};
    get_device_id(id);
    // store ID with fds
    define_flash_variable_array(id, device_id, sizeof(id), ID_LOCATOR);
    NRF_LOG_INFO("Device ID: %x:%x:%x:%x:%x:%x", device_id[0], device_id[1],
                device_id[2], device_id[3], device_id[4], device_id[5]);

    //struct timeval start_time = ab1815_get_time_unix();
    // setup thread
    thread_config_t thread_config = {
      .channel = 25,
      .panid = 0xFACE,
      .sed = true,
      .poll_period = DEFAULT_POLL_PERIOD,
      .child_period = DEFAULT_CHILD_TIMEOUT,
      .autocommission = true,
    };
    thread_init(&thread_config);
    thread_coap_client_init(thread_get_instance());
    //struct timeval end_time = ab1815_get_time_unix();
    //float diff_time = end_time.tv_sec - start_time.tv_sec + (float)(end_time.tv_usec - start_time.tv_usec)/1E6;
    //printf("start itime: %lld:%ld\n", start_time.tv_sec, start_time.tv_usec);
    //printf("start etime: %lld:%ld\n", end_time.tv_sec, end_time.tv_usec);
    //printf("init time: %f\n", diff_time);

    // enable interrupts for pir, light sensor
    ret_code_t err_code = app_timer_start(pir_delay, PIR_DELAY, NULL);
    APP_ERROR_CHECK(err_code);
    //max44009_schedule_read_lux();
    //max44009_enable_interrupt();

    state.qualities[0] = 30;
    state.qualities[1] = 50;
    state.qualities[2] = 70;
    state.qualities[3] = 80;
    state.qualities[4] = 90;
    state.qualities[5] = 93;
    state.qualities[6] = 0;
    state.current_quality = 0;
    state.jpeg_quality = state.qualities[0];

    state.buffer = image_buffer;

    // Enter main loop.
    while (1) {
        thread_process();
        app_sched_execute();
        state_step();
        if (NRF_LOG_PROCESS() == false)
        {
          thread_sleep();
        }
    }
}

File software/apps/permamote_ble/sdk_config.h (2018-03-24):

/**
 * Copyright (c) 2017 - 2017, Nordic Semiconductor ASA
 *
 * All rights reserved.
 *
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
 * 3. Neither the name of Nordic Semiconductor ASA nor the names of its
 *    contributors may be used to endorse or promote products derived from this
 *    software without specific prior written permission.
 *
 * 4. This software, with or without modification, must only be used with a
 *    Nordic Semiconductor ASA integrated circuit.
 *
 * 5. Any software provided in binary form under this license must not be reverse
 *    engineered, decompiled, modified and/or disassembled.
 *
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
 */



#ifndef SDK_CONFIG_H
#define SDK_CONFIG_H
// <<< Use Configuration Wizard in Context Menu >>>\n
#ifdef USE_APP_CONFIG
#include "app_config.h"
#endif
// <h> Board Support

//==========================================================
// <q> BSP_BTN_BLE_ENABLED  - bsp_btn_ble - Button Control for BLE


#ifndef BSP_BTN_BLE_ENABLED
#define BSP_BTN_BLE_ENABLED 0
#endif

// </h>
//==========================================================

// <h> nRF_ANT

//==========================================================
// <e> ANTFS_ENABLED - ant_fs - ANT File Share module.
//==========================================================
#ifndef ANTFS_ENABLED
#define ANTFS_ENABLED 0
#endif
// <o> ANTFS_CONFIG_NETWORK_NUMBER - ANT-FS network number.
#ifndef ANTFS_CONFIG_NETWORK_NUMBER
#define ANTFS_CONFIG_NETWORK_NUMBER 0
#endif

// <o> ANTFS_CONFIG_CHANNEL_NUMBER - ANT-FS channel number.
#ifndef ANTFS_CONFIG_CHANNEL_NUMBER
#define ANTFS_CONFIG_CHANNEL_NUMBER 0
#endif

// <o> ANTFS_CONFIG_PAIRING_TIMEOUT - Pairing timeout - how long the UI will wait for a response to a pairing request before switching to the link layer, in seconds.
#ifndef ANTFS_CONFIG_PAIRING_TIMEOUT
#define ANTFS_CONFIG_PAIRING_TIMEOUT 120
#endif

// <o> ANTFS_CONFIG_LINK_COMMAND_TIMEOUT - Command timeout - how long the client will wait without receiving any commands before switching to the link layer, in seconds.
#ifndef ANTFS_CONFIG_LINK_COMMAND_TIMEOUT
#define ANTFS_CONFIG_LINK_COMMAND_TIMEOUT 10
#endif

// <o> ANTFS_CONFIG_TRANS_TYPE - ANT-FS Transmission Type.
#ifndef ANTFS_CONFIG_TRANS_TYPE
#define ANTFS_CONFIG_TRANS_TYPE 10
#endif

// <o> ANTFS_CONFIG_DEVICE_TYPE - ANT device type for channel configuration.
#ifndef ANTFS_CONFIG_DEVICE_TYPE
#define ANTFS_CONFIG_DEVICE_TYPE 1
#endif

// <o> ANTFS_CONFIG_BEACON_STATUS_PERIOD  - ANT-FS Beacon Message Period.

// <0=> 0.5 Hz
// <1=> 1 Hz
// <2=> 2 Hz
// <3=> 4 Hz
// <4=> 8 Hz

#ifndef ANTFS_CONFIG_BEACON_STATUS_PERIOD
#define ANTFS_CONFIG_BEACON_STATUS_PERIOD 3
#endif

// <o> ANTFS_CONFIG_TRANSMIT_POWER  - ANT Transmit Power.

// <0=> Lowest ANT Tx power level setting. (-20dBm)
// <1=> ANT Tx power > Lvl 0. (-12dBm)
// <2=> ANT Tx power > Lvl 1. (-4dBm)
// <3=> ANT Tx power > Lvl 2. Default tx power level. (0dBm)
// <4=> ANT Tx power > Lvl 3. (+4dBm)
// <128=> Custom tx power selection

#ifndef ANTFS_CONFIG_TRANSMIT_POWER
#define ANTFS_CONFIG_TRANSMIT_POWER 3
#endif

// <o> ANTFS_CONFIG_CUSTOM_TRANSMIT_POWER - ANT Custom Transmit Power.
#ifndef ANTFS_CONFIG_CUSTOM_TRANSMIT_POWER
#define ANTFS_CONFIG_CUSTOM_TRANSMIT_POWER 0
#endif

// <q> ANTFS_CONFIG_AUTH_TYPE_PAIRING_ENABLED  - Use pairing and key exchange authentication.


#ifndef ANTFS_CONFIG_AUTH_TYPE_PAIRING_ENABLED
#define ANTFS_CONFIG_AUTH_TYPE_PAIRING_ENABLED 0
#endif

// <q> ANTFS_CONFIG_AUTH_TYPE_PASSKEY_ENABLED  - Use passkey authentication.


#ifndef ANTFS_CONFIG_AUTH_TYPE_PASSKEY_ENABLED
#define ANTFS_CONFIG_AUTH_TYPE_PASSKEY_ENABLED 0
#endif

// <q> ANTFS_CONFIG_AUTH_TYPE_PASSTHROUGH_ENABLED  - Allow host to bypass authentication.


#ifndef ANTFS_CONFIG_AUTH_TYPE_PASSTHROUGH_ENABLED
#define ANTFS_CONFIG_AUTH_TYPE_PASSTHROUGH_ENABLED 0
#endif

// <q> ANTFS_CONFIG_UPLOAD_ENABLED  - Support upload operation.


#ifndef ANTFS_CONFIG_UPLOAD_ENABLED
#define ANTFS_CONFIG_UPLOAD_ENABLED 0
#endif

// <q> ANTFS_CONFIG_DEBUG_LED_ENABLED  - Enables LED debug in the module.


#ifndef ANTFS_CONFIG_DEBUG_LED_ENABLED
#define ANTFS_CONFIG_DEBUG_LED_ENABLED 0
#endif

// </e>

// <e> ANT_BPWR_ENABLED - ant_bpwr - Bicycle Power Profile
//==========================================================
#ifndef ANT_BPWR_ENABLED
#define ANT_BPWR_ENABLED 0
#endif
// <e> ANT_BPWR_LOG_ENABLED - Enables general logging in the module.
//==========================================================
#ifndef ANT_BPWR_LOG_ENABLED
#define ANT_BPWR_LOG_ENABLED 0
#endif
// <o> ANT_BPWR_LOG_LEVEL  - Default Severity level

// <0=> Off
// <1=> Error
// <2=> Warning
// <3=> Info
// <4=> Debug

#ifndef ANT_BPWR_LOG_LEVEL
#define ANT_BPWR_LOG_LEVEL 3
#endif

// <o> ANT_BPWR_INFO_COLOR  - ANSI escape code prefix.

// <0=> Default
// <1=> Black
// <2=> Red
// <3=> Green
// <4=> Yellow
// <5=> Blue
// <6=> Magenta
// <7=> Cyan
// <8=> White

#ifndef ANT_BPWR_INFO_COLOR
#define ANT_BPWR_INFO_COLOR 0
#endif

// </e>
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

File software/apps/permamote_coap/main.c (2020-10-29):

#include <stdbool.h>
#include <stdint.h>
#include <stdio.h>
#include <string.h>
#include <stdlib.h>

#include "nrf.h"
#include "nrf_gpio.h"
#include "nrf_delay.h"
#include "nrf_twi_mngr.h"
#include "nrf_drv_spi.h"
#include "app_util_platform.h"
#include "nordic_common.h"
#include "app_timer.h"
#include "mem_manager.h"
#include "nrf_drv_clock.h"
#include "nrf_drv_gpiote.h"
#include "nrf_drv_saadc.h"
#include "nrf_power.h"
#include "nrf_log.h"
#include "nrf_log_ctrl.h"
#include "nrf_log_default_backends.h"
#include "nrf_dfu_utils.h"
#include "nrf_dfu_settings.h"
#include "coap_dfu.h"
#include "coap_api.h"
#include "background_dfu_state.h"
#include "fds.h"

#include <openthread/message.h>

#include "simple_thread.h"
#include "thread_ntp.h"
#include "gateway_coap.h"
#include "thread_coap.h"
#include "thread_dns.h"
#include "device_id.h"
#include "flash_storage.h"

#include "permamote.h"
#include "parse.pb.h"
#include "ab1815.h"
#include "max44009.h"
#include "ms5637.h"
#include "si7021.h"
#include "tcs34725.h"

#include "init.h"
#include "callbacks.h"
#include "config.h"

/*
 * ntp and coap endpoint addresses, to be populated by DNS
 * ========================================================
 * */
static otIp6Address unspecified_ipv6;
static otIp6Address m_ntp_address;
static otIp6Address m_coap_address;
static otIp6Address m_up_address;
#define NUM_ADDRESSES 3
static otIp6Address* addresses[NUM_ADDRESSES] = {&m_ntp_address, &m_coap_address, &m_up_address};
static bool addr_fail[NUM_ADDRESSES] = {0};

/*
 * Permamote specific declarations for packet structure, state machine
 * ==========================
 * */
typedef struct {
  uint8_t voltage;
  uint8_t temp_pres_hum;
  uint8_t color;
  uint8_t discover;
} permamote_sensor_period_t;
uint32_t period_count = 0;
uint32_t hours_count = 0;

static permamote_sensor_period_t sensor_period = {
  .voltage = VOLTAGE_PERIOD,
  .temp_pres_hum = TPH_PERIOD,
  .color = COLOR_PERIOD,
  .discover = DISCOVER_PERIOD,
};

typedef struct{
  bool send_light;
  bool send_motion;
  bool send_periodic;
  bool update_time;
  bool up_time_wait;
  bool resolve_addr;
  bool resolve_wait;
  bool dfu_trigger;
  bool performing_dfu;
  bool do_reset;
  bool has_internet;
  bool external_route_added;
  uint16_t offline_count;
} permamote_state_t;

APP_TIMER_DEF(periodic_sensor_timer);
APP_TIMER_DEF(pir_backoff);
APP_TIMER_DEF(pir_delay);
APP_TIMER_DEF(ntp_jitter);
APP_TIMER_DEF(dfu_monitor);
APP_TIMER_DEF(dns_delay);
APP_TIMER_DEF(coap_tick);

static uint8_t dfu_jitter_hours = 0;
static bool seed = false;
uint8_t device_id[6];
static permamote_state_t state = {0};
static float sensed_lux;

// forward declaration
static void send_thread_info(void);
static void send_version(void);

NRF_TWI_MNGR_DEF(twi_mngr_instance, 5, 0);
static nrf_drv_spi_t spi_instance = NRF_DRV_SPI_INSTANCE(1);

/*
 * methods to manage addresses
 * ==========================
 * */
static bool are_addresses_resolved(void) {
  bool resolved = true;
  for (size_t i = 0; i < NUM_ADDRESSES; i++) {
    resolved &= !otIp6IsAddressEqual(addresses[i], &unspecified_ipv6);
  }
  return resolved;
}

static bool did_resolution_fail(void) {
  bool resolved = false;
  for (size_t i = 0; i < NUM_ADDRESSES; i++) {
    resolved |= addr_fail[i];
  }
  return resolved;
}

static void address_print(const otIp6Address *addr)
{
    char ipstr[40];
    snprintf(ipstr, sizeof(ipstr), "%x:%x:%x:%x:%x:%x:%x:%x",
             uint16_big_decode((uint8_t *)(addr->mFields.m16 + 0)),
             uint16_big_decode((uint8_t *)(addr->mFields.m16 + 1)),
             uint16_big_decode((uint8_t *)(addr->mFields.m16 + 2)),
             uint16_big_decode((uint8_t *)(addr->mFields.m16 + 3)),
             uint16_big_decode((uint8_t *)(addr->mFields.m16 + 4)),
             uint16_big_decode((uint8_t *)(addr->mFields.m16 + 5)),
             uint16_big_decode((uint8_t *)(addr->mFields.m16 + 6)),
             uint16_big_decode((uint8_t *)(addr->mFields.m16 + 7)));

    NRF_LOG_INFO("%s\r\n", (uint32_t)ipstr);
}

static void addresses_print(otInstance * aInstance)
{
    for (const otNetifAddress *addr = otIp6GetUnicastAddresses(aInstance); addr; addr = addr->mNext)
    {
        address_print(&addr->mAddress);
    }
}

void coap_dfu_handle_error(void)
{
    coap_dfu_reset_state();
    nrf_dfu_settings_progress_reset();
}

// Function for handling CoAP periodically time ticks.
static void app_coap_time_tick(void* m)
{
    // Pass a tick to coap in order to re-transmit any pending messages.
    (void)coap_time_tick();
}

void dfu_monitor_callback(void* m) {
  background_dfu_diagnostic_t dfu_state;
  coap_dfu_diagnostic_get(&dfu_state);
  NRF_LOG_INFO("state: %s", background_dfu_state_to_string(dfu_state.state));
  NRF_LOG_INFO("prev state: %s", background_dfu_state_to_string(dfu_state.prev_state));

  // if this state combination, there isn't a new image for us, or server not
  // responding, so return to normal operation
  if ((dfu_state.state == BACKGROUND_DFU_DOWNLOAD_TRIG || dfu_state.state == BACKGROUND_DFU_IDLE) &&
      (dfu_state.prev_state == BACKGROUND_DFU_IDLE)) {
    state.performing_dfu = false;
    //app_timer_stop(coap_tick);
    coap_dfu_reset_state();
    nrf_dfu_settings_progress_reset();
    app_timer_stop(dfu_monitor);
    NRF_LOG_INFO("Aborted DFU operation: Image already installed or server not responding");
  }
}

void rtc_callback(void) {
  hours_count++;
  if (hours_count % NTP_UPDATE_HOURS == 0) {
    uint32_t r = rand();
    float jitter = r / (float) RAND_MAX * (NTP_UPDATE_MAX - NTP_UPDATE_MIN) + NTP_UPDATE_MIN;
    NRF_LOG_INFO("jitter: %u", (uint32_t) jitter);
    ret_code_t err_code = app_timer_start(ntp_jitter, APP_TIMER_TICKS(jitter), NULL);
    APP_ERROR_CHECK(err_code);
  }
  if (hours_count % DFU_CHECK_HOURS == dfu_jitter_hours) {
    dfu_jitter_hours = (int)(rand() / (float) RAND_MAX * DFU_CHECK_HOURS);
    NRF_LOG_INFO("jitter: %u", (uint32_t) dfu_jitter_hours);
    NRF_LOG_INFO("going for DFU");
    state.dfu_trigger = true;
  }
}

void ntp_jitter_callback(void* m) {
    state.resolve_addr = true;
    state.update_time = true;
}

void __attribute__((weak)) dns_response_handler(void         * p_context,
                                 const char   * p_hostname,
                                 const otIp6Address * p_resolved_address,
                                 uint32_t       ttl,
                                 otError        error)
{
    uint8_t i = 0;
    for(i=0; i < NUM_ADDRESSES; i++) {
      if (p_context == addresses[i]) {
        break;
      }
    }
    addr_fail[i] = error != OT_ERROR_NONE;

    if (error != OT_ERROR_NONE)
    {
        NRF_LOG_INFO("DNS response error %d.", error);
        return;
    }

    NRF_LOG_INFO("Successfully resolved address");
    memcpy(p_context, p_resolved_address, sizeof(otIp6Address));
}
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

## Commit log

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2017-07-05 added initial schematic and board
    [max17222evk.brd, max17222evk.sch]
2017-07-05 added a first layout for one of the regulators
    [max17222evk.brd]
2017-07-05 routed board, flipped load screw terminals
    [max17222evk.brd, max17222evk.sch]
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2017-07-06 added resistor to enable line
    I believe this is necessary for lower power operation.
    It is in maxim's EVK
    [max17222evk.brd, max17222evk.sch]
2017-07-07 added mounting holes, fixed switch
    [max17222evk.brd, max17222evk.sch]
2017-07-07 added part numbers and associated BOM
    [max17222evk.brd, max17222evk.sch, max17222evk_bom.csv]
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2017-08-01 Fill out sweep
    Fix some simulation, add more printing
2017-09-17 initial rev a commit
    [mote.brd, mote.sch]
2017-09-17 NRF + passives schematic done
    Placement on board and preliminary routing
    [mote.brd, mote.sch]
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2017-09-22 Add start of source switching
    [mote.brd, mote.sch]
2017-09-27 finish power supply, rtc
    [mote.brd, mote.sch]
2017-09-28 Schematized sensors and cleaned up
    [mote.brd, mote.sch]
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2017-09-28 made changes from josh
    [mote.brd, mote.sch]
2017-09-28 Do undervoltage check in software
    [mote.brd, mote.sch]
2017-09-29 Connect all gpio, add pir
    [mote.brd, mote.sch]
2017-09-29 use mppt front end
    [mote.brd, mote.sch]
2017-09-29 add component values for mppt
    [mote.brd, mote.sch]
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2017-10-17 Fix some issues from design review
    See #1
    adc to vsw
    reverse power gate fets
    decoup caps before fet
    pullups on interrupts
    gate i2c
    enable dc-dc mode for dcc
    [mote.brd, mote.sch]
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2017-10-18 route signals out of mcu
    [mote.brd, mote.sch]
2017-10-19 finished most of front end
    [mote.brd]
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2017-10-19 rearrange and combine power ics
    [mote.brd]
2017-10-21 Connect up nrf51822, wire up sensors
    [mote.brd, mote.sch]
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2017-10-24 Rearrange sensors, current measurement
    Ready for signal routing!
    [mote.brd, mote.sch]
2017-10-24 Route I2C, sensor power pins
    [mote.brd, mote.sch]
2017-10-27 Majority of signals routed
    [mote.brd, mote.sch]
2017-10-27 Power trace routed, few airwires left
    [mote.brd]
2017-10-27 run DRC, fixes
    [mote.brd]
2017-10-27 Nothing to do! All signals routed
    [mote.brd, mote.sch]
2017-10-27 Add external reset button
    [mote.brd, mote.sch]
2017-10-28 Branden's fixes
    [mote.brd, mote.sch]
2017-10-29 Add pfet for i2c isolation per sensor
    [mote.brd, mote.sch]
2017-10-29 fix up schematic for bom creation
    [mote.brd, mote.sch]
2017-10-30 Ran the script, sent to fab
    [mote.brd, mote.sch, mote_bom.csv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]
2017-11-08 Add start of test app
    UART printf works, I2C is not working
    [main.c, permamote.h, sdk_config.h]
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2017-11-15 added bq25505 to schematic for next revision
    [mote.brd, mote.sch]
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2017-11-17 fixed bq dividers, changed inductor
    [permamote.brd, permamote.sch]
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2017-11-19 Fix miso/mosi switch
    [permamote.brd, permamote.sch]
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2017-11-22 fix check for NRF52840
    [permamote.h]
2017-11-29 WIP
    Finish power routing
    [permamote.brd, permamote.sch]
2017-11-29 Rearrange - split into eval and mote
    [mote.brd, mote.sch, mote_bom.csv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]
2017-11-29 Start rev b of eval board
    [permamote.brd, permamote.sch]
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2017-12-02 WIP route test signals + change rtc source
    [permamote.brd, permamote.sch]
2017-12-02 Nothing to do - all airwires routed
    Also fixed paste for NRF52840, attempted to fix keepout/stop layers for
    pfet arrays
    [permamote.brd, permamote.sch]
2017-12-03 Rearrange some labels, notes
    Note that i2c pullups do not need to be populated
    [permamote.brd, permamote.sch]
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2018-01-13 No airwires
    Add testpoints, connect dbg uart tx/rx lines
    [permamote.brd, permamote.sch]
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2018-01-17 Rearrange board to move light sensors to bottom edge
    [permamote.brd, permamote.sch]
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2018-01-18 Sent out for quotes
    [permamote_bom.csv, permamote_bom.xlsx]
2018-01-18 update with turnkey notes
    [permamote_bom.csv, permamote_bom.xlsx]
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2018-01-23 Change attributes to include MPN, fix up BOM
    [permamote.brd, permamote.sch, permamote_bom.xlsx]
2018-01-23 Fix NRF52840 via drill size
    Update BOM
    [permamote.brd, permamote.sch, permamote_bom.csv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]
2018-01-24 rerun with correct drill cam job
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2018-01-31 Smaller silk + fixed outline
    [permamote.brd, permamote.sch]
2018-02-07 Fix orphaned trace
    [permamote.brd]
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2018-03-14 fixed library - add cs pins
    [main.c]
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2018-03-28 Fix secondary capacity bug
    Make sure to account for min/max
    Also start attempt to get finer representation of uptime
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2018-04-08 Fix simulator bug for small capacities
2018-04-27 Start rev b
    Implement most changes from #3
    Need to move coin cell holders up, out of the way of PIR
    [permamote.brd, permamote.sch]
2018-04-30 Move coin cell holder out from under PIR
    Move button/led to debug edge of board
    [permamote.brd, permamote.sch]
2018-04-30 move led even closer to edge
    [permamote.brd]
2018-05-01 fix lux sensor reads
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2018-05-02 added first rev of permamote case
    [IC.SLDPRT, PIR.SLDPRT, battery.SLDPRT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]
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2018-05-09 adding updated STL and part
    [case_top.SLDPRT, case_top.STL]
2018-05-09 cutout instead of light pipes
    [case_top.SLDPRT, case_top.STL, permamote.SLDASM]
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2018-06-15 Switch to TCS34725 color sensor
    [permamote.brd, permamote.sch]
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2018-06-15 clean up vcc/gnd connections
    [permamote.brd]
2018-06-15 add mpn, a few nits
    [permamote.brd, permamote.sch]
2018-06-15 design out for quotes
    [permamote_bom.csv, permamote_bom.xlsx]
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2018-07-17 Update to nrf52840 v1.0 spec
    Add decoupling cap to DEC5
    Change values of RF passives
    mentioned in #3
    [permamote.brd, permamote.sch]
2018-07-18 quote out to quickturn
    [permamote.brd, permamote.sch, permamote_bom.csv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]
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2018-07-23 add part marker to U12
    [permamote.brd, permamote.sch, permamote_bom.csv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]
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2018-07-24 Fixup si7021 driver to use twi mngr
    Add test app to print temp/humidity
    [main.c, sdk_config.h]
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2018-07-25 Move jtag connector to back
    [permamote.brd]
2018-07-25 Add app support for humidity and voltage sensing
    fix humidity and light driver bugs
    [main.c, sdk_config.h]
2018-07-25 Revert "Move jtag connector to back"
    This reverts commit 0289d5f44ae80c2e7a408d73da812219b95e3e35.
    start rev c
    [permamote.brd, permamote.sch, permamote_bom.csv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]
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2018-08-02 Add error handler
    Send coap message to '/error' upon error
    [main.c]
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2018-09-05 Redesign case
    unibody design with clips to hold solar panel above board
    [case_bottom.SLDPRT, case_bottom.STL, case_top.SLDPRT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]
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2018-09-10 fix led count
2018-09-10 Fix length bug in permamote coap layer
    enable permamote coap send in app
    [main.c]
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2018-10-03 use channel 25 for less interference
    [main.c]
2018-10-04 fix up ntp error handling - handle timeout
    fix rtc alarm repeat time setting
    [main.c]
2018-10-06 Change button, fixes #4
    [permamote.brd, permamote.sch]
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2018-12-07 Fix misconfigured WDI pin
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2018-12-11 use dns to resolve coap/ntp addresses
    [main.c]
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2019-01-07 do nothing fix up
    [main.c]
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2019-01-12 Add connect and address resolve to state machine
    [init.c, main.c]
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2019-02-23 Fix miconfiguration of rtc irq pin
    Now sleeps at 1.5uA!
    [init.c, main.c]
2019-02-23 Fix double counted PIR events
    Check dns errors, wait until successful
    [main.c]
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2019-02-25 fix rev number in sch
    [permamote.sch]
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2019-03-08 bootloader not working with new sdk
    [app_config.h, sdk_config.h]
2019-03-12 use openthread sntp + jitter
    [config.h, init.c, main.c]
2019-03-18 Fix url in config, logic in address resolution
    [config.h, main.c]
2019-03-22 Work on bootstrapping problem for flash variable names
    [main.c]
2019-03-25 Add app-level timeout for DFU failure
    Also now check for updates every day (24 hours)
    [config.h, main.c]
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2019-04-12 fix bugs with float storage and update; still have to fix bugs with string update
    [main.c]
2019-04-26 Store Device ID in last bit of flash
    Should fix #6
    Move bootloader back, page for Device ID
2019-04-29 Revert "Store Device ID in last bit of flash"
    This reverts commit 82ddc1ef51e63ed67f2b2c999b8e2f85043278c3.
2019-05-03 Make array saving generic
    Fix some pointer issues - strings were working because they are put into
    flash anyways.
    [main.c]
2019-05-03 add jitter to dfu update
    [main.c]
2019-05-08 Properly use dfu jitter
    [main.c]
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2019-07-03 Update nordic SDK to most recent version (3.1.0)
    Changlog suggests "Fixed background DFU state machine lock-up. The
    problem was visible when Thread IPv6 interface was turned off and then
    turned on in the middle of the DFU process."
    [main.c]
2019-07-07 Add watchdog back in because can't fix dfu bug
    [init.c, main.c]
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2019-07-08 add dfu settings progress reset
    [main.c]
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2019-07-09 Commit rev d
    Only major change is moving button + led. Button was previously
    partially overlapping battery connection
    [permamote.brd, permamote.sch, permamote_bom.csv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]
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2019-07-17 clean and orient design blocks
    [permacam.brd, permacam.sch]
2019-07-17 Route signals on board - no airwires or major drc
    Need to add optional MSP430
    [permacam.brd, permacam.sch]
2019-08-23 Rearrange pin assignments to match board locations
    [permacam.brd, permacam.sch]
2019-09-19 fix printf on permamote
    [app_config.h]
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2019-10-14 Use nanopb instead of protobuf-c
    Update nordic's use of nanopb and patch implementation
    Update permamote app to use protobuf
    Need to fix cloud infrastructure to support protobufs
    Need to figure out platform/version independent way of generating proto
    c code
    [config.h, main.c]
2019-10-22 Use serial data + one vcc at 2.8V
    Need to divide primary cell voltage for sensing
    [permacam.brd, permacam.sch]
2019-10-23 fix exti floating
    [permacam.brd, permacam.sch]
2019-10-23 Fix exti in rev d
    [permamote.brd, permamote.sch]
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2019-10-30 Incorporate branden's suggestions
    Add power switch, need to layout
    [permacam.brd, permacam.sch]
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2019-11-07 Fix BOM errors for resistor + battery
    [permacam.brd, permacam.sch]
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2019-12-14 switch to larger coin cell, new light sensor
    [permamote.brd, permamote.sch]
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2020-01-22 fix board makefile for permamote to exclude camera files
2020-01-22 Add coap + camera application, working together
    Needed to change timer used for camera, as openthread used same timer.
    Fix up interface to camera a little so remains low power - still not
    quite where I want it
    [app_config.h, config.h, main.c]
2020-02-10 Fix some initialization errors for camera api
    [main.c]
2020-02-19 Sending image works!
    Still need to optimize poll period and fix up api for block send
    [app_config.h, config.h, main.c]
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2020-03-06 correctly flatten smaller image
    [main.c]
2020-03-08 Fix memory interface bugs with jpec+interrupt init
    [main.c]
2020-04-05 Fix up a bunch of apps
    [main.c]
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2020-04-28 Add methods to get/set camera gain manually
    Add helper to calculate correct integration setting from desired
    exposure time.
2020-05-15 Fix old gateway api in hdr app
    [main.c]
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2020-06-03 Fix order of coap client initialization
    If DFU init is done first, breaks normal coap responses
    Need to test that DFU still works
    [config.h, main.c]
2020-06-03 Fix board files to support new sdk
    [app_config.h, custom_board.h]
2020-06-19 Fix memory error - reuse jpeg buffer for message
    [main.c]
2020-07-17 Fix flash storage array bug, fix typo in camera script
2020-08-11 Alter state machine to order address resolve + ntp
    First resolve addresses, then try to get time. Also add reboot if
    offline for a day.
    [config.h, main.c]
2020-08-13 don't try to retry resolution on failure
    [main.c]
2020-08-15 fix inverted logic causing long poll period
    [main.c]
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2020-08-16 Clear resolve fail on success
    [main.c]
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

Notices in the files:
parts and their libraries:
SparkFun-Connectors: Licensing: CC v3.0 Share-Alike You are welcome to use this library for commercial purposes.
